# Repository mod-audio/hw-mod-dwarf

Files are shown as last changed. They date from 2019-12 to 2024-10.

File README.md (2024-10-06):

# hw-mod-dwarf

This repository contains the schematics and PCB design files for the MOD Dwarf hardware.

These files were created and can be improved with KiCAD, a free software Electronics CAD which is available at http://www.kicad.org/

This project should work with last revision of KiCad libraries and footprints available at https://github.com/KiCad/

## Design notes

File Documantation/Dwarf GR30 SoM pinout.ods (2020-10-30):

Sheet: GR-30 SoM pinout
Pin | Pin Name | Func1 | Func2 | Func3 | Func4 | Func5 | Drive Strength | Type | Pull
1 | I2C1_SDA | GPIO0_C3 | I2C1_SDA | UART3_RTS_M0 |  |  | 2 | I/O | down
2 | TP_RST | GPIO0_B4 | UART0_CTS |  |  |  | 2 | I/O | up
3 | IR_IN | GPIO0_C1 | UART3_RX_M0 | PWM3 |  |  | 2 | I/O | down
4 | SENSOR_INT | GPIO0_B7 | PWM0 | OTG_DRV |  |  | 2 | I/O | down
5 | PWM1 | GPIO0_C0 | UART3_TX_M0 | PWM1 |  |  | 2 | I/O | down
6 | VCC3V3_LCD
7 | LVDS_TX0N | LVDS_TX0N | MIPI_TX_D0N | LCDC_D11_M1 |  |  |  | A | N/A
8 | LVDS_TX0P | LVDS_TX0P | MIPI_TX_D0P | LCDC_D8_M1 |  |  |  | A | N/A
9 | LVDS_TX1N | LVDS_TX1N | MIPI_TX_D1N | LCDC_D1_M1 |  |  |  | A | N/A
10 | LVDS_TX1P | LVDS_TX1P | MIPI_TX_D1P | LCDC_D10_M1 |  |  |  | A | N/A
11 | LVDS_CLKN | LVDS_CLKN | MIPI_TC_CLKN | LCDC_D4_M1 |  |  |  | A | N/A
12 | LVDS_CLKP | LVDS_CLKP | MIPI_TC_CLKP | LCDC_D3_M1 |  |  |  | A | N/A
13 | LVDS_TX2N | LVDS_TX2N | MIPI_TX_D2N | LCDC_VSYNC_M1 |  |  |  | A | N/A
14 | LVDS_TX2P | LVDS_TX2P | MIPI_TX_D2P | LCDC_D5_M1 |  |  |  | A | N/A
15 | LVDS_TX3N | LVDS_TX3N | MIPI_TX_D3N | LCDC_HSYNC_M1 |  |  |  | A | N/A
16 | LVDS_TX3P | LVDS_TX3P | MIPI_TX_D3P | LCDC_DEN_M1 |  |  |  | A | N/A
17 | LCDC_CLK | GPIO3_A0 | LCDC_CLK |  |  |  | 8 | I/O | down
18 | LCDC_HSYNC | GPIO3_A1 | LCDC_HSYNC | CIF_D0_M1 | I2S2_2CH_MCLK | UART5_RX | 8 | I/O | down
19 | LCDC_VSYNC | GPIO3_A2 | LCDC_VSYNC | CIF_D1_M1 | I2S2_2CH_SCLK | UART5_TX | 8 | I/O | down
20 | LCDC_DEN | GPIO3_A3 | LCDC_DEN_M0 | CIF_D2_M1 | I2S2_2CH_LRCK_TXRX | UART5_CTS | 8 | I/O | down
21 | LCDC_D0 | GPIO3_A4 | LCDC_D0 |  |  |  | 8 | I/O | down
22 | LCDC_D1 | GPIO3_A5 | LCDC_D1_M0 | CIF_D3_M1 | I2S2_2CH_SDI | UART5_RTS | 8 | I/O | down
23 | LCDC_D2 | GPIO3_A6 | LCDC_D2 |  |  |  | 8 | I/O | down
24 | LCDC_D3 | GPIO3_A7 | LCDC_D3_M0 | CIF_D4_M1 | I2S2_2CH_SDO |  | 8 | I/O | down
25 | LCDC_D4 | GPIO3_B0 | LCDC_D4_M0 | CIF_D5_M1 | I2S0_8CH_SDI3 |  | 8 | I/O | down
26 | LCDC_D5 | GPIO3_B1 | LCDC_D5_M0 | CIF_D6_M1 | I2S0_8CH_SDI2 | SPI1_CSN0 | 8 | I/O | down
27 | LCDC_D6 | GPIO3_B2 | LCDC_D6 | SPI1_CSN1 |  |  | 8 | I/O | down
28 | LCDC_D7 | GPIO3_B3 | LCDC_D7 | I2S0_8CH_SDI1 |  |  | 8 | I/O | down
29 | LCDC_D8 | GPIO3_B4 | LCDC_D8_M0 | CIF_D7_M1 | I2S0_8CH_SCLKRX | SPI1_MOSI | 8 | I/O | down
30 | LCDC_D9 | GPIO3_B5 | LCDC_D9_M0 | I2S0_8CH_LRCKRX |  |  | 8 | I/O | down
31 | LCDC_D10 | GPIO3_B6 | LCDC_D10_M0 | CIF_D8_M1 | I2S0_8CH_SDO3 | SPI1_MISO | 8 | I/O | down
32 | LCDC_D11 | GPIO3_B7 | LCDC_D11_M0 | CIF_D9_M1 | I2S0_8CH_SDO2 | SPI1_CLK | 8 | I/O | down
33 | LCDC_D12 | GPIO3_C0 | LCDC_D12 | I2S0_8CH_SDO1 |  |  | 8 | I/O | down
34 | LCDC_D13 | GPIO3_C1 | LCDC_D13 | I2S0_8CH_MCLK |  |  | 8 | I/O | down
35 | LCDC_D14 | GPIO3_C2 | LCDC_D14 | PWM4 | I2S0_8CH_LRCKTX | TDM_FSYNC | 8 | I/O | down
36 | LCDC_D15 | GPIO3_C3 | LCDC_D15 | PWM5 | I2S0_8CH_SCLKTX | TDM_SCLK | 8 | I/O | down
37 | LCDC_D16 | GPIO3_C4 | LCDC_D16 | PWM6 | I2S0_8CH_SDO0 | TDM_SDO | 8 | I/O | down
38 | LCDC_D17 | GPIO3_C5 | LCDC_D17 | PWM7 | I2S0_8CH_SDI0 | TDM_SDI | 8 | I/O | down
39 | LCDC_D18 | GPIO3_C6 | LCDC_D18 | CIF_D10_M1 | PDM_CLK0_M0 |  | 8 | I/O | down
40 | LCDC_D19 | GPIO3_C7 | LCDC_D19 | CIF_D11_M1 | PDM_CLK1 |  | 8 | I/O | down
41 | LCDC_D20 | GPIO3_D0 | LCDC_D20 | CIF_CLKOUT_M1 | PDM_SDI1 |  | 8 | I/O | down
42 | LCDC_D21 | GPIO3_D1 | LCDC_D21 | CIF_VSYNC_M1 | PDM_SDI2 | ISP_PRELIGHT_TRIG | 8 | I/O | down
43 | LCDC_D22 | GPIO3_D2 | LCDC_D22 | CIF_HREF_M1 | PDM_SDI3 | ISP_FLASH_TRIG_OUT | 8 | I/O | down
44 | LCDC_D23 | GPIO3_D3 | LCDC_D23 | CIF_CLKIN_M1 | PDM_SDI0_M0 | ISP_FLASH_TRIG_IN | 8 | I/O | down
45 | GPIO0_B5 | GPIO0_B5 | UART0_RTS | TEST_CLK1 |  |  | 2 | I/O | up
46 | GPIO2_B4 | GPIO2_B4 | CIF_D0_M0 | UART2_TX_M1 |  |  | 2 | I/O | down
47 | GPIO0_A0 | GPIO0_A0 | REF_CLKO |  |  |  | 4 | I/O | down
48 | UART1_CTS | GPIO1_C2 | UART1_CTS |  |  |  | 4 | I/O | up
49 | UART1_RXD | GPIO1_C0 | UART1_RX |  |  |  | 4 | I/O | up
50 | UART1_TXD | GPIO1_C1 | UART1_TX |  |  |  | 4 | I/O | up
51 | UART1_RTS | GPIO1_C3 | UART1_RTS |  |  |  | 4 | I/O | up
52 | CLKOUT_32K | GPIO0_C4 | CLKIO_32K |  |  |  | 2 | I/O | Z
53 | SDIO_D1 | GPIO1_C7 | SDMMC1_D1 |  |  |  | 8 | I/O | up
54 | SDIO_D0 | GPIO1_C6 | SDMMC1_D0 |  |  |  | 8 | I/O | up
55 | SDIO_CLK | GPIO1_C5 | SDMMC1_CLK |  |  |  | 8 | I/O | up
56 | SDIO_CMD | GPIO1_C4 | SDMMC1_CMD |  |  |  | 8 | I/O | up
57 | SDIO_D3 | GPIO1_D1 | SDMMC1_D3 |  |  |  | 8 | I/O | up
58 | SDIO_D2 | GPIO1_D0 | SDMMC1_D2 |  |  |  | 8 | I/O | up
59 | BT_WAKE_HOST | GPIO0_B3 | UART0_RX |  |  |  | 2 | I/O | down
60 | WIFI_WAKE_HOST | GPIO0_B2 | UART0_TX |  |  |  | 2 | I/O | down
61 | HOST_WAKE_BT | GPIO0_A1 |  |  |  |  | 2 | I/O | down
62 | BT_REG_ON | GPIO2_B0 | CIF_VSYNC_M0 |  |  |  | 2 | I/O | down
63 | WIFI_REG_ON | GPIO0_A2 |  |  |  |  | 2 | I/O | down
64 | I2C0_SCL_PMIC | GPIO0_B0 | I2C0_SCL |  |  |  | 2 | I/O | up
65 | I2C0_SDA_PMIC | GPIO0_B1 | I2C0_SDA |  |  |  | 2 | I/O | up
66 | PDM_CLK0 | GPIO3_C6 | LCDC_D18 | CIF_D10_M1 | PDM_CLK0_M0 |  | 8 | I/O | down
67 | I2S1_SDI | GPIO2_C5 | I2S1_2CH_SDI | PDM_SDIO_M1 |  |  | 4 | I/O | down
68 | I2S1_SCLK | GPIO2_C2 | I2S1_2CH__SCLK |  |  |  | 4 | I/O | down
69 | I2S1_MCLK | GPIO2_C3 | I2S1_2CH_MCLK |  |  |  | 4 | I/O | down
70 | I2S1_SDO | GPIO2_C4 | I2S1_2CH_SDO |  |  |  | 4 | I/O | down
71 | I2S1_LRCK | GPIO2_C1 | I2S1_2CH_LRCK_TXRX |  |  |  | 4 | I/O | down
72 | GND
73 | MIC1_IN | audio in 1 |  |  |  |  |  | A | N/A
74 | MIC2_IN | audio in 2 |  |  |  |  |  | A | N/A
75 | SPKRP_OUT | speaker out + |  |  |  |  |  | A | N/A
76 | SPKRN_OUT | speaker out - |  |  |  |  |  | A | N/A
77 | HPL | headphone left |  |  |  |  |  | A | N/A
78 | HP_SNS | headphone GND |  |  |  |  |  | A | N/A
79 | HPR | headphone right |  |  |  |  |  | A | N/A
80 | GND
81 | MIPI_CSI_D3N |  |  |  |  |  | N/A | Camera | N/A
82 | MIPI_CSI_D3P |  |  |  |  |  | N/A | Camera | N/A
83 | MIPI_CSI_D2N |  |  |  |  |  | N/A | Camera | N/A
84 | MIPI_CSI_D2P |  |  |  |  |  | N/A | Camera | N/A
85 | MIPI_CSI_CLKN |  |  |  |  |  | N/A | Camera | N/A
86 | MIPI_CSI_CLKP |  |  |  |  |  | N/A | Camera | N/A
87 | MIPI_CSI_D1P |  |  |  |  |  | N/A | Camera | N/A
88 | MIPI_CSI_D1N |  |  |  |  |  | N/A | Camera | N/A
89 | MIPI_CSI_D0P |  |  |  |  |  | N/A | Camera | N/A
90 | MIPI_CSI_D0N |  |  |  |  |  | N/A | Camera | N/A
91 | CIF_PDN0 | GPIO2_B6 | CIF_D1_M0 | UART2_RX_M1 |  |  | 2 | I/O | up
92 | I2C2_SDA | GPIO2_C0 | CIF_D11_M0 | I2C2_SDA |  |  | 2 | I/O | up
93 | I2C2_SCL | GPIO2_B7 | CIF_D10_M0 | I2C2_SCL |  |  | 2 | I/O | up
94 | MIPI_CLKO | GPIO2_B3 | CIF_CLKO_M0 | CLK_OUT_ETHERNET |  |  | 2 | I/O | down
95 | VCC2V8_DVP
96 | VCC1V8_DVP
97 | MAC_MDC | GPIO2_B1 | CIF_HREF_M0 | RMII_MDC |  |  | 4 | I/O | down
98 | RMII_RST | GPIO2_B5 | PWM2 |  |  |  | 4 | I/O | down
99 | RMII_CLK | GPIO2_B2 | CIF_CLKI_M0 | RMII_CLK |  |  | 4 | I/O | down
100 | RMII_MDIO | GPIO2_A7 | CIF_D9_M0 | RMII_MDIO |  |  | 4 | I/O | down
101 | RMII_RXDV | GPIO2_A6 | CIF_D8_M0 | RMII_RXDV |  |  | 4 | I/O | down
102 | RMII_RXER | GPIO2_A5 | CIF_D7_M0 | RMII_RXER |  |  | 4 | I/O | down
103 | RMII_RXD1 | GPIO2_A4 | CIF_D6_M0 | RMII_RXD1 |  |  | 4 | I/O | down
104 | RMII_TXD1 | GPIO2_A1 | CIF_D3_M0 | RMII_TXD1 |  |  | 4 | I/O | down
105 | RMII_RXD0 | GPIO2_A3 | CIF_D5_M0 | RMII_RXD0 |  |  | 4 | I/O | down
106 | RMII_TXD0 | GPIO2_A2 | CIF_D4_M0 | RMII_TXD0 |  |  | 4 | I/O | down
107 | RMII_TXEN | GPIO2_A0 | CIF_D2_M0 | RMII_TXEN |  |  | 8 | I/O | down
108 | GND
109 | GND
110 | GND
111 | VCC5V0_SYS
112 | VCC5V0_SYS
113 | EXT_EN
114 | VCC5V0_HOST
115 | VCC_RTC
116 | VCC3V3_SYS
117 | VCC3V30_PMU
118 | VCC1V8
119 | OTG_DP
120 | OTG_DM
121 | USB_ID
122 | USB_DET
123 | USB_HOST_DM
124 | USB_HOST_DP
125 | SDMMC0_D2 | GPIO1_D4 | SDMMC0_D2 | UART4_RX | JTAG_TCK |  | 8 | I/O | up
126 | SDMMC0_D3 | GPIO1_D5 | SDMMC0_D3 | UART4_TX | JTAG_TMS |  | 8 | I/O | up
127 | VCC_SD
128 | SDMMC0_CMD | GPIO1_D7 | SDMMC0_CMD | UART4_RTS |  |  | 8 | I/O | up
129 | SDMMC0_CLK | GPIO1_D6 | SDMMC0_CLKO | UART4_CTS | TEST_CLKO |  | 8 | I/O | up
130 | SDMMC0_D0 | GPIO1_D2 | SDMMC0_D0 | UART2_TX_M0 |  |  | 8 | I/O | up
131 | SDMMC0_D1 | GPIO1_D3 | SDMMC0_D1 | UART2_RX_M0 |  |  | 8 | I/O | up
132 | SDMMC0_DET | GPIO0_A3 | SDMMC0_DETN |  |  |  | 8 | I/O | up
133 | FLASH_CS0 | GPIO1_B0 | FLASH_CS0 |  |  |  | 8 | I/O | down
134 | FLASH_CLE | GPIO1_B4 | FLASH_CLE | UART3_CTS_M1 | SPI0_MOSI | I2C3_SDA | 8 | I/O | down
135 | FLASH_WRN | GPIO1_B5 | FLASH_WRN | UART3_RTS_M1 | SPI0_MISO | I2C3_SCL | 8 | I/O | up
136 | FLASH_CS1 | GPIO1_B6 | FLASH_CS1 | UART3_TX_M1 | SPI0_CSN |  | 8 | I/O | up
137 | FLASH_RDN | GPIO1_B7 | FLASH_RDN | UART3_RX_M1 | SPI0_CLK |  | 8 | I/O | up
138 | RESET_KEY
139 | POWER_KEY
140 | ADC2
141 | ADC1
142 | ADC0
143 | TP_INT | GPIO0_A5 |  |  |  |  | 2 | I/O | up
144 | I2C1_SCL | GPIO0_C2 | I2C1_SCL | UART3_CTS_M0 |  |  | 2 | I/O | down
 | Ground
 | Power output
 | Power input

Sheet: Dwarf connections
Pin | Type | Function
PM_LEDS_SDA | I2C | I2C data line, used for UID chip and LED peakmeter IC
PM_LEDS_SCL | I2C | I2C clock line, used for UID chip and LED peakmeter IC
PM_LEDS_OE | GPIO | Ouptut Enable for the peakmeter LED IC
CLI_UART_RX | UART | Command Line interface, Linux debug serial RX
CLI_UART_TX | UART | Command Line interface, Linux debug serial TX
HMI_ISP_ENABLE | GPIO | In System Programmer enable, a GPIO to out the HMI in flashing mode
HMI_ISP_RESET | GPIO | HMI reset pin
HMI_ISP_UART_TX | UART | HMI data serial TX
HMI_ISP_UART_RX | UART | HMI data serial RX
MIDI_UART_TX | UART | MIDI serial TX
MIDI_UART_RX | UART | MIDI serial RX
UBOOT_BUTTON | GPIO | a button that is detected during uboot to boot an alternate mode
POWER_BUTTON | GPIO | an exposed SoM button to trigger the SoM to boot
RESET_BUTTON | GPIO | an exposed SoM button to trigger the SoM to reset
USB_DEV_DET | GPIO | USB device detect, detects if a USB is present
USB_DEV_DN | USB | USB device data negative
USB_DEV_DP | USB | USB device data positive
OUT1_DETECT | GPIO | audio out 1 detect, a pulldown whenever a jack is inserted
OUT2_DETECT | GPIO | audio out 2 detect, a pulldown whenever a jack is inserted
IN1_DETECT | GPIO | audio in 1 detect, a pulldown whenever a jack is inserted
IN2_DETECT | GPIO | audio in 2 detect, a pulldown whenever a jack is inserted
USB_HOST_DRV | GPIO | USB host drive, enables the 5V power line of the USB host
USB_HOST_DN | USB | USB host data negative
USB_HOST_DP | USB | USB host data positive
CHAIN_UART_RE | GPIO | Control chain read enable, enables the CC transmision IC read
CHAIN_UART_RX | UART | Control Chain serial RX
CHAIN_UART_DE | GPIO | Control chain drive enable, enables the CC transmision IC write
CHAIN_UART_TX | UART | Control chain serial TX
CODEC_RESET | GPIO | Resets the audio codec
CODEC_I2C_SCL | I2C | I2C data line, used for codec settings
CODEC_I2C_SDA | I2C | I2C clock line, used for codec settings
CODEC_I2S_MCLK | I2S | I2S master clock line
CODEC_I2S_LRCK | I2S | I2S frame clock
CODEC_I2S_BCLK | I2S | I2S bit clock
CODEC_I2S_SDOUT | I2S | I2S data output
CODEC_I2S_SDIN | I2S | I2S data input
IN1_GC2 | GPIO | GPIO that sets extra gain on input 1
IN1_GC1 | GPIO | GPIO that sets extra gain on input 1
IN2_GC1 | GPIO | GPIO that sets extra gain on input 2
IN2_GC2 | GPIO | GPIO that sets extra gain on input 2
HP_CLOCK | GPIO | headphone driver IC clock for setting the volume
HP_UP/DN | GPIO | headphone driver IC data for setting the volume
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

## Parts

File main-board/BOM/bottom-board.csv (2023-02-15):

Source: | /home/jan/MOD/hw-mod-dwarf/main-board/PCB Source/bottom-board/bottom-board.kicad_sch
Date: | Wed 15 Feb 2023 05:39:18 PM CET
Tool: | Eeschema 6.0.10-86aedd382b~118~ubuntu22.04.1
Generator: | /usr/share/kicad/plugins/bom_csv_grouped_by_value.py
Component Count: | 318
Individual Components:
Item | Qty | Reference(s) | Value | LibPart | Footprint | Datasheet | Field4 | Field5 | Field6 | Field7 | Field8 | MPN | MPN2
 |  | C1 | 100uF | bottom-board-rescue:CP_Small | Capacitor_SMD:CP_Elec_6.3x7.7 |  |  |  |  |  |  | 107SML016M
 |  | C2 | 10uF | bottom-board-rescue:CP_Small | Capacitor_SMD:CP_Elec_4x5.7 |  |  |  |  |  |  | EEE-HB1C100R
 |  | C3 | 1000uF | bottom-board-rescue:CP_Small | Capacitor_SMD:CP_Elec_10x10.5 |  |  |  |  |  |  | UCM1C102MNL1GS
 |  | C4 | 1nF | bottom-board-rescue:C_Small | Capacitor_SMD:C_0603_1608Metric |  |  |  |  |  |  | C0603X7R500-102KNP
 |  | C5 | 100nF | bottom-board-rescue:C_Small | Capacitor_SMD:C_0603_1608Metric |  |  |  |  |  |  | GCM188R71C104KA37D
 |  | C6 | 100nF | bottom-board-rescue:C_Small | Capacitor_SMD:C_0603_1608Metric |  |  |  |  |  |  | GCM188R71C104KA37D
 |  | C7 | 100nF | bottom-board-rescue:C_Small | Capacitor_SMD:C_0603_1608Metric |  |  |  |  |  |  | GCM188R71C104KA37D
 |  | C8 | 10uF | bottom-board-rescue:C_Small-Device | Capacitor_SMD:C_0805_2012Metric |  |  |  |  |  |  | GRM219R61E106KA12D
 |  | C9 | 100nF | bottom-board-rescue:C_Small | Capacitor_SMD:C_0603_1608Metric |  |  |  |  |  |  | GCM188R71C104KA37D
 |  | C10 | 100nF | bottom-board-rescue:C_Small | Capacitor_SMD:C_0603_1608Metric |  |  |  |  |  |  | GCM188R71C104KA37D
 |  | C11 | 100nF | bottom-board-rescue:C_Small | Capacitor_SMD:C_0603_1608Metric |  |  |  |  |  |  | GCM188R71C104KA37D
 |  | C12 | 100nF | bottom-board-rescue:C_Small | Capacitor_SMD:C_0603_1608Metric |  |  |  |  |  |  | GCM188R71C104KA37D
 |  | C13 | 100nF | bottom-board-rescue:C_Small | Capacitor_SMD:C_0603_1608Metric |  |  |  |  |  |  | GCM188R71C104KA37D
 |  | C14 | 100nF | bottom-board-rescue:C_Small | Capacitor_SMD:C_0603_1608Metric |  |  |  |  |  |  | GCM188R71C104KA37D
 |  | C15 | 2.2nF | bottom-board-rescue:C_Small | Capacitor_SMD:C_0603_1608Metric |  |  |  |  |  |  | GRM1885C1H222JA01D
 |  | C16 | 2.2nF | bottom-board-rescue:C_Small | Capacitor_SMD:C_0603_1608Metric |  |  |  |  |  |  | GRM1885C1H222JA01D
 |  | C17 | 100nF | bottom-board-rescue:C_Small | Capacitor_SMD:C_0603_1608Metric |  |  |  |  |  |  | GCM188R71C104KA37D
 |  | C18 | 47uF | bottom-board-rescue:CP_Small | Capacitor_SMD:CP_Elec_5x5.4 |  |  |  |  |  |  | EDK476M016A9DAA
 |  | C19 | 100nF | bottom-board-rescue:C_Small | Capacitor_SMD:C_0603_1608Metric |  |  |  |  |  |  | GCM188R71C104KA37D
 |  | C20 | 10uF | bottom-board-rescue:C_Small | Capacitor_SMD:C_0805_2012Metric |  |  |  |  |  |  | GRM219R61E106KA12D
 |  | C21 | 100pF | bottom-board-rescue:C_Small | Capacitor_SMD:C_0603_1608Metric |  |  |  |  |  |  | C0603C101J3GACTU
 |  | C22 | 100nF | bottom-board-rescue:C_Small | Capacitor_SMD:C_0603_1608Metric |  |  |  |  |  |  | GCM188R71C104KA37D
 |  | C23 | 100pF | bottom-board-rescue:C_Small | Capacitor_SMD:C_0603_1608Metric |  |  |  |  |  |  | C0603C101J3GACTU
 |  | C24 | 1uF | bottom-board-rescue:C_Small | Capacitor_SMD:C_0603_1608Metric |  |  |  |  |  |  | TMK107B7105KA-T
 |  | C25 | 10uF | bottom-board-rescue:C_Small | Capacitor_SMD:C_0805_2012Metric |  |  |  |  |  |  | GRM219R61E106KA12D
 |  | C26 | 1uF | bottom-board-rescue:C_Small | Capacitor_SMD:C_0603_1608Metric |  |  |  |  |  |  | TMK107B7105KA-T
 |  | C27 | 1uF | bottom-board-rescue:C_Small | Capacitor_SMD:C_0603_1608Metric |  |  |  |  |  |  | TMK107B7105KA-T
 |  | C28 | 100pF | bottom-board-rescue:C_Small | Capacitor_SMD:C_0603_1608Metric |  |  |  |  |  |  | C0603C101J3GACTU
 |  | C29 | 100pF | bottom-board-rescue:C_Small | Capacitor_SMD:C_0603_1608Metric |  |  |  |  |  |  | C0603C101J3GACTU
 |  | C30 | 22uF | bottom-board-rescue:C_Small | Capacitor_SMD:C_0805_2012Metric |  |  |  |  |  |  | CL21A226MPQNNNE
 |  | C31 | 100nF | bottom-board-rescue:C_Small | Capacitor_SMD:C_0603_1608Metric |  |  |  |  |  |  | GCM188R71C104KA37D
 |  | C32 | 470uF | bottom-board-rescue:CP_Small | Capacitor_SMD:CP_Elec_8x10.5 |  |  |  |  |  |  | UCW1C471MNL1GS
 |  | C33 | 10uF | bottom-board-rescue:CP_Small | Capacitor_SMD:CP_Elec_4x5.7 |  |  |  |  |  |  | EEE-HB1C100R
 |  | C34 | 10uF | bottom-board-rescue:CP_Small | Capacitor_SMD:CP_Elec_4x5.7 |  |  |  |  |  |  | EEE-HB1C100R
 |  | C35 | 100nF | bottom-board-rescue:C_Small | Capacitor_SMD:C_0603_1608Metric |  |  |  |  |  |  | GCM188R71C104KA37D
 |  | C36 | 100nF | bottom-board-rescue:C_Small | Capacitor_SMD:C_0603_1608Metric |  |  |  |  |  |  | GCM188R71C104KA37D
 |  | C37 | 10uF | bottom-board-rescue:C_Small | Capacitor_SMD:C_0805_2012Metric |  |  |  |  |  |  | GRM219R61E106KA12D
 |  | C38 | 100nF | bottom-board-rescue:C_Small | Capacitor_SMD:C_0603_1608Metric |  |  |  |  |  |  | GCM188R71C104KA37D
 |  | C39 | 100nF | bottom-board-rescue:C_Small | Capacitor_SMD:C_0603_1608Metric |  |  |  |  |  |  | GCM188R71C104KA37D
 |  | C40 | 100pF | bottom-board-rescue:C_Small | Capacitor_SMD:C_0603_1608Metric |  |  |  |  |  |  | C0603C101J3GACTU
 |  | C41 | 10uF | bottom-board-rescue:C_Small | Capacitor_SMD:C_0805_2012Metric |  |  |  |  |  |  | GRM219R61E106KA12D
 |  | C42 | 47uF | bottom-board-rescue:CP_Small | Capacitor_SMD:CP_Elec_5x5.4 |  |  |  |  |  |  | EDK476M016A9DAA
 |  | C43 | 100nF | bottom-board-rescue:C_Small | Capacitor_SMD:C_0603_1608Metric |  |  |  |  |  |  | GCM188R71C104KA37D
 |  | C44 | 100pF | bottom-board-rescue:C_Small | Capacitor_SMD:C_0603_1608Metric |  |  |  |  |  |  | C0603C101J3GACTU
 |  | C45 | 10uF | bottom-board-rescue:C_Small | Capacitor_SMD:C_0805_2012Metric |  |  |  |  |  |  | GRM219R61E106KA12D
 |  | C46 | 100pF | bottom-board-rescue:C_Small | Capacitor_SMD:C_0603_1608Metric |  |  |  |  |  |  | C0603C101J3GACTU
 |  | C47 | 100pF | bottom-board-rescue:C_Small | Capacitor_SMD:C_0603_1608Metric |  |  |  |  |  |  | C0603C101J3GACTU
 |  | C48 | 100nF | bottom-board-rescue:C_Small | Capacitor_SMD:C_0603_1608Metric |  |  |  |  |  |  | GCM188R71C104KA37D
 |  | C49 | 10uF | bottom-board-rescue:C_Small | Capacitor_SMD:C_0805_2012Metric |  |  |  |  |  |  | GRM219R61E106KA12D
 |  | C50 | 100nF | bottom-board-rescue:C_Small | Capacitor_SMD:C_0603_1608Metric |  |  |  |  |  |  | GCM188R71C104KA37D
 |  | C51 | 100nF | bottom-board-rescue:C_Small | Capacitor_SMD:C_0603_1608Metric |  |  |  |  |  |  | GCM188R71C104KA37D
 |  | C52 | 100nF | bottom-board-rescue:C_Small | Capacitor_SMD:C_0603_1608Metric |  |  |  |  |  |  | GCM188R71C104KA37D
 |  | C53 | 100nF | bottom-board-rescue:C_Small | Capacitor_SMD:C_0603_1608Metric |  |  |  |  |  |  | GCM188R71C104KA37D
 |  | C54 | 100nF | bottom-board-rescue:C_Small | Capacitor_SMD:C_0603_1608Metric |  |  |  |  |  |  | GCM188R71C104KA37D
 |  | C55 | 100pF | bottom-board-rescue:C_Small | Capacitor_SMD:C_0603_1608Metric |  |  |  |  |  |  | C0603C101J3GACTU
 |  | C56 | 100pF | bottom-board-rescue:C_Small | Capacitor_SMD:C_0603_1608Metric |  |  |  |  |  |  | C0603C101J3GACTU
 |  | C57 | 47uF | bottom-board-rescue:CP_Small | Capacitor_SMD:CP_Elec_5x5.4 |  |  |  |  |  |  | EDK476M016A9DAA
 |  | C58 | 22uF | bottom-board-rescue:C_Small | Capacitor_SMD:C_0805_2012Metric |  |  |  |  |  |  | CL21A226MPQNNNE
 |  | C59 | 100nF | bottom-board-rescue:C_Small | Capacitor_SMD:C_0603_1608Metric |  |  |  |  |  |  | GCM188R71C104KA37D
 |  | C60 | 100nF | bottom-board-rescue:C_Small | Capacitor_SMD:C_0603_1608Metric |  |  |  |  |  |  | GCM188R71C104KA37D
 |  | C61 | 10uF | bottom-board-rescue:CP_Small | Capacitor_SMD:CP_Elec_4x5.7 |  |  |  |  |  |  | EEE-HB1C100R
 |  | C62 | 100nF | bottom-board-rescue:C_Small | Capacitor_SMD:C_0603_1608Metric |  |  |  |  |  |  | GCM188R71C104KA37D
 |  | C63 | 10uF | bottom-board-rescue:CP_Small | Capacitor_SMD:CP_Elec_4x5.7 |  |  |  |  |  |  | EEE-HB1C100R
 |  | C64 | 10uF | bottom-board-rescue:CP_Small | Capacitor_SMD:CP_Elec_4x5.7 |  |  |  |  |  |  | EEE-HB1C100R
 |  | C65 | 10uF | bottom-board-rescue:CP_Small | Capacitor_SMD:CP_Elec_4x5.7 |  |  |  |  |  |  | EEE-HB1C100R
 |  | C66 | 10uF | bottom-board-rescue:CP_Small | Capacitor_SMD:CP_Elec_4x5.7 |  |  |  |  |  |  | EEE-HB1C100R
 |  | C67 | 10uF | bottom-board-rescue:C_Small | Capacitor_SMD:C_0805_2012Metric |  |  |  |  |  |  | GRM219R61E106KA12D
 |  | C68 | 100nF | bottom-board-rescue:C_Small | Capacitor_SMD:C_0603_1608Metric |  |  |  |  |  |  | GCM188R71C104KA37D
 |  | C69 | 10uF | bottom-board-rescue:C_Small | Capacitor_SMD:C_0805_2012Metric |  |  |  |  |  |  | GRM219R61E106KA12D
 |  | C70 | 100uF | bottom-board-rescue:CP_Small | Capacitor_SMD:CP_Elec_6.3x7.7 |  |  |  |  |  |  | 107SML016M
 |  | C71 | 100uF | bottom-board-rescue:CP_Small | Capacitor_SMD:CP_Elec_6.3x7.7 |  |  |  |  |  |  | 107SML016M
 |  | C72 | 47uF | bottom-board-rescue:CP_Small | Capacitor_SMD:CP_Elec_5x5.4 |  |  |  |  |  |  | EDK476M016A9DAA
 |  | C73 | 100nF | bottom-board-rescue:C_Small | Capacitor_SMD:C_0603_1608Metric |  |  |  |  |  |  | GCM188R71C104KA37D
 |  | C74 | 47uF | bottom-board-rescue:CP_Small | Capacitor_SMD:CP_Elec_5x5.4 |  |  |  |  |  |  | EDK476M016A9DAA
 |  | C75 | 100nF | bottom-board-rescue:C_Small | Capacitor_SMD:C_0603_1608Metric |  |  |  |  |  |  | GCM188R71C104KA37D
 |  | C76 | 10uF | bottom-board-rescue:C_Small | Capacitor_SMD:C_0805_2012Metric |  |  |  |  |  |  | GRM219R61E106KA12D
 |  | C77 | 100nF | bottom-board-rescue:C_Small | Capacitor_SMD:C_0603_1608Metric |  |  |  |  |  |  | GCM188R71C104KA37D
 |  | C78 | 10uF | bottom-board-rescue:C_Small | Capacitor_SMD:C_0805_2012Metric |  |  |  |  |  |  | GRM219R61E106KA12D
 |  | C79 | 100nF | bottom-board-rescue:C_Small | Capacitor_SMD:C_0603_1608Metric |  |  |  |  |  |  | GCM188R71C104KA37D
 |  | C80 | 10uF | bottom-board-rescue:C_Small | Capacitor_SMD:C_0805_2012Metric |  |  |  |  |  |  | GRM219R61E106KA12D
 |  | C81 | 100nF | bottom-board-rescue:C_Small | Capacitor_SMD:C_0603_1608Metric |  |  |  |  |  |  | GCM188R71C104KA37D
 |  | C82 | 100nF | bottom-board-rescue:C_Small | Capacitor_SMD:C_0603_1608Metric |  |  |  |  |  |  | GCM188R71C104KA37D
 |  | C83 | 47uF | bottom-board-rescue:CP_Small | Capacitor_SMD:CP_Elec_5x5.4 |  |  |  |  |  |  | EDK476M016A9DAA
 |  | C84 | 47uF | bottom-board-rescue:CP_Small | Capacitor_SMD:CP_Elec_5x5.4 |  |  |  |  |  |  | EDK476M016A9DAA
 |  | C85 | 100nF | bottom-board-rescue:C_Small | Capacitor_SMD:C_0603_1608Metric |  |  |  |  |  |  | GCM188R71C104KA37D
 |  | C86 | 100nF | bottom-board-rescue:C_Small | Capacitor_SMD:C_0603_1608Metric |  |  |  |  |  |  | GCM188R71C104KA37D
 |  | C87 | 100nF | bottom-board-rescue:C_Small | Capacitor_SMD:C_0603_1608Metric |  |  |  |  |  |  | GCM188R71C104KA37D
 |  | C88 | 10uF | bottom-board-rescue:CP_Small | Capacitor_SMD:CP_Elec_4x5.7 |  |  |  |  |  |  | EEE-HB1C100R
 |  | C89 | 10uF | bottom-board-rescue:CP_Small | Capacitor_SMD:CP_Elec_4x5.7 |  |  |  |  |  |  | EEE-HB1C100R
 |  | C90 | 100pF | bottom-board-rescue:C_Small | Capacitor_SMD:C_0603_1608Metric |  |  |  |  |  |  | C0603C101J3GACTU
 |  | C91 | 100pF | bottom-board-rescue:C_Small | Capacitor_SMD:C_0603_1608Metric |  |  |  |  |  |  | C0603C101J3GACTU
 |  | C92 | 1nF | bottom-board-rescue:C_Small | Capacitor_SMD:C_0603_1608Metric |  |  |  |  |  |  | C0603X7R500-102KNP
 |  | C93 | 1nF | bottom-board-rescue:C_Small | Capacitor_SMD:C_0603_1608Metric |  |  |  |  |  |  | C0603X7R500-102KNP
 |  | C94 | 100nF | bottom-board-rescue:C_Small | Capacitor_SMD:C_0603_1608Metric |  |  |  |  |  |  | DO NOT PLACE
 |  | C95 | 100nF | bottom-board-rescue:C_Small | Capacitor_SMD:C_0603_1608Metric |  |  |  |  |  |  | GCM188R71C104KA37D
 |  | C96 | 10uF | bottom-board-rescue:C_Small | Capacitor_SMD:C_0805_2012Metric |  |  |  |  |  |  | GRM219R61E106KA12D
 |  | C97 | 1uF | bottom-board-rescue:C_Small | Capacitor_SMD:C_0603_1608Metric |  |  |  |  |  |  | TMK107B7105KA-T
 |  | C98 | 100nF | bottom-board-rescue:C_Small | Capacitor_SMD:C_0603_1608Metric |  |  |  |  |  |  | GCM188R71C104KA37D
 |  | C99 | 22uF | bottom-board-rescue:C_Small | Capacitor_SMD:C_0805_2012Metric |  |  |  |  |  |  | CL21A226MPQNNNE
 |  | C100 | 100nF | bottom-board-rescue:C_Small | Capacitor_SMD:C_0603_1608Metric |  |  |  |  |  |  | GCM188R71C104KA37D
 |  | C101 | 22uF | bottom-board-rescue:C_Small | Capacitor_SMD:C_0805_2012Metric |  |  |  |  |  |  | CL21A226MPQNNNE
 |  | C102 | 100nF | bottom-board-rescue:C_Small | Capacitor_SMD:C_0603_1608Metric |  |  |  |  |  |  | GCM188R71C104KA37D
 |  | C103 | 1uF | bottom-board-rescue:C_Small | Capacitor_SMD:C_0603_1608Metric |  |  |  |  |  |  | TMK107B7105KA-T
 |  | C104 | 100nF | bottom-board-rescue:C_Small | Capacitor_SMD:C_0603_1608Metric |  |  |  |  |  |  | GCM188R71C104KA37D
 |  | C105 | 1uF | bottom-board-rescue:C_Small | Capacitor_SMD:C_0603_1608Metric |  |  |  |  |  |  | TMK107B7105KA-T
 |  | C106 | 100nF | bottom-board-rescue:C_Small | Capacitor_SMD:C_0603_1608Metric |  |  |  |  |  |  | GCM188R71C104KA37D
 |  | C107 | 1000uF | bottom-board-rescue:CP_Small | Capacitor_SMD:CP_Elec_10x10.5 |  |  |  |  |  |  | UCM1C102MNL1GS
 |  | C108 | 1nF | bottom-board-rescue:C_Small | Capacitor_SMD:C_0603_1608Metric |  |  |  |  |  |  | C0603X7R500-102KNP
 |  | C109 | 100nF | bottom-board-rescue:C_Small-Device | Capacitor_SMD:C_0603_1608Metric |  |  |  |  |  |  | GCM188R71C104KA37D
 |  | C110 | 10uF | bottom-board-rescue:C_Small-Device | Capacitor_SMD:C_0805_2012Metric |  |  |  |  |  |  | GRM219R61E106KA12D
 |  | C111 | 1uF | bottom-board-rescue:C_Small | Capacitor_SMD:C_1210_3225Metric |  |  |  |  |  |  | FCA1210C105M-G2
 |  | C112 | 1uF | bottom-board-rescue:C_Small | Capacitor_SMD:C_1210_3225Metric |  |  |  |  |  |  | FCA1210C105M-G2
 |  | D1 | RSX205LAM30TR | bottom-board-rescue:D_Schottky-Device | Diode_SMD:D_SOD-128 |  |  |  |  |  |  | RSX205LAM30TR
 |  | D2 | RSX205LAM30TR | bottom-board-rescue:D_Schottky-Device | Diode_SMD:D_SOD-128 |  |  |  |  |  |  | RSX205LAM30TR
 |  | D3 | BAT54S | bottom-board-rescue:BAT54S-Diode | Package_TO_SOT_SMD:SOT-23 | https://www.diodes.com/assets/Datasheets/ds11005.pdf |  |  |  |  |  | BAT54SFILM
 |  | D4 | BAT54S | bottom-board-rescue:BAT54S-Diode | Package_TO_SOT_SMD:SOT-23 | https://www.diodes.com/assets/Datasheets/ds11005.pdf |  |  |  |  |  | BAT54SFILM
 |  | D5 | 1N4148 | bottom-board-rescue:1N4148-Diode | Diode_SMD:D_SOD-323_HandSoldering | https://assets.nexperia.com/documents/data-sheet/1N4148_1N4448.pdf |  |  |  |  |  | 1N4148WS
 |  | D6 | 1N4148 | bottom-board-rescue:1N4148-Diode | Diode_SMD:D_SOD-323_HandSoldering | https://assets.nexperia.com/documents/data-sheet/1N4148_1N4448.pdf |  |  |  |  |  | 1N4148WS
 |  | D7 | TSSA3U45 R3G | bottom-board-rescue:D_Shockley-Device | Diode_SMD:D_MELF |  |  |  |  |  |  | TSSA3U45 R3G
 |  | D8 | 1N4148 | bottom-board-rescue:1N4148-Diode | Diode_SMD:D_SOD-323_HandSoldering | https://assets.nexperia.com/documents/data-sheet/1N4148_1N4448.pdf |  |  |  |  |  | 1N4148WS
 |  | D9 | 1N4148 | bottom-board-rescue:1N4148-Diode | Diode_SMD:D_SOD-323_HandSoldering | https://assets.nexperia.com/documents/data-sheet/1N4148_1N4448.pdf |  |  |  |  |  | 1N4148WS
 |  | D10 | BAT54S | bottom-board-rescue:BAT54S-Diode | Package_TO_SOT_SMD:SOT-23 | https://www.diodes.com/assets/Datasheets/ds11005.pdf |  |  |  |  |  | BAT54SFILM
 |  | D11 | BAT54S | bottom-board-rescue:BAT54S-Diode | Package_TO_SOT_SMD:SOT-23 | https://www.diodes.com/assets/Datasheets/ds11005.pdf |  |  |  |  |  | BAT54SFILM
 |  | D12 | BAT54S | bottom-board-rescue:BAT54S-Diode | Package_TO_SOT_SMD:SOT-23 | https://www.diodes.com/assets/Datasheets/ds11005.pdf |  |  |  |  |  | BAT54SFILM
 |  | D13 | PRTR5V0U2X | bottom-board-rescue:PRTR5V0U2X | Package_TO_SOT_SMD:SOT-143 |  |  |  |  |  |  | PRTR5V0U2X,215
 |  | D14 | PRTR5V0U2X | bottom-board-rescue:PRTR5V0U2X | Package_TO_SOT_SMD:SOT-143 |  |  |  |  |  |  | PRTR5V0U2X,215
 |  | D15 | 1N4148 | bottom-board-rescue:1N4148-Diode | Diode_SMD:D_SOD-323_HandSoldering | https://assets.nexperia.com/documents/data-sheet/1N4148_1N4448.pdf |  |  |  |  |  | 1N4148WS
 |  | D16 | 1N4148 | bottom-board-rescue:1N4148-Diode | Diode_SMD:D_SOD-323_HandSoldering | https://assets.nexperia.com/documents/data-sheet/1N4148_1N4448.pdf |  |  |  |  |  | 1N4148WS
 |  | D17 | BAT54S | bottom-board-rescue:BAT54S-Diode | Package_TO_SOT_SMD:SOT-23 | https://www.diodes.com/assets/Datasheets/ds11005.pdf |  |  |  |  |  | BAT54SFILM
 |  | D18 | BAT54S | bottom-board-rescue:BAT54S-Diode | Package_TO_SOT_SMD:SOT-23 | https://www.diodes.com/assets/Datasheets/ds11005.pdf |  |  |  |  |  | BAT54SFILM
 |  | D19 | BAT54S | bottom-board-rescue:BAT54S-Diode | Package_TO_SOT_SMD:SOT-23 | https://www.diodes.com/assets/Datasheets/ds11005.pdf |  |  |  |  |  | BAT54SFILM
 |  | D20 | BAT54S | bottom-board-rescue:BAT54S-Diode | Package_TO_SOT_SMD:SOT-23 | https://www.diodes.com/assets/Datasheets/ds11005.pdf |  |  |  |  |  | BAT54SFILM
 |  | D21 | BAT54S | bottom-board-rescue:BAT54S-Diode | Package_TO_SOT_SMD:SOT-23 | https://www.diodes.com/assets/Datasheets/ds11005.pdf |  |  |  |  |  | BAT54SFILM
 |  | D22 | BAT54S | bottom-board-rescue:BAT54S-Diode | Package_TO_SOT_SMD:SOT-23 | https://www.diodes.com/assets/Datasheets/ds11005.pdf |  |  |  |  |  | BAT54SFILM
 |  | F1 | FUSE | bottom-board-rescue:FUSE | Fuse:Fuse_2920_7451Metric |  |  |  |  |  |  | 0ZCF0200FF2C
 |  | FB1 | Ferrite_Bead | bottom-board-rescue:Ferrite_Bead-Device | Resistor_SMD:R_0603_1608Metric |  |  |  |  |  |  | BLM18HD102SH1D
 |  | FB2 | Ferrite_Bead | Device:Ferrite_Bead | Resistor_SMD:R_0603_1608Metric |  |  |  |  |  |  | BLM18HD102SH1D
 |  | FB3 | Ferrite_Bead | Device:Ferrite_Bead | Resistor_SMD:R_0603_1608Metric |  |  |  |  |  |  | BLM18HD102SH1D
 |  | FB12 | Ferrite_Bead | bottom-board-rescue:Ferrite_Bead-Device | Resistor_SMD:R_0603_1608Metric |  |  |  |  |  |  | BLM18HD102SH1D
 |  | FB13 | Ferrite_Bead | bottom-board-rescue:Ferrite_Bead-Device | Resistor_SMD:R_0603_1608Metric |  |  |  |  |  |  | BLM18HD102SH1D
 |  | FB14 | Ferrite_Bead | bottom-board-rescue:Ferrite_Bead-Device | Resistor_SMD:R_0603_1608Metric |  |  |  |  |  |  | BLM18HD102SH1D
 |  | FB15 | Ferrite_Bead | bottom-board-rescue:Ferrite_Bead-Device | Resistor_SMD:R_0603_1608Metric |  |  |  |  |  |  | BLM18HD102SH1D
 |  | FID1 | FIDUCIAL | bottom-board-rescue:FIDUCIAL-local-components | Uno:fiducial_in-circuit
 |  | FID2 | FIDUCIAL | bottom-board-rescue:FIDUCIAL-local-components | Uno:fiducial_in-circuit
 |  | FID3 | FIDUCIAL | bottom-board-rescue:FIDUCIAL-local-components | Uno:fiducial_in-circuit
 |  | H1 | HOLE | bottom-board-rescue:HOLE-local-components | Uno:Hole_3.5mm
 |  | H2 | HOLE | bottom-board-rescue:HOLE-local-components | Uno:Hole_3.5mm
 |  | H3 | HOLE | bottom-board-rescue:HOLE-local-components | Uno:Hole_3.5mm
 |  | H4 | HOLE | bottom-board-rescue:HOLE-local-components | Uno:Hole_3.5mm
 |  | H5 | MountingHole_Pad | bottom-board-rescue:MountingHole_Pad-Mechanical | MountingHole:MountingHole_3.2mm_M3_DIN965_Pad
 |  | H6 | MountingHole_Pad | bottom-board-rescue:MountingHole_Pad-Mechanical | MountingHole:MountingHole_3.2mm_M3_DIN965_Pad |  |  |  |  |  |  | 9774030243R
 |  | H7 | MountingHole_Pad | bottom-board-rescue:MountingHole_Pad-Mechanical | MountingHole:MountingHole_3.2mm_M3_DIN965_Pad |  |  |  |  |  |  | 9774030243R
 |  | J1 | AS0A823-H4SB-7H | bottom-board-rescue:AS0A823-H4SB-7H | Uno:TE_2309409-1 | None | AS0A823-H4SB-7H | AS Series 260 Pin Single Row DDR4 SODIMM Connector | Foxconn | Unavailable | None | TE_2309409-1
 |  | J2 | Conn_01x25 | Connector_Generic:Conn_01x25 | F51L-1A7H1-11024:F51L-1A7H1-11024 | ~ |  |  |  |  |  | F51L-1A7H1-11024
 |  | JP1 | Jumper | bottom-board-rescue:Jumper-Device | Jumper:SolderJumper-2_P1.3mm_Bridged2Bar_RoundedPad1.0x1.5mm
 |  | L1 | 1mH | bottom-board-rescue:INDUCTOR-pspice | Inductor_SMD:L_Bourns_SRR1260 |  |  |  |  |  |  | SRR1260-102K
 |  | L2 | 47UH 2A 135 MOHM | bottom-board-rescue:INDUCTOR-pspice | Uno:SRN8040TA | https://www.digikey.com/product-detail/en/bourns-inc/SRN8040TA-470M/SRN8040TA-470MTR-ND/6155133 |  |  |  |  |  | SRN8040TA-470M
 |  | P1 | USB_B | bottom-board-rescue:USB_B-RESCUE-bottom-board | Connector_USB:USB_B_OST_USB-B1HSxx_Horizontal |  |  |  |  |  |  | 61729-1011BLF
 |  | P2 | USB_A | bottom-board-rescue:USB_A-RESCUE-bottom-board | Uno:USB_A_Vertical |  |  |  |  |  |  | KUSBX-SLAS1N-B
 |  | P3 | BARREL_JACK | bottom-board-rescue:BARREL_JACK | Connector_BarrelJack:BarrelJack_Horizontal |  |  |  |  |  |  | PJ-002AH
 |  | P6 | AudioJack3 | bottom-board-rescue:AudioJack3-Connector | Connector_Audio:Jack_3.5mm_CUI_SJ-3523-SMT_Horizontal |  |  |  |  |  |  | SJ-3523-SMT-TR
 |  | P7 | AudioJack3 | bottom-board-rescue:AudioJack3-Connector | Connector_Audio:Jack_3.5mm_CUI_SJ-3523-SMT_Horizontal |  |  |  |  |  |  | SJ-3523-SMT-TR
 |  | P8 | SERIAL_DEBUG | bottom-board-rescue:CONN_01X03 | Connector_PinHeader_2.54mm:PinHeader_1x03_P2.54mm_Vertical |  |  |  |  |  |  | DO NOT PLACE
 |  | P9 | JACK_TRS_6PINS | bottom-board-rescue:AudioJack3_Switch-Connector | Connector_Audio:Jack_3.5mm_Neutrik_NMJ6HCD2_Horizontal |  |  |  |  |  |  | NYS215
 |  | P10 | JACK_TRS_6PINS | bottom-board-rescue:AudioJack3_Switch-Connector | Connector_Audio:Jack_3.5mm_Neutrik_NMJ6HCD2_Horizontal |  |  |  |  |  |  | NYS215
 |  | P11 | JACK_TRS_6PINS | bottom-board-rescue:AudioJack3_Switch-Connector | Connector_Audio:Jack_3.5mm_Neutrik_NMJ6HCD2_Horizontal |  |  |  |  |  |  | NYS215
 |  | P12 | JACK_TRS_6PINS | bottom-board-rescue:AudioJack3_Switch-Connector | Connector_Audio:Jack_3.5mm_Neutrik_NMJ6HCD2_Horizontal |  |  |  |  |  |  | NYS215
 |  | P13 | RJ45 | bottom-board-rescue:RJ45-Connector | digikey-footprints:Ethernet_Jack_54602-908LF |  |  |  |  |  |  | 54602-908LF
 |  | P14 | AudioJack3 | bottom-board-rescue:AudioJack3-Connector | Connector_Audio:Jack_3.5mm_CUI_SJ-3523-SMT_Horizontal |  |  |  |  |  |  | SJ-3523-SMT-TR
 |  | Power1 | TestPoint | bottom-board-rescue:TestPoint-Connector | TestPoint:TestPoint_Pad_D1.5mm
 |  | Q1 | 2N7002 | bottom-board-rescue:Q_NMOS_GSD | Package_TO_SOT_SMD:SOT-23 |  |  |  |  |  |  | 2N7002P,215
 |  | Q2 | 2N7002 | bottom-board-rescue:Q_NMOS_GSD | Package_TO_SOT_SMD:SOT-23 |  |  |  |  |  |  | 2N7002P,215
 |  | Q3 | MMBFJ211 | bottom-board-rescue:Q_NJFET_DSG | Package_TO_SOT_SMD:SOT-23 |  |  |  |  |  |  | MMBFJ211CT-ND
 |  | Q4 | MMBFJ211 | bottom-board-rescue:Q_NJFET_DSG | Package_TO_SOT_SMD:SOT-23 |  |  |  |  |  |  | MMBFJ211CT-ND
 |  | Q5 | MMBFJ211 | bottom-board-rescue:Q_NJFET_DSG | Package_TO_SOT_SMD:SOT-23 |  |  |  |  |  |  | MMBFJ211CT-ND
 |  | Q6 | MMBFJ211 | bottom-board-rescue:Q_NJFET_DSG | Package_TO_SOT_SMD:SOT-23 |  |  |  |  |  |  | MMBFJ211CT-ND
 |  | Q7 | 2N7002 | bottom-board-rescue:Q_NMOS_GSD | Package_TO_SOT_SMD:SOT-23 |  |  |  |  |  |  | 2N7002P,215
 |  | Q8 | 2N7002 | bottom-board-rescue:Q_NMOS_GSD | Package_TO_SOT_SMD:SOT-23 |  |  |  |  |  |  | 2N7002P,215
 |  | Q9 | MMBFJ211 | bottom-board-rescue:Q_NJFET_DSG | Package_TO_SOT_SMD:SOT-23 |  |  |  |  |  |  | MMBFJ211CT-ND
 |  | Q10 | MMBFJ211 | bottom-board-rescue:Q_NJFET_DSG | Package_TO_SOT_SMD:SOT-23 |  |  |  |  |  |  | MMBFJ211CT-ND
 |  | Q12 | 2N7002 | bottom-board-rescue:Q_NMOS_GSD | Package_TO_SOT_SMD:SOT-23 |  |  |  |  |  |  | 2N7002P,215
 |  | Q13 | 2N7002 | bottom-board-rescue:Q_NMOS_GSD | Package_TO_SOT_SMD:SOT-23 |  |  |  |  |  |  | 2N7002P,215
 |  | R1 | 2K7 | bottom-board-rescue:R_Small | Resistor_SMD:R_0603_1608Metric |  |  |  |  |  |  | CRGCQ0603F2K7
 |  | R2 | 2K7 | bottom-board-rescue:R_Small | Resistor_SMD:R_0603_1608Metric |  |  |  |  |  |  | CRGCQ0603F2K7
 |  | R3 | 22R | bottom-board-rescue:R_Small | Resistor_SMD:R_0603_1608Metric |  |  |  |  |  |  | RMCF0603JT22R0
 |  | R4 | 22R | bottom-board-rescue:R_Small | Resistor_SMD:R_0603_1608Metric |  |  |  |  |  |  | RMCF0603JT22R0
 |  | R5 | 22R | bottom-board-rescue:R_Small | Resistor_SMD:R_0603_1608Metric |  |  |  |  |  |  | RMCF0603JT22R0
 |  | R6 | 22R | bottom-board-rescue:R_Small | Resistor_SMD:R_0603_1608Metric |  |  |  |  |  |  | RMCF0603JT22R0
 |  | R7 | 22R | bottom-board-rescue:R_Small | Resistor_SMD:R_0603_1608Metric |  |  |  |  |  |  | RMCF0603JT22R0
 |  | R8 | 100R | bottom-board-rescue:R_Small-Device | Resistor_SMD:R_0603_1608Metric |  |  |  |  |  |  | RT0603DRD07100RL
 |  | R9 | 22R | bottom-board-rescue:R_Small | Resistor_SMD:R_0603_1608Metric |  |  |  |  |  |  | RMCF0603JT22R0
 |  | R10 | 22R | bottom-board-rescue:R_Small | Resistor_SMD:R_0603_1608Metric |  |  |  |  |  |  | RMCF0603JT22R0
 |  | R11 | 2K7 | bottom-board-rescue:R_Small | Resistor_SMD:R_0603_1608Metric |  |  |  |  |  |  | CRGCQ0603F2K7
 |  | R12 | 100R | bottom-board-rescue:R_Small | Resistor_SMD:R_0603_1608Metric |  |  |  |  |  |  | RT0603DRD07100RL
 |  | R13 | 100R | bottom-board-rescue:R_Small | Resistor_SMD:R_0603_1608Metric |  |  |  |  |  |  | RT0603DRD07100RL
 |  | R14 | 100K | bottom-board-rescue:R_Small | Resistor_SMD:R_0603_1608Metric |  |  |  |  |  |  | RMCF0603JT100K
 |  | R15 | 100K | bottom-board-rescue:R_Small | Resistor_SMD:R_0603_1608Metric |  |  |  |  |  |  | RMCF0603JT100K
 |  | R16 | 1M | bottom-board-rescue:R_Small-Device | Resistor_SMD:R_0603_1608Metric |  |  |  |  |  |  | RT0603BRD071ML
 |  | R17 | 47R | bottom-board-rescue:R_Small-Device | Resistor_SMD:R_0603_1608Metric |  |  |  |  |  |  | RT0603DRE0747RL
 |  | R18 | 47R | bottom-board-rescue:R_Small-Device | Resistor_SMD:R_0603_1608Metric |  |  |  |  |  |  | RT0603DRE0747RL
 |  | R19 | 10K | bottom-board-rescue:R_Small-Device | Resistor_SMD:R_0603_1608Metric |  |  |  |  |  |  | RR0816P-103-D
 |  | R20 | 2K7 | bottom-board-rescue:R_Small-Device | Resistor_SMD:R_0603_1608Metric |  |  |  |  |  |  | CRGCQ0603F2K7
 |  | R21 | 10K | bottom-board-rescue:R_Small-Device | Resistor_SMD:R_0603_1608Metric |  |  |  |  |  |  | RR0816P-103-D
 |  | R22 | 2K7 | bottom-board-rescue:R_Small-Device | Resistor_SMD:R_0603_1608Metric |  |  |  |  |  |  | CRGCQ0603F2K7
 |  | R23 | 1M | bottom-board-rescue:R_Small-Device | Resistor_SMD:R_0603_1608Metric |  |  |  |  |  |  | RT0603BRD071ML
 |  | R24 | 1M | bottom-board-rescue:R_Small-Device | Resistor_SMD:R_0603_1608Metric |  |  |  |  |  |  | RT0603BRD071ML
 |  | R25 | 100K | bottom-board-rescue:R_Small-Device | Resistor_SMD:R_0603_1608Metric |  |  |  |  |  |  | RMCF0603JT100K
 |  | R26 | 100K | bottom-board-rescue:R_Small-Device | Resistor_SMD:R_0603_1608Metric |  |  |  |  |  |  | RMCF0603JT100K
 |  | R27 | 1M | bottom-board-rescue:R_Small-Device | Resistor_SMD:R_0603_1608Metric |  |  |  |  |  |  | RT0603BRD071ML
 |  | R28 | 1M | bottom-board-rescue:R_Small-Device | Resistor_SMD:R_0603_1608Metric |  |  |  |  |  |  | RT0603BRD071ML
 |  | R29 | 1M | bottom-board-rescue:R_Small-Device | Resistor_SMD:R_0603_1608Metric |  |  |  |  |  |  | RT0603BRD071ML
 |  | R30 | 10R | bottom-board-rescue:R_Small | Resistor_SMD:R_0603_1608Metric |  |  |  |  |  |  | CRGCQ0603J10R
 |  | R31 | 1M | bottom-board-rescue:R_Small-Device | Resistor_SMD:R_0603_1608Metric |  |  |  |  |  |  | RT0603BRD071ML
 |  | R32 | 5K6 | bottom-board-rescue:R_Small-Device | Resistor_SMD:R_0603_1608Metric |  |  |  |  |  |  | ERA-3AED562V
 |  | R33 | 5K6 | bottom-board-rescue:R_Small-Device | Resistor_SMD:R_0603_1608Metric |  |  |  |  |  |  | ERA-3AED562V
 |  | R34 | 22K | bottom-board-rescue:R_Small-Device | Resistor_SMD:R_0603_1608Metric |  |  |  |  |  |  | RT0603DRD0722KL
 |  | R35 | 22K | bottom-board-rescue:R_Small-Device | Resistor_SMD:R_0603_1608Metric |  |  |  |  |  |  | RT0603DRD0722KL
 |  | R36 | 4K7 | bottom-board-rescue:R_Small-Device | Resistor_SMD:R_0603_1608Metric |  |  |  |  |  |  | RT0603DRE074K7L
 |  | R37 | 4K7 | bottom-board-rescue:R_Small-Device | Resistor_SMD:R_0603_1608Metric |  |  |  |  |  |  | RT0603DRE074K7L
 |  | R38 | 4K7 | bottom-board-rescue:R_Small-Device | Resistor_SMD:R_0603_1608Metric |  |  |  |  |  |  | RT0603DRE074K7L
 |  | R39 | 4K7 | bottom-board-rescue:R_Small-Device | Resistor_SMD:R_0603_1608Metric |  |  |  |  |  |  | RT0603DRE074K7L
 |  | R40 | 1M | bottom-board-rescue:R_Small-Device | Resistor_SMD:R_0603_1608Metric |  |  |  |  |  |  | RT0603BRD071ML
 |  | R41 | 100R | bottom-board-rescue:R_Small-Device | Resistor_SMD:R_0603_1608Metric |  |  |  |  |  |  | RT0603DRD07100RL
 |  | R42 | 10K | bottom-board-rescue:R_Small | Resistor_SMD:R_0603_1608Metric |  |  |  |  |  |  | RR0816P-103-D
 |  | R43 | 15K | bottom-board-rescue:R_Small | Resistor_SMD:R_0603_1608Metric |  |  |  |  |  |  | RMCF0603JT15K0
 |  | R44 | 1M | bottom-board-rescue:R_Small-Device | Resistor_SMD:R_0603_1608Metric |  |  |  |  |  |  | RT0603BRD071ML
 |  | R45 | 100R | bottom-board-rescue:R_Small-Device | Resistor_SMD:R_0603_1608Metric |  |  |  |  |  |  | RT0603DRD07100RL
 |  | R46 | 10K | bottom-board-rescue:R_Small | Resistor_SMD:R_0603_1608Metric |  |  |  |  |  |  | RR0816P-103-D
 |  | R47 | 220R | bottom-board-rescue:R_Small | Resistor_SMD:R_0603_1608Metric |  |  |  |  |  |  | RC0603FR-07220RL
 |  | R48 | 1M | bottom-board-rescue:R_Small-Device | Resistor_SMD:R_0603_1608Metric |  |  |  |  |  |  | RT0603BRD071ML
 |  | R49 | 220R | bottom-board-rescue:R_Small | Resistor_SMD:R_0603_1608Metric |  |  |  |  |  |  | RC0603FR-07220RL
 |  | R50 | 220R | bottom-board-rescue:R_Small | Resistor_SMD:R_0603_1608Metric |  |  |  |  |  |  | RC0603FR-07220RL
 |  | R51 | 10K | bottom-board-rescue:R_Small | Resistor_SMD:R_0603_1608Metric |  |  |  |  |  |  | RR0816P-103-D
 |  | R52 | 10K | bottom-board-rescue:R_Small | Resistor_SMD:R_0603_1608Metric |  |  |  |  |  |  | RR0816P-103-D
 |  | R53 | 100K | bottom-board-rescue:R_Small-Device | Resistor_SMD:R_0603_1608Metric |  |  |  |  |  |  | RMCF0603JT100K
 |  | R54 | 100K | bottom-board-rescue:R_Small-Device | Resistor_SMD:R_0603_1608Metric |  |  |  |  |  |  | RMCF0603JT100K
 |  | R55 | 100R | bottom-board-rescue:R_Small | Resistor_SMD:R_0603_1608Metric |  |  |  |  |  |  | RT0603DRD07100RL
 |  | R56 | 100R | bottom-board-rescue:R_Small | Resistor_SMD:R_0603_1608Metric |  |  |  |  |  |  | RT0603DRD07100RL
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

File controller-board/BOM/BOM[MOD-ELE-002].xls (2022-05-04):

Comment | Description | Designator | Footprint | Quantity | Manufacturer 1 | Supplier 1 | Supplier Part Number 1
10uF | CAP ALUM 10UF 20% 25V SMD | C1 | CAP_EEE_C-L | 1 | Panasonic | Digi-Key | PCE3894CT-ND
100uF | CAP ALUM 100UF 20% 10V SMD | C2 | CAPAE6553X55M | 1 | Panasonic ECG | Digi-Key | PCE3867CT-ND
0.1uF | CAP CER 0.1UF 25V X7R 0603 | C3, C4, C5, C6, C7, C8, C9, C10, C11, C12, C14, C16, C18, C20, C30, C38, C39 | CAPC1608N | 17 | Yageo | Digi-Key | 311-1341-1-ND
10uF | CAP CER 10UF 10V X5R 0603 | C13, C19 | CAPC1608N | 2 | Murata | Digi-Key | 490-10474-1-ND
39pF | CAP CER 39PF 50V NP0 0603 | C15, C17 | CAPC1608N | 2 | TDK | Digi-Key | 445-14077-1-ND
1uF | CAP CER 1UF 35V X5R 0603 | C22, C23, C31, C32, C33, C34, C35, C36, C37 | CAPC1608N | 9 | Samsung | Digi-Key | 1276-1861-1-ND
0.01uF | CAP CER 10000PF 50V X7R 0603 | C24, C25, C26, C27, C28, C29 | CAPC1608N | 6 | Kyocera AVX | Digi-Key | 478-1227-1-ND
2.2uF | CAP CER 2.2UF 10V X5R 0603 | C40, C41 | CAPC1608N | 2 | Samsung | Digi-Key | 1276-1085-1-ND
1N4148 | DIODE SWITCHING 75V 0.15A SOD323 | D1, D2 | SOD-323 | 2 | Diodes | Digi-Key | 1N4148WS-FDICT-ND
PEC11R | ENCODER ROTARY 15MM SHAFT | E1, E2, E3 | PEC11R | 3 | Bourns | Digi-Key | PEC11R-4215F-S0024-ND
BL-HJXGXBX32N | LED RGB 6PLCC SMD | LED1, LED2, LED3, LED4, LED5, LED6, LED7, LED8, LED9, LED10, LED11 | BL-HJXGXBX32N | 11 | American Bright | Digi-Key | BL-HJXGXBX32NCT-ND
F51L-1A7H1-11024 | FLEX CONNECTOR, 1.00MM PITCH, HE | P1 | F51L-1A7H1-11024 | 1 | Amphenol ICC / FCI | Digi-Key | 609-F51L-1A7H1-11024CT-ND
ER-CON2.0-2P-SMD | CONN 2 POS SMD 2MM PITCH | P2, P3, P4, P6 | ER-CON2.0-2P-SMD | 4
ER-CON26HT-1 | CONN ZIF 26 TOP PIN SMT | P5 | ER-CON26HT-1 | 1
2N7002 | MOSFET N-CH 60V 115MA SOT-23 | Q1, Q2, Q3, Q4, Q5, Q6, Q7, Q8, Q9, Q10, Q11, Q12, Q13, Q14, Q15, Q16, Q17, Q18, Q19, Q20, Q21, Q22, Q23 | SOT23-3N | 23 | ON Semiconductor / Fairchild | Digi-Key | 2N7002NCT-ND
160K | RES SMD 160K OHM 5% 1/10W 0603 | R1 | RESC1608N | 1 | Stackpole Electronics | Digi-Key | RMCF0603JT160KCT-ND
10K | RES SMD 10K OHM 5% 1/10W 0603 | R2, R3, R4, R5, R11, R12, R13, R14, R15, R16, R17, R18, R19, R20, R21, R22, R23, R24, R25, R26, R27, R28, R29, R30, R31, R32 | RESC1608N | 26 | Yageo | Digi-Key | 311-10KLECT-ND
100K | RES SMD 100K OHM 5% 1/4W 0603 | R6, R7, R8, R33, R37, R41, R42, R43, R44, R45, R49, R53, R54, R55, R56, R57, R61, R65, R66, R67, R68, R69, R73, R74 | RESC1608N | 24 | Rohm | Digi-Key | RHM100KDCT-ND
560R | RES SMD 560 OHM 5% 1/10W 0603 | R34, R38, R46, R50, R58, R62, R70 | RESC1608N | 7 | Yageo | Digi-Key | YAG3681CT-ND
470R | RES SMD 470 OHM 5% 1/10W 0603 | R35, R36, R39, R40, R47, R48, R51, R52, R59, R60, R63, R64, R71, R72 | RESC1608N | 14 | Stackpole Electronics | Digi-Key | RMCF0603JT470RCT-ND
220R | RES SMD 220 OHM 5% 1/10W 0603 | R75, R76, R77, R78, R79, R80, R81, R82, R83, R84, R85, R86 | RESC1608N | 12 | Vishay | Digi-Key | 541-220GCT-ND
TL3305 | SWITCH TACTILE SPST-NO 50MA 12V | SW1, SW2, SW3, SW4 | TL3305 | 4 | E-Switch | Digi-Key | EG5350CT-ND
NCP1117DT33G | IC REG LDO 3.3V 1A DPAK | U1 | DPAK-L | 1 | ON Semiconductor | Digi-Key | NCP1117DT33GOS-ND
LPC1778FBD144 | IC MCU 32BIT 512KB FLASH 144LQFP | U2 | LQFP144-SOT486-1 | 1 | NXP Semiconductors | Digi-Key | 568-7571-ND
MCP6001 | IC OPAMP GP 1MHZ RRO SOT23-5 | U3 | SOT23-5N | 1 | Microchip | Digi-Key | MCP6001T-I/OTCT-ND
PCA9685 | IC LED DRVR LIN DIM 25MA 28HVQFN | U4 | SOT788-1 | 1 | NXP Semiconductors | Digi-Key | 568-5305-1-ND
12Mhz | CRYSTAL 12MHZ 20PF SMD | Y1 | ECS-120-20-30B-AGL-TR | 1 | ECS International | Digi-Key | XC2731CT-ND

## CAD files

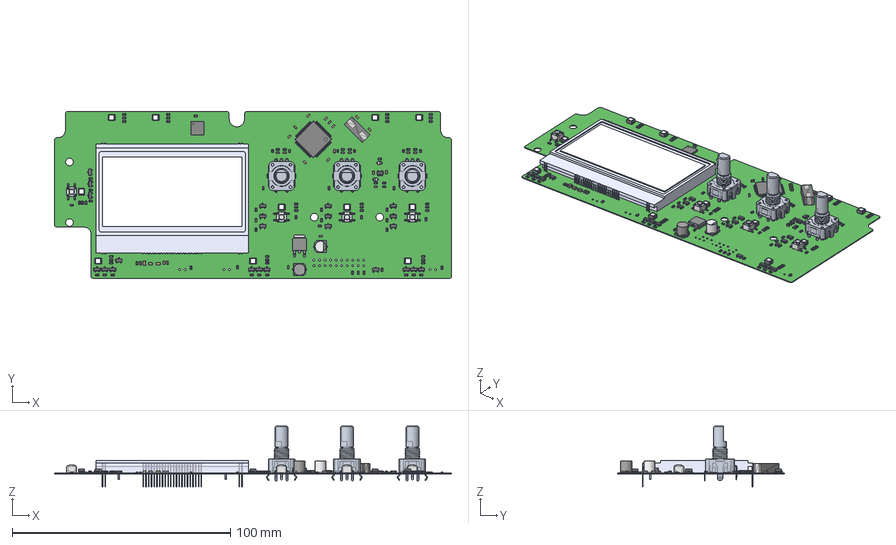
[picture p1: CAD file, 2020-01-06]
controller-board/3D/mod_duo_dwarf.step
182.0 x 76.5 x 27.9 mm
ERC12864-655
CRYSTAL_HC49SDLF
Extruded x 2
Open_CASCADE_STEP_translator_6.8_23.1
Open_CASCADE_STEP_translator_6.8_23.2.1
Thermal_Shape
Open_CASCADE_STEP_translator_6.8_23.4.1 x 28
SOT-23-5
Open_CASCADE_STEP_translator_6.8_11.1
Open_CASCADE_STEP_translator_6.8_11.2.1
Leader x 80
DPAK-1
TL3305AFxxxxG x 4
RES_1608_0603 x 86
User_Library-SOT-23-3_body_1 x 23
User_Library-SOT-23-3_pin_SOT_SOT-23_1 x 69
User_Library-RGB_LED_Zwart_ASMT-YTC2-0AA02_Pootje_RGB_LED x 66
User_Library-RGB_LED_Zwart_ASMT-YTC2-0AA02_ASMT-YTC2-0AA02 x 11
pec11r-4x15f-sxxxx x 3
SOD323-1 x 2
CAPC1608X09 x 25
CAPC2013X10 x 3
Open_CASCADE_STEP_translator_6.8_2.1.1
Open_CASCADE_STEP_translator_6.8_2.2.1
Open_CASCADE_STEP_translator_6.8_2.3.1
lead x 2
CAP_EEE_C-L

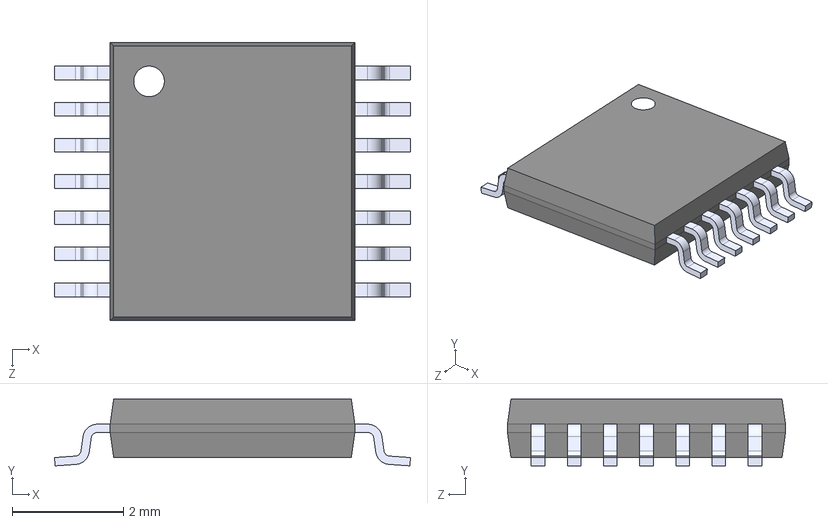
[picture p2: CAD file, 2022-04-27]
Documantation/Component libs/LSF0204DPWR/LSF0204DPWR.step
6.40 x 1.20 x 5.00 mm

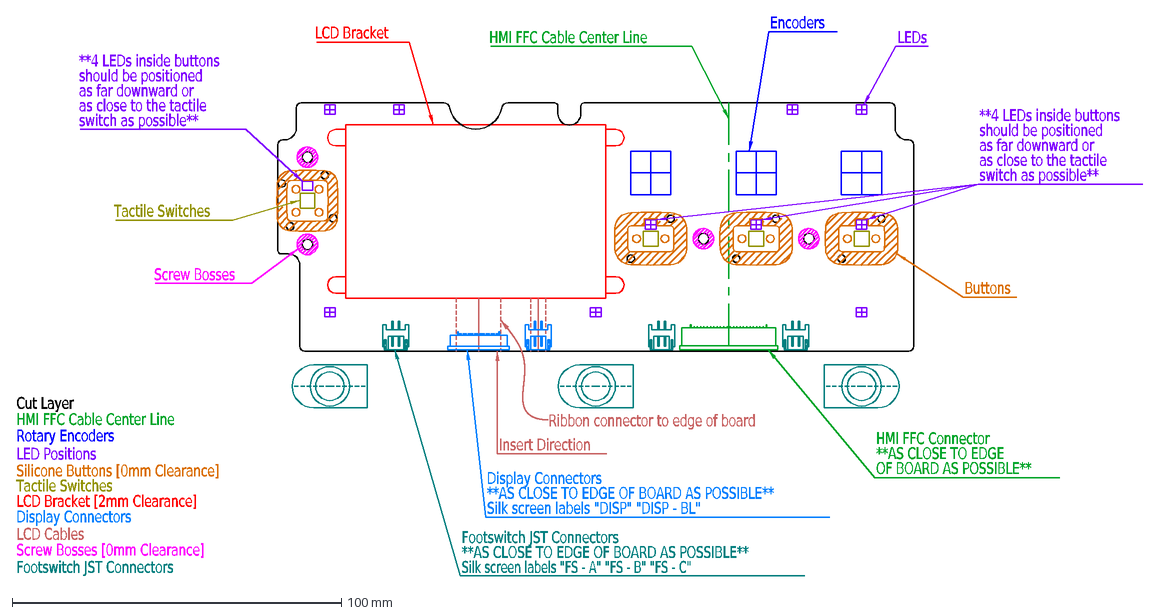
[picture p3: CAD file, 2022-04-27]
Documantation/Connector change files james 08-04-22/MDW-PCB_002_V2.0_REV-B-220406.DXF
Cut Layer
HMI FFC Cable Center Line
Rotary Encoders
LED Positions
Silicone Buttons [0mm Clearance]
Tactile Switches
LCD Bracket [2mm Clearance]
Screw Bosses [0mm Clearance]
LCD Cables
Ribbon connector to edge of board
LEDs
Encoders
Buttons
Screw Bosses
LCD Bracket
HMI FFC Connector
**AS CLOSE TO EDGE
OF BOARD AS POSSIBLE**
**4 LEDs inside buttons
should be positioned
as far downward or
as close to the tactile
switch as possible**
Insert Direction
Footswitch JST Connectors
Display Connectors
**AS CLOSE TO EDGE OF BOARD AS POSSIBLE**
Silk screen labels "DISP" "DISP - BL"
Silk screen labels "FS - A" "FS - B" "FS - C"

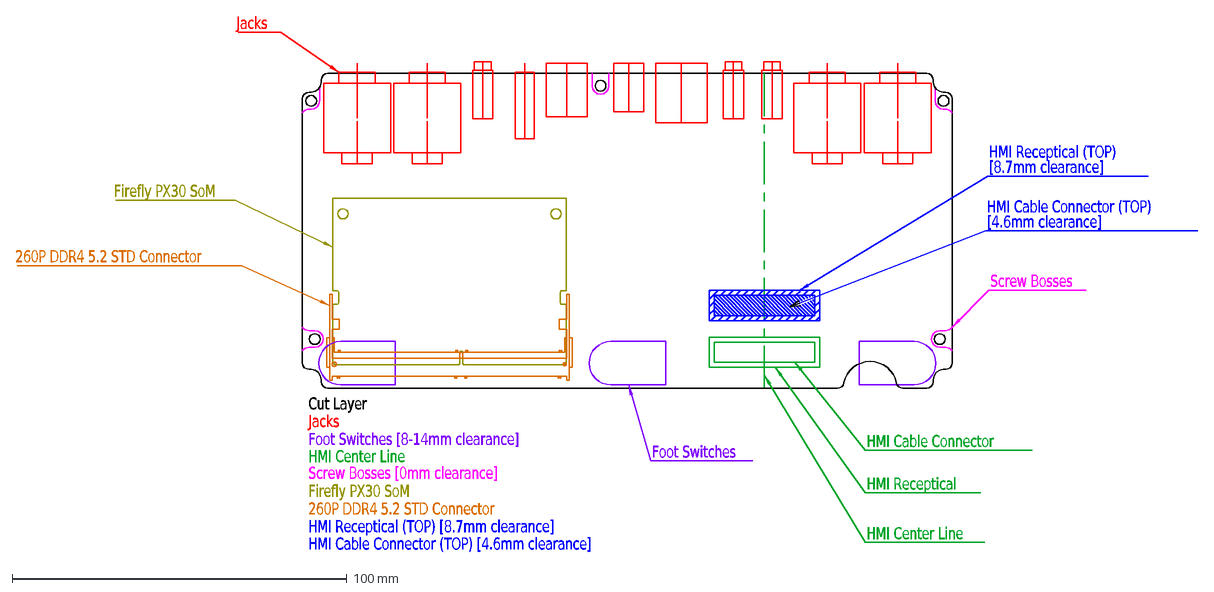
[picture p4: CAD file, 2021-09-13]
Documantation/size increase 13-11-21 mechanical files james/2021.09.09_[v1.0]MDW-PCB_001.DXF
Cut Layer
Jacks
Foot Switches [8-14mm clearance]
HMI Center Line
Screw Bosses [0mm clearance]
Foot Switches
Screw Bosses
HMI Receptical
HMI Cable Connector
HMI Cable Connector (TOP)
[4.6mm clearance]
HMI Receptical (TOP)
[8.7mm clearance]
Firefly PX30 SoM
260P DDR4 5.2 STD Connector
HMI Receptical (TOP) [8.7mm clearance]
HMI Cable Connector (TOP) [4.6mm clearance]

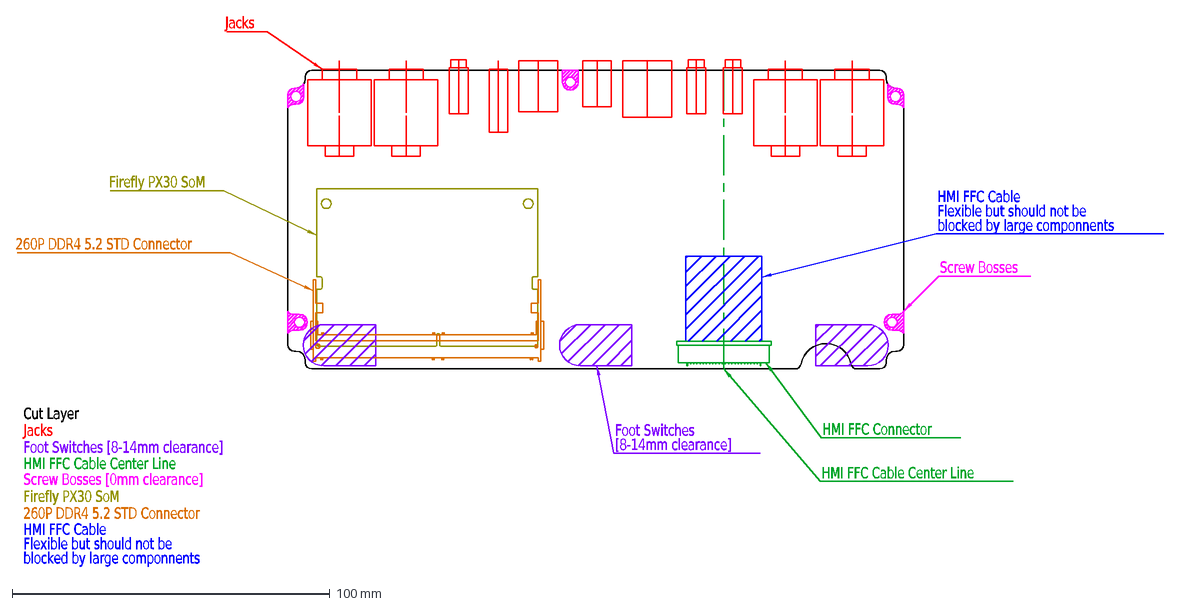
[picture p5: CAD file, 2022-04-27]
Documantation/Connector change files james 08-04-22/MDW-PCB_001_V2.0_REV-B-220406.DXF
Cut Layer
Jacks
Foot Switches [8-14mm clearance]
HMI FFC Cable Center Line
Screw Bosses [0mm clearance]
Foot Switches
[8-14mm clearance]
Screw Bosses
HMI FFC Connector
HMI FFC Cable
Flexible but should not be
blocked by large componnents
Firefly PX30 SoM
260P DDR4 5.2 STD Connector

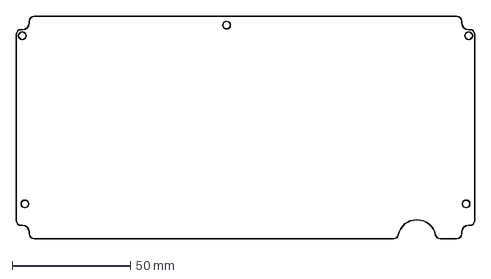
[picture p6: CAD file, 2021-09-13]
Documantation/size increase 13-11-21 mechanical files james/2021.09.09_[v1.0]MDW-PCB_001-Cut Only.DXF
194.0 x 94.0 mm

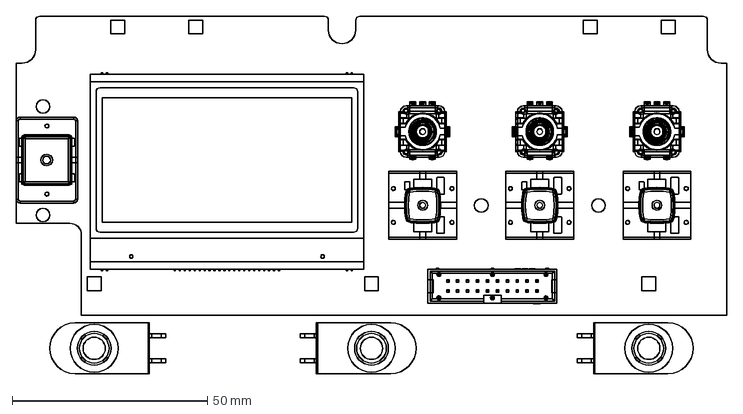
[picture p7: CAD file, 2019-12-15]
Documantation/original size files james/TopBoard with components 12.12.2019.DXF
182.0 x 91.5 mm

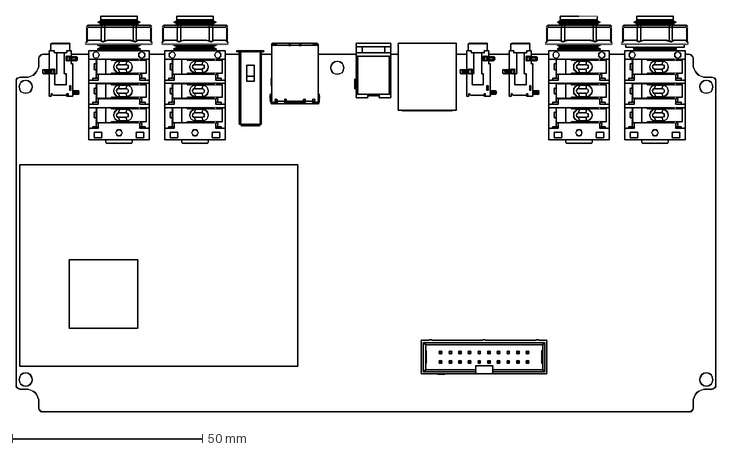
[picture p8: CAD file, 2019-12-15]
Documantation/original size files james/BottomBoard with components.DXF
184.0 x 104.1 mm

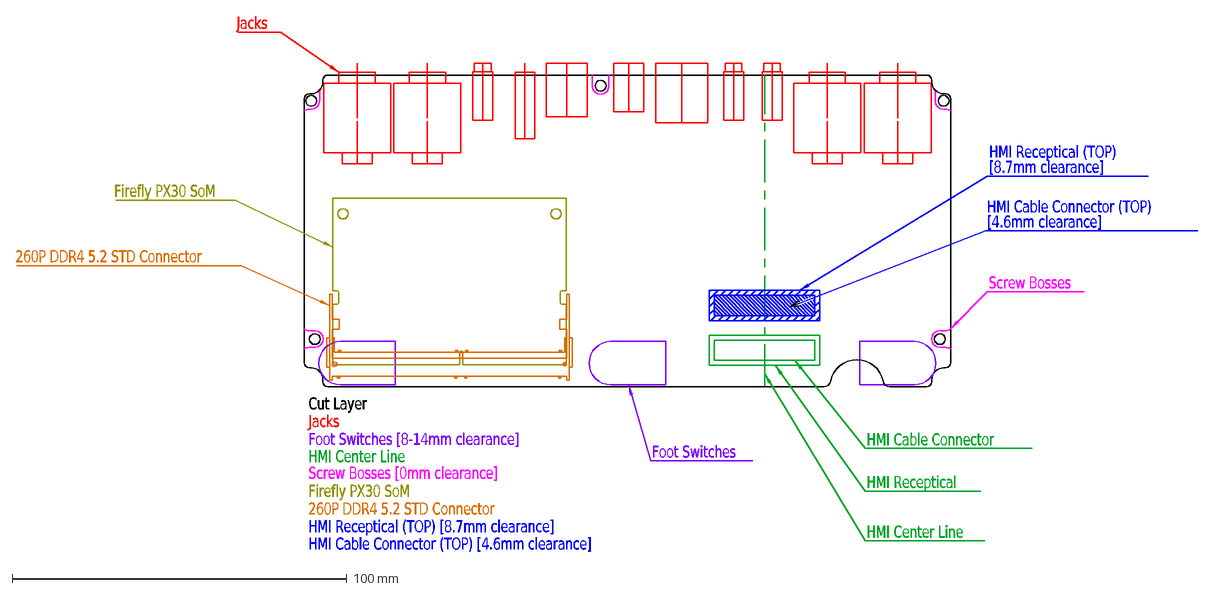
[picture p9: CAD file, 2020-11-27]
Documantation/original size files james/201126_Bottom Board_[v0.14].DXF
Cut Layer
Jacks
Foot Switches [8-14mm clearance]
HMI Center Line
Screw Bosses [0mm clearance]
Foot Switches
Screw Bosses
HMI Receptical
HMI Cable Connector
HMI Cable Connector (TOP)
[4.6mm clearance]
HMI Receptical (TOP)
[8.7mm clearance]
Firefly PX30 SoM
260P DDR4 5.2 STD Connector
HMI Receptical (TOP) [8.7mm clearance]
HMI Cable Connector (TOP) [4.6mm clearance]

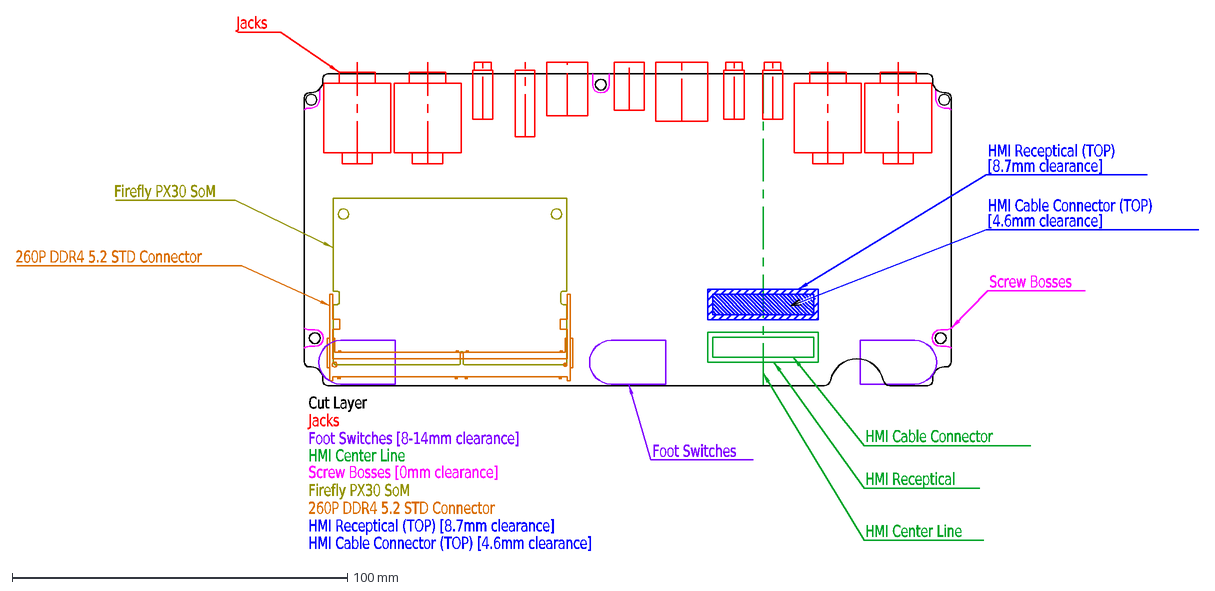
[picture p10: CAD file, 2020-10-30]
Documantation/original size files james/200923_Bottom Board_[v0.14].DXF
Cut Layer
Jacks
Foot Switches [8-14mm clearance]
HMI Center Line
Screw Bosses [0mm clearance]
Foot Switches
Screw Bosses
HMI Receptical
HMI Cable Connector
HMI Cable Connector (TOP)
[4.6mm clearance]
HMI Receptical (TOP)
[8.7mm clearance]
Firefly PX30 SoM
260P DDR4 5.2 STD Connector
HMI Receptical (TOP) [8.7mm clearance]
HMI Cable Connector (TOP) [4.6mm clearance]

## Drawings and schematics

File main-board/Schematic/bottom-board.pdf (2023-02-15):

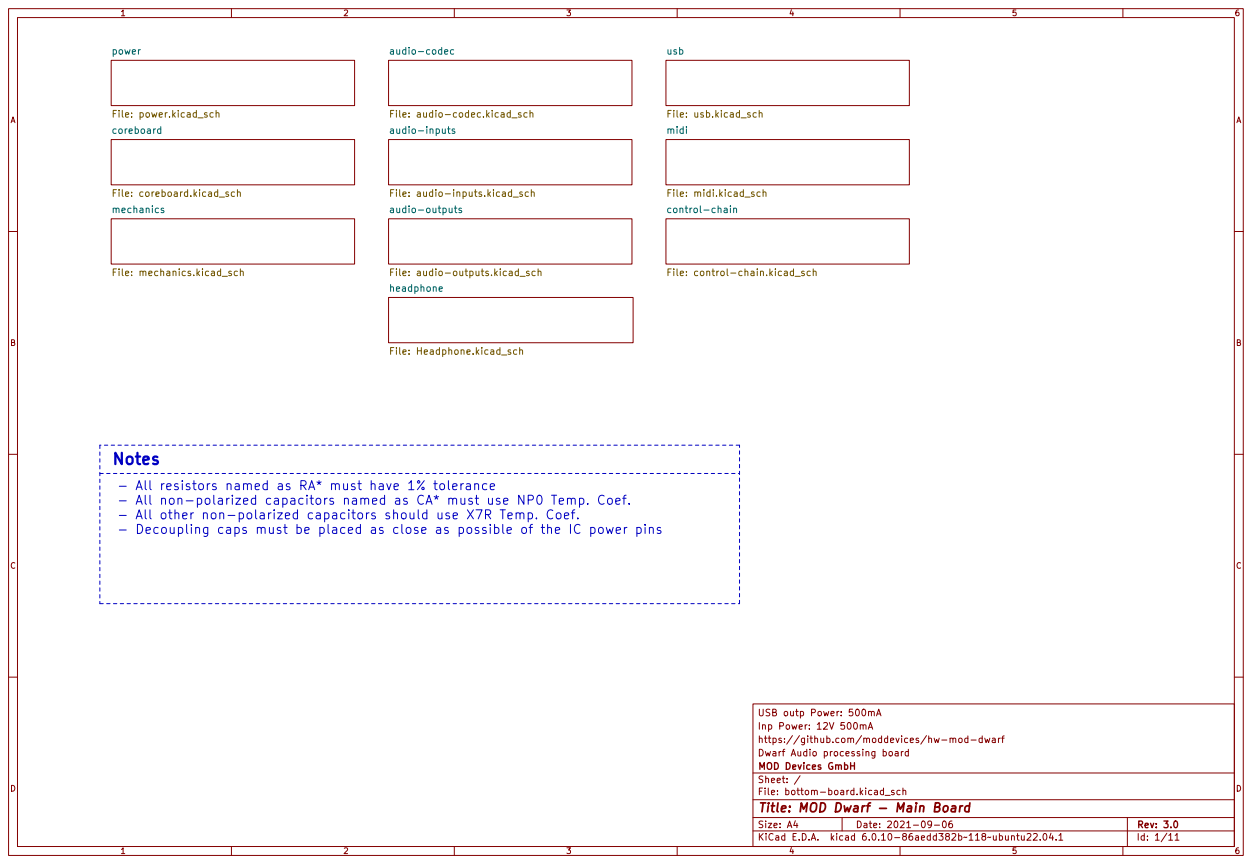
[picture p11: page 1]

audio-codec File: audio-codec.kicad_sch mechanics File: mechanics.kicad_sch

control-chain File: control-chain.kicad_sch midi File: midi.kicad_sch

- All resistors named as RA* must have 1% tolerance
- All non-polarized capacitors named as CA* must use NP0 Temp. Coef.
- All other non-polarized capacitors should use X7R Temp. Coef.
- Decoupling caps must be placed as close as possible of the IC power pins

USB outp Power: 500mA
Inp Power: 12V 500mA
https://github.com/moddevices/hw-mod-dwarf
Dwarf Audio processing board
File: bottom-board.kicad_sch Sheet: / MOD Devices GmbH

Id: 1/11 Title: MOD Dwarf - Main Board

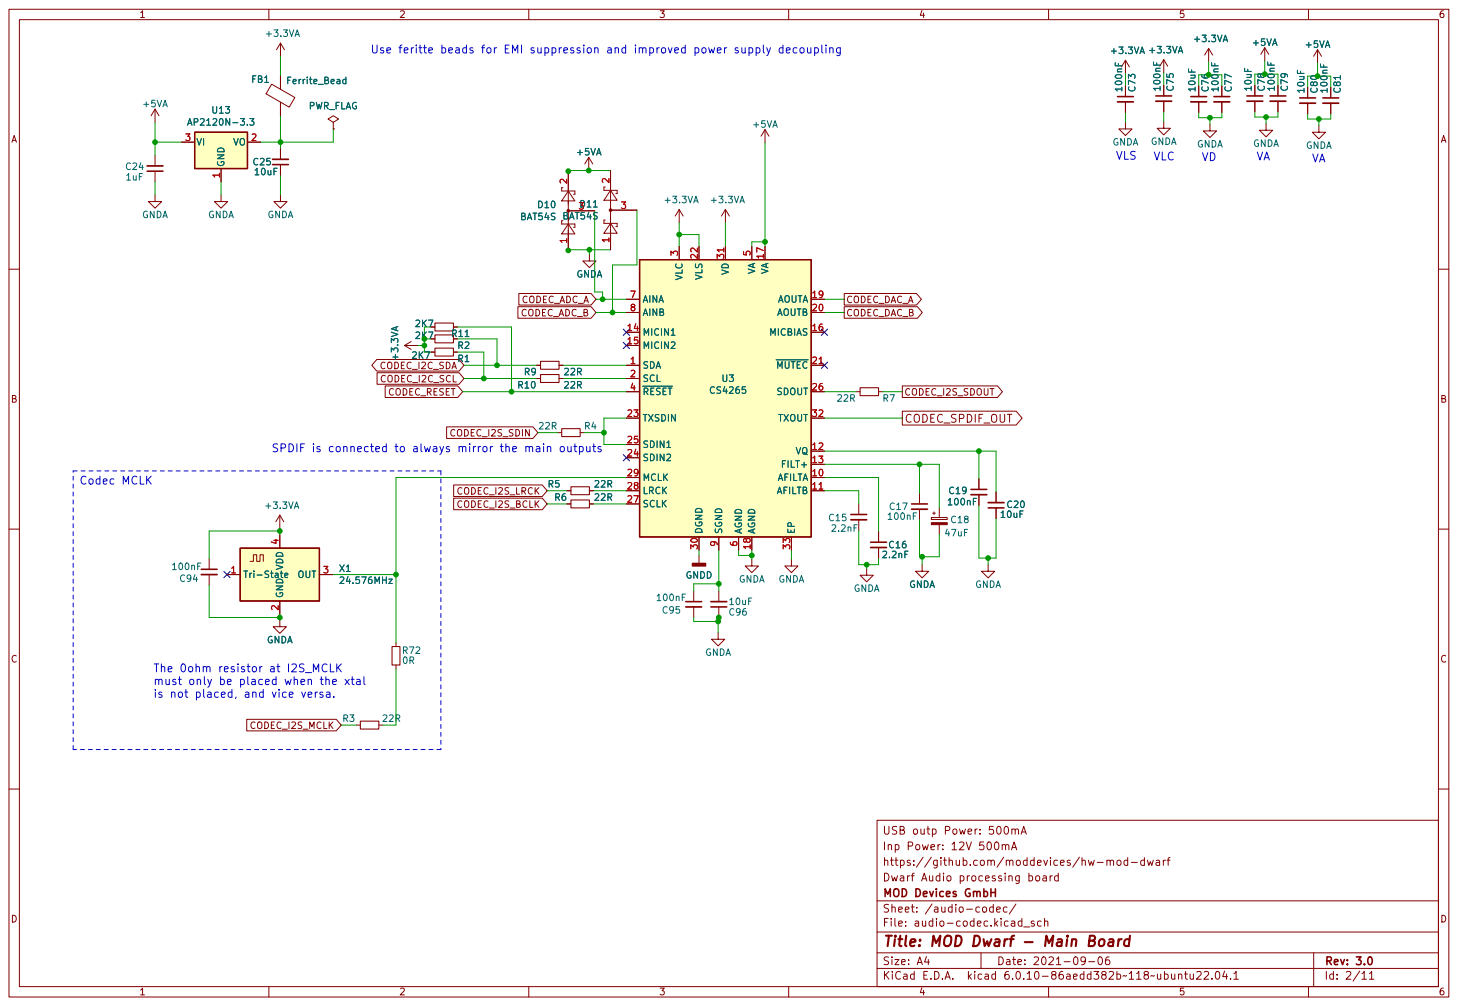
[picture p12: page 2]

4 GNDA U3 CS4265 SDA 1 AFILTA 10 AFILTB 11 VQ 12 FILT+ 13 MICIN1 14 MICIN2 15 MICBIAS 16 VA 17 AGND 18 AOUTA 19 SCL 2 AOUTB 20 ~{MUTEC}21 VLS 22 TXSDIN 23 SDIN2 24 SDIN1 25 SDOUT 26 SCLK 27

3 DGND 30 VD 31 TXOUT 32 EP 33

SPDIF is connected to always mirror the main outputs

The 0ohm resistor at I2S_MCLK
must only be placed when the xtal
is not placed, and vice versa.

USB outp Power: 500mA
Inp Power: 12V 500mA
https://github.com/moddevices/hw-mod-dwarf
Dwarf Audio processing board
File: audio-codec.kicad_sch Sheet: /audio-codec/ MOD Devices GmbH

Id: 2/11 Title: MOD Dwarf - Main Board

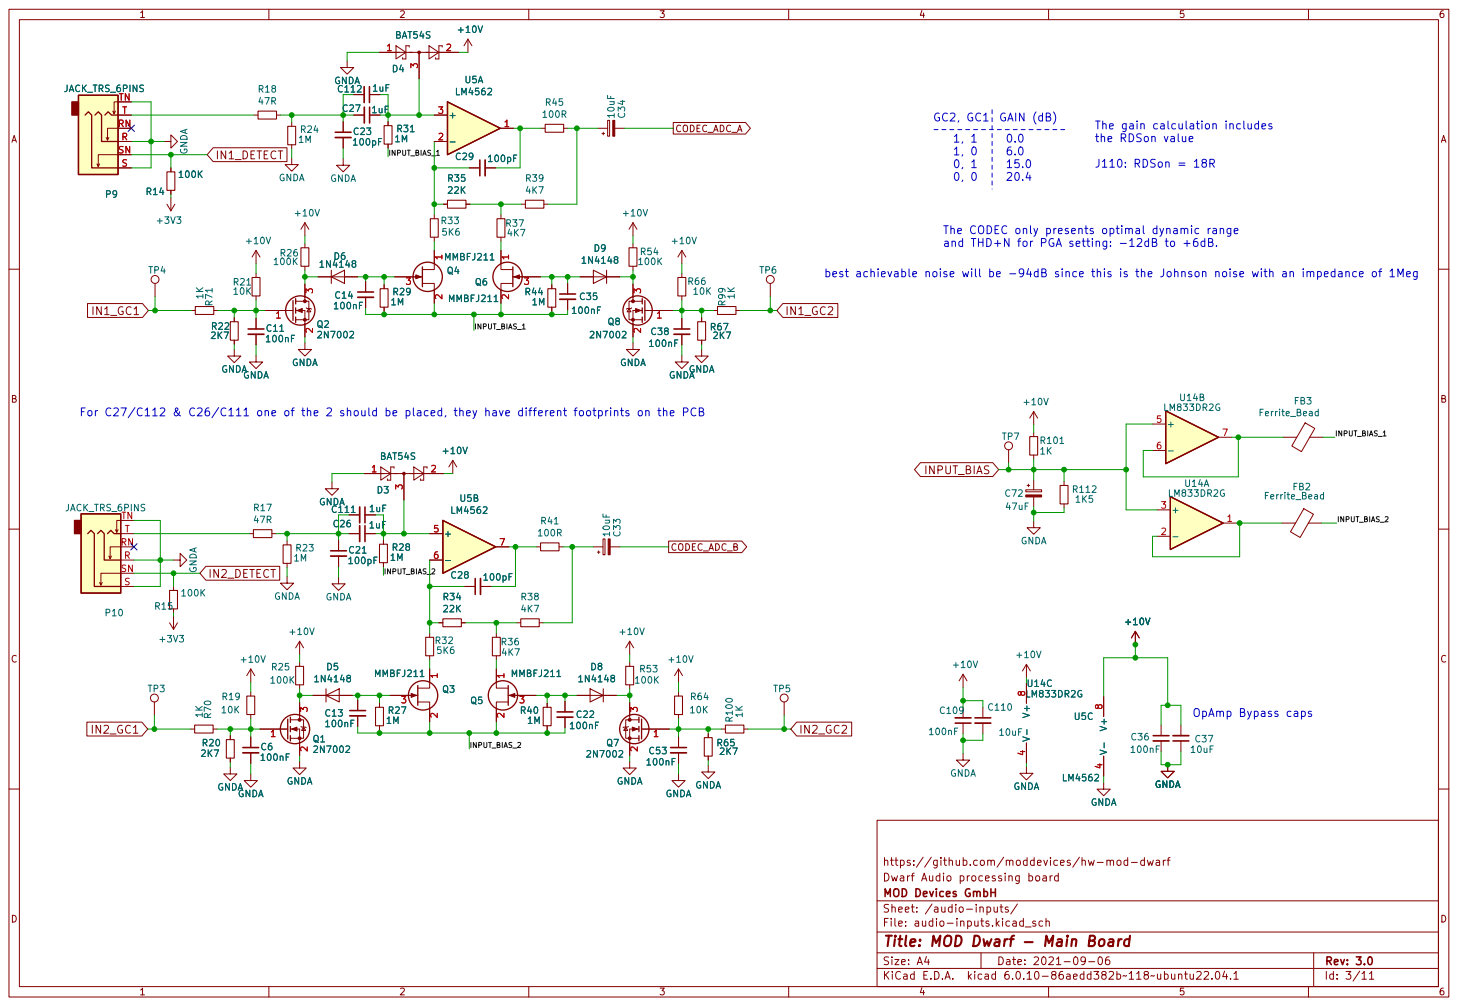
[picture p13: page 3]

The gain calculation includes
the RDSon value

The CODEC only presents optimal dynamic range
and THD+N for PGA setting: -12dB to +6dB.

INPUT_BIAS_1 best achievable noise will be -94dB since this is the Johnson noise with an impedance of 1Meg

For C27/C112 & C26/C111 one of the 2 should be placed, they have different footprints on the PCB

Dwarf Audio processing board
Sheet: /audio-inputs/ MOD Devices GmbH

File: audio-inputs.kicad_sch
Id: 3/11 Title: MOD Dwarf - Main Board

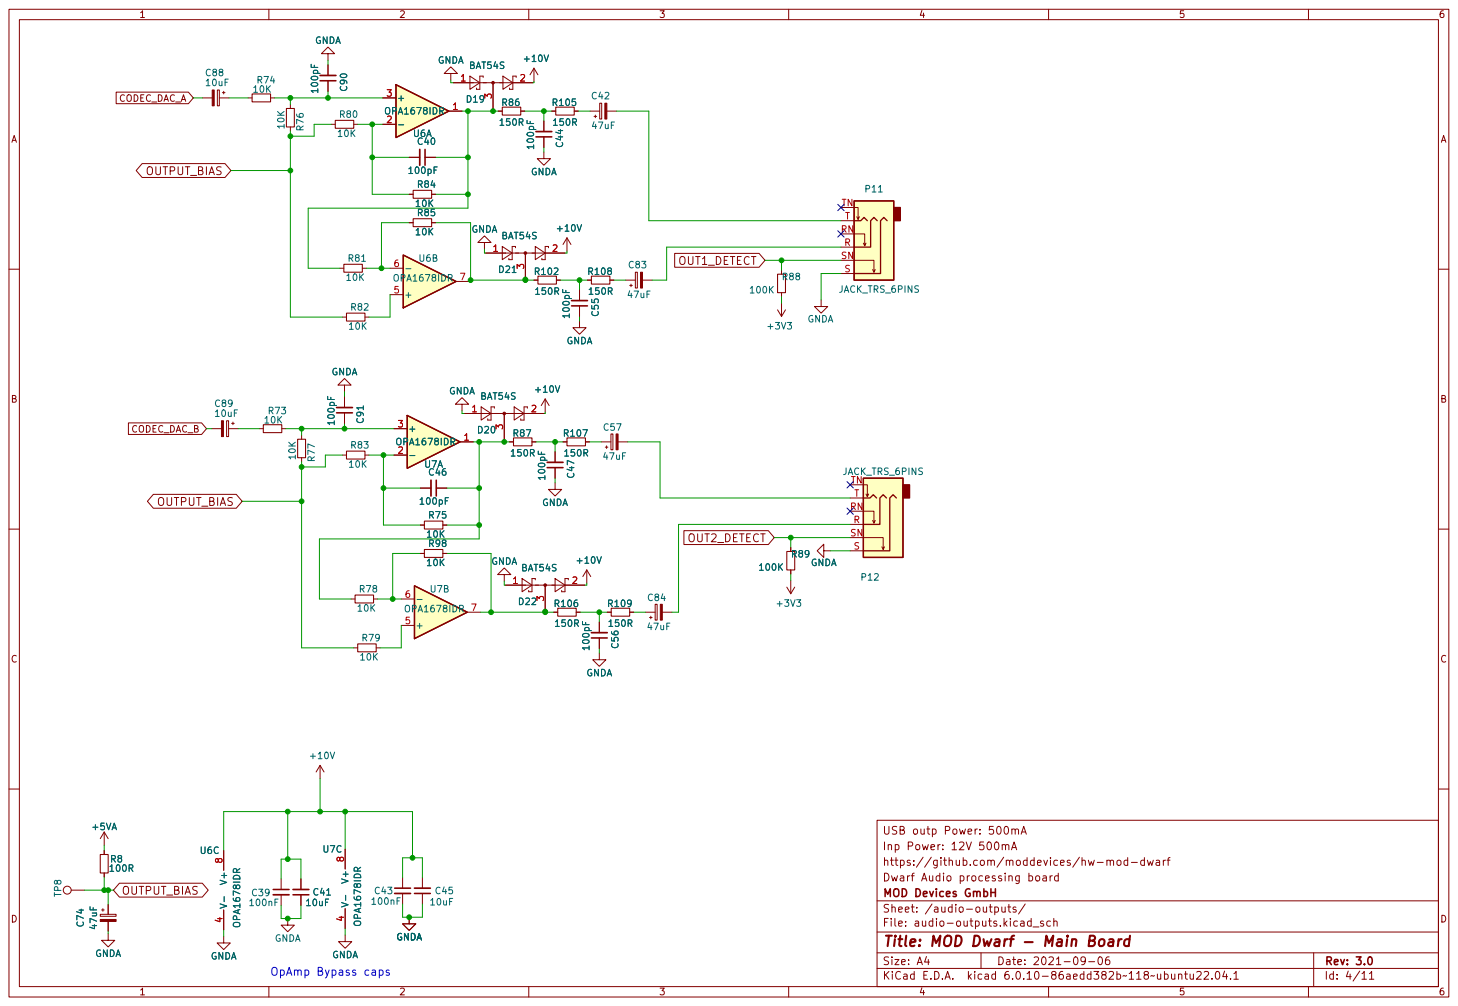
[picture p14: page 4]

USB outp Power: 500mA
Inp Power: 12V 500mA
https://github.com/moddevices/hw-mod-dwarf
Dwarf Audio processing board
Sheet: /audio-outputs/ MOD Devices GmbH

File: audio-outputs.kicad_sch
Id: 4/11 Title: MOD Dwarf - Main Board

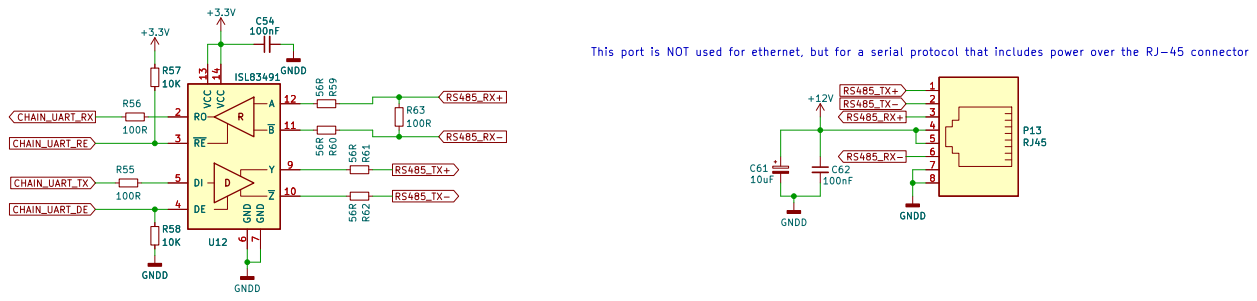
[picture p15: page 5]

USB outp Power: 500mA
Inp Power: 12V 500mA
https://github.com/moddevices/hw-mod-dwarf
Dwarf Audio processing board
File: control-chain.kicad_sch Sheet: /control-chain/ MOD Devices GmbH

Id: 5/11 Title: MOD Dwarf - Main Board

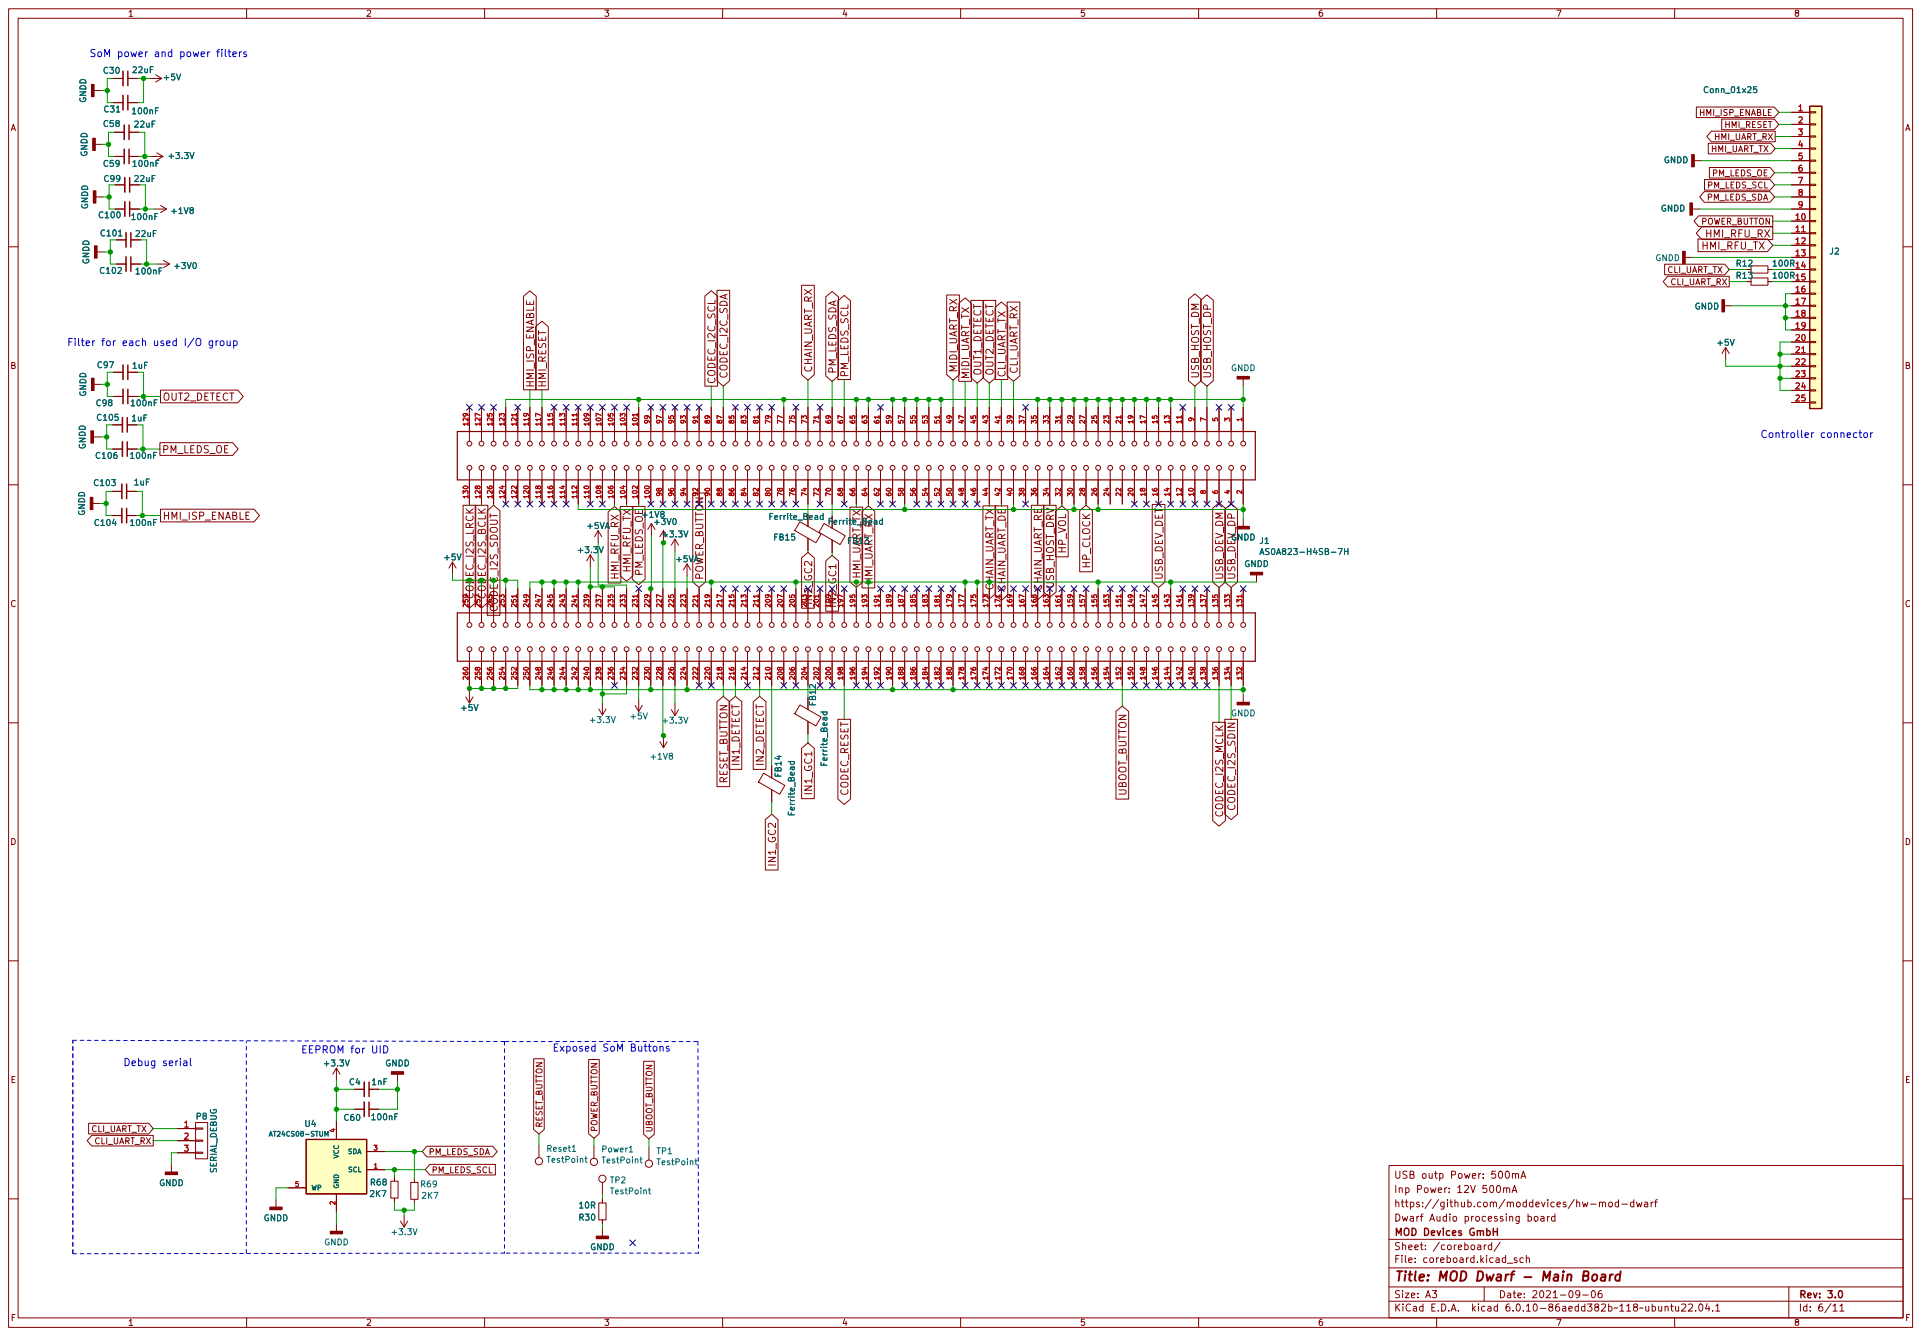
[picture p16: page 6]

SoM power and power filters

USB outp Power: 500mA
Inp Power: 12V 500mA
https://github.com/moddevices/hw-mod-dwarf
Dwarf Audio processing board
File: coreboard.kicad_sch Sheet: /coreboard/ MOD Devices GmbH

Id: 6/11 Title: MOD Dwarf - Main Board

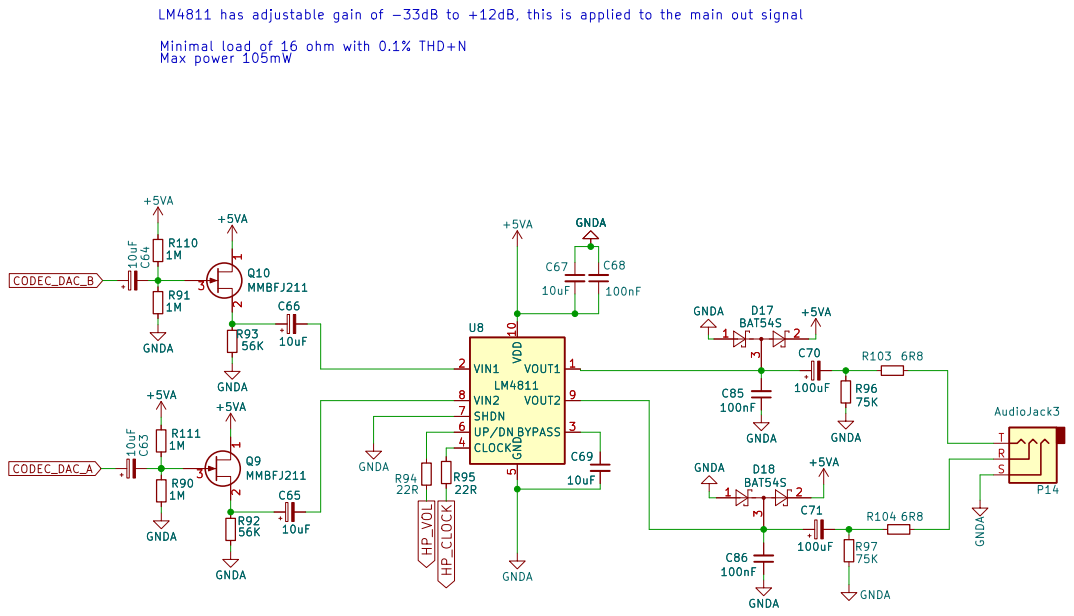
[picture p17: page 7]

Minimal load of 16 ohm with 0.1% THD+N

USB outp Power: 500mA
Inp Power: 12V 500mA
https://github.com/moddevices/hw-mod-dwarf
Dwarf Audio processing board
Sheet: /headphone/ MOD Devices GmbH

File: Headphone.kicad_sch
Id: 7/11 Title: MOD Dwarf - Main Board

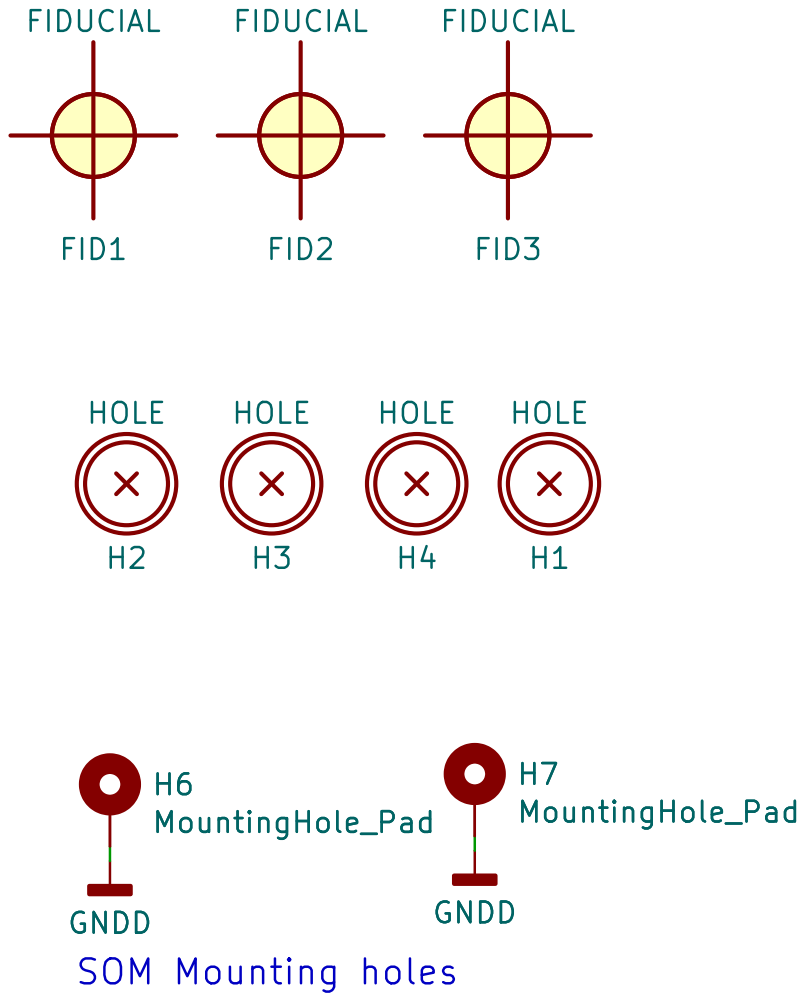
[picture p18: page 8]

USB outp Power: 500mA
Inp Power: 12V 500mA
https://github.com/moddevices/hw-mod-dwarf
Dwarf Audio processing board
File: mechanics.kicad_sch Sheet: /mechanics/ MOD Devices GmbH

Id: 8/11 Title: MOD Dwarf - Main Board

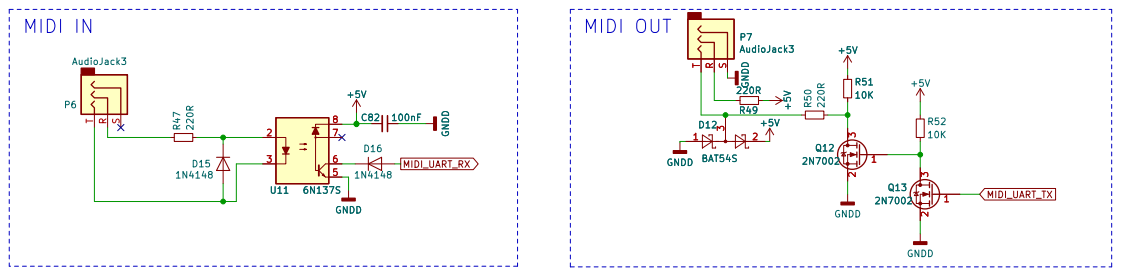
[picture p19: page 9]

USB outp Power: 500mA
Inp Power: 12V 500mA
https://github.com/moddevices/hw-mod-dwarf
Dwarf Audio processing board
File: midi.kicad_sch Sheet: /midi/ MOD Devices GmbH

Id: 9/11 Title: MOD Dwarf - Main Board

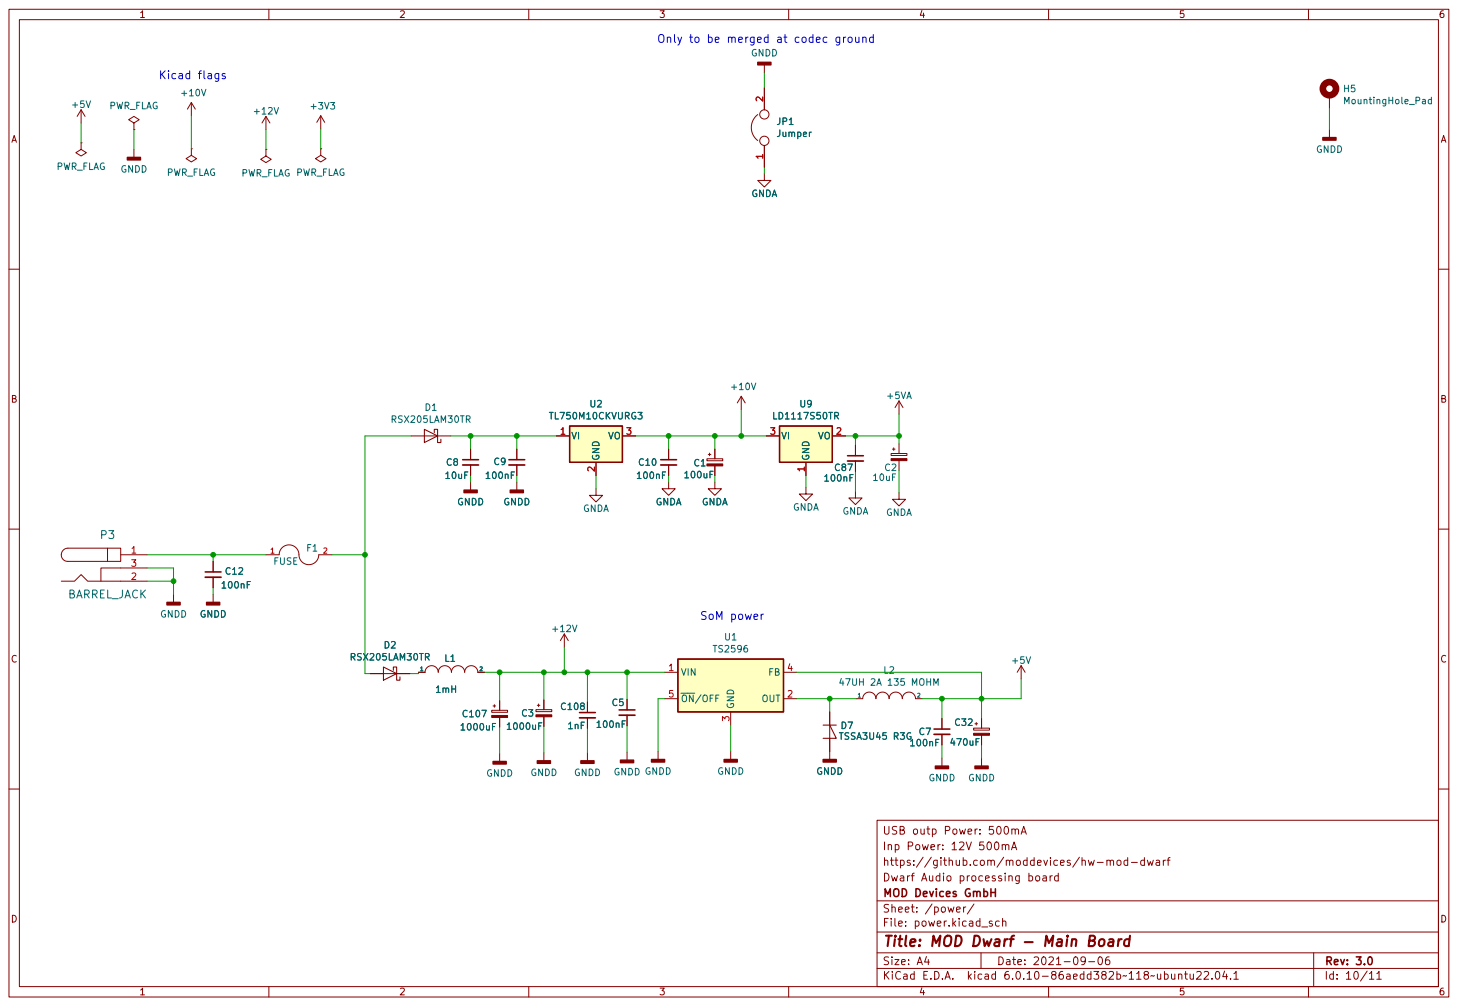
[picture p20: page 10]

Only to be merged at codec ground
Jumper GNDA GNDD

USB outp Power: 500mA
Inp Power: 12V 500mA
https://github.com/moddevices/hw-mod-dwarf
Dwarf Audio processing board
Sheet: /power/ MOD Devices GmbH

File: power.kicad_sch
Id: 10/11 Title: MOD Dwarf - Main Board

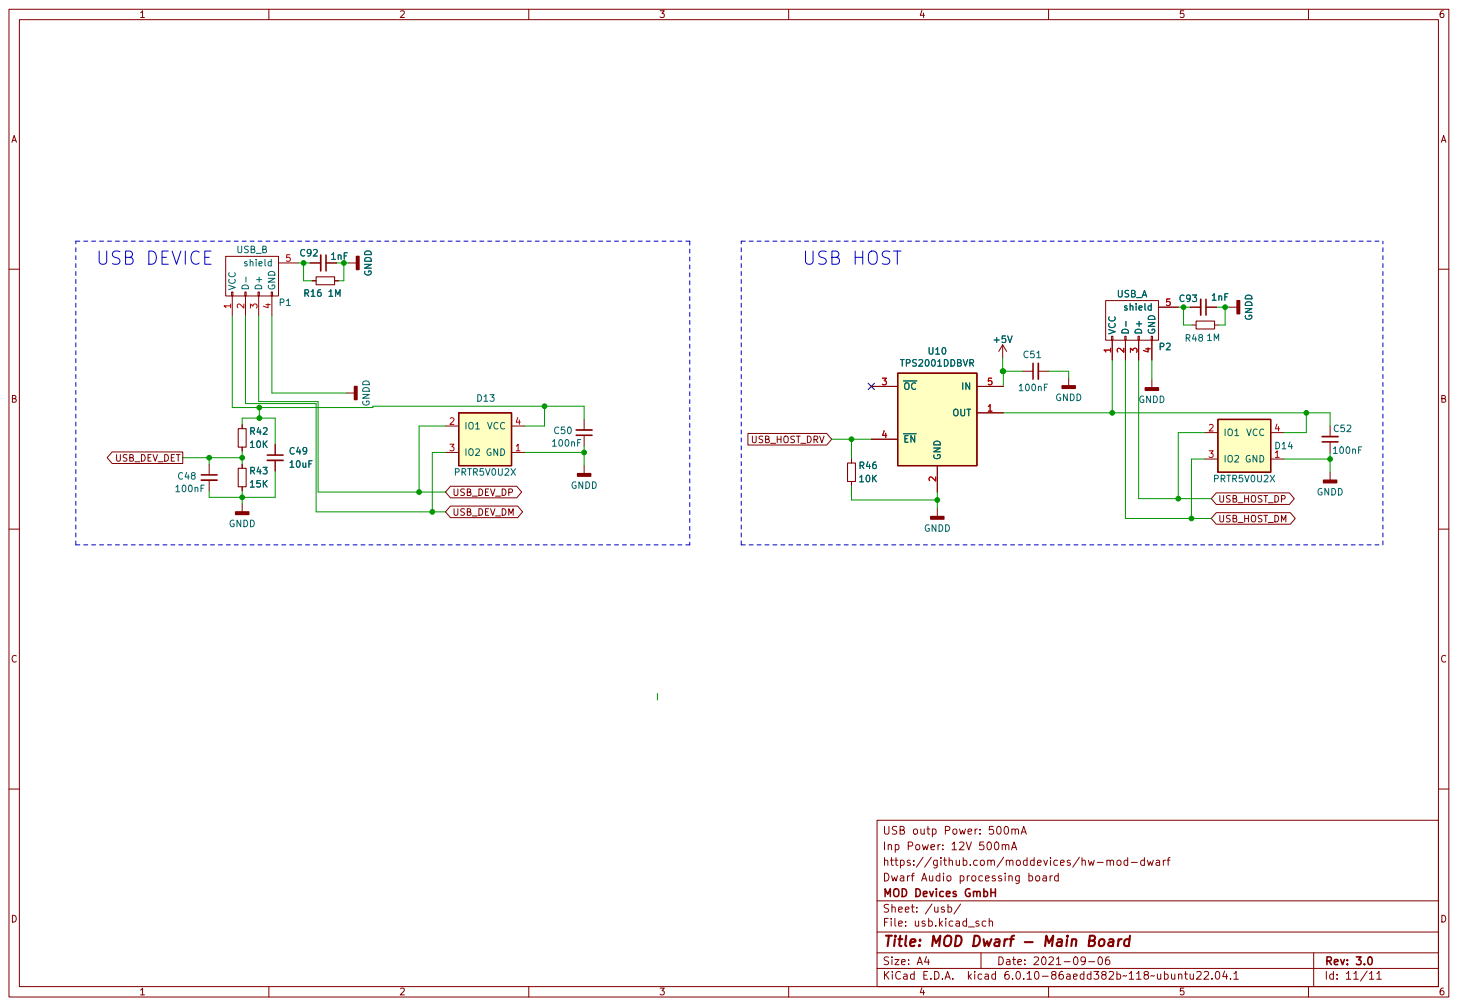
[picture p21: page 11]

Inp Power: 12V 500mA
https://github.com/moddevices/hw-mod-dwarf
Dwarf Audio processing board
File: usb.kicad_sch Sheet: /usb/ MOD Devices GmbH

Id: 11/11 Title: MOD Dwarf - Main Board

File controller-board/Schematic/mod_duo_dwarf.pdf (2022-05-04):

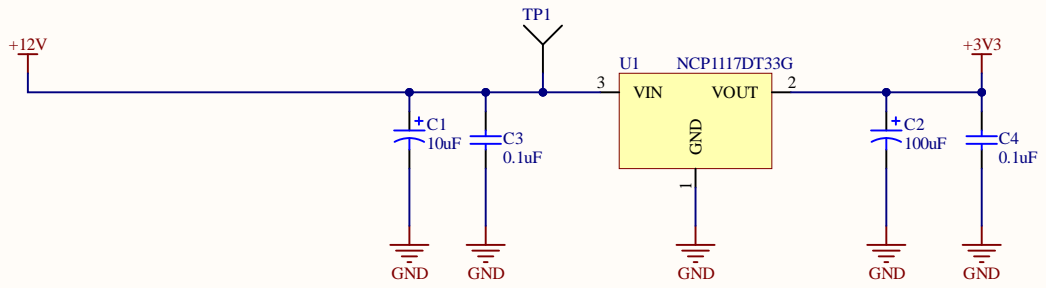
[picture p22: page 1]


P M _ LED S _ S CL 7
P M _ LED S _ S D A 8





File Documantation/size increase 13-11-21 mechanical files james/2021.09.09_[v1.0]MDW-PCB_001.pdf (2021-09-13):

Foot Switches; Screw Bosses; HMI Receptical; Firefly PX30 SoM; 260P DDR4 5.2 STD Connector

HMI Receptical (TOP)
[8.7mm clearance]
HMI Cable Connector (TOP)
[4.6mm clearance]

Cut Layer
Jacks
Foot Switches [8-14mm clearance]
HMI Center Line
Screw Bosses [0mm clearance]
Firefly PX30 SoM
260P DDR4 5.2 STD Connector
HMI Receptical (TOP) [8.7mm clearance]
HMI Cable Connector (TOP) [4.6mm clearance]

HMI Cable Connector


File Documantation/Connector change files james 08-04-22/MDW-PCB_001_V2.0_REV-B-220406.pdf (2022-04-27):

Foot Switches [8-14mm clearance]; Screw Bosses; Firefly PX30 SoM; 260P DDR4 5.2 STD Connector; THIS DRAWING AND ASSOCIATED COMPUTER DATA ARE AND WILL REMAIN THE EXCLUSIVE PROPERTY OF MOD DEVICES GMBH

PCB MATERIAL | FR-4
PCB THICKNESS | 1.6 mm
COPPER THICKNESS | 1 oz
SOLDERMASK COLOUR | BLACK
SILKSCREEN COLOUR | WHITE
MATERIAL FINISH | ENIG
IMPEDANCE CONTROL | NONE

HMI FFC Cable
Flexible but should not be
blocked by large componnents

Cut Layer
Jacks
Foot Switches [8-14mm clearance]
HMI FFC Cable Center Line
Screw Bosses [0mm clearance]
Firefly PX30 SoM
260P DDR4 5.2 STD Connector

HMI FFC Connector

THIRD ANGLE PROJECTION
DIMENSION IN MILLIMETERS
DIMENSIONS WITHOUT TOLERANCES

Part Number MDW-PCB_001 | Part Description Main Board

PER ISO 2768-m K
DO NOT SCALE

MOD DEVICES GMBH | Part Version V2.0 | Design JD | Date 6/04/2022 | Comment Change to FFC ribbon connector

Material Description FR-4 | Manufacturing Method PCB | Finish ENIG

Product Dwarf | Volume 28.7cm3 | Drawn JD | Date 26/05/2020 | Title Component Layout Drawing | Scale 1:1 | B Rev.

B | NEW VERSION, NEW NAMING AND DRAWING TEMPLATE | 6/04/2022 | JD | Category Printed Circuit Board | Weight 70.1g | Approved | Date | Sheet Name Layout | Sheet | A3 Size
A | ISSUED FOR PCBA DESIGN | 26/05/2020 | JD
REV | DESCRIPTION | DATE | NAME

THEY MUST NOT BE REPRODUCED, COPIED, DISTRIBUTED OR BROUGHT TO THE KNOWLEDGE OF ANY THIRD PARTY WITHOUT WRITTEN PERMISSION FROM MOD DEVICES GMBH.

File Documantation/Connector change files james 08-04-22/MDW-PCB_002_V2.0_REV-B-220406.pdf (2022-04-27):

HMI FFC Cable Center Line; LEDs; Screw Bosses; Tactile Switches; THIS DRAWING AND ASSOCIATED COMPUTER DATA ARE AND WILL REMAIN THE EXCLUSIVE PROPERTY OF MOD DEVICES GMBH

PCB MATERIAL | FR-4 | LCD Bracket
PCB THICKNESS | 1.6 mm
COPPER THICKNESS | 1 oz
SOLDERMASK COLOUR | BLACK
SILKSCREEN COLOUR | WHITE
MATERIAL FINISH | LF-HASL RoHS
IMPEDANCE CONTROL | NONE

**4 LEDs inside buttons
should be positioned
as far downward or
as close to the tactile
switch as possible**

Cut Layer
HMI FFC Cable Center Line
Rotary Encoders
LED Positions
Silicone Buttons [0mm Clearance]
Tactile Switches
LCD Bracket [2mm Clearance]
Silk screen labels "DISP" "DISP - BL" Display Connectors
LCD Cables
Screw Bosses [0mm Clearance]
Footswitch JST Connectors

Ribbon connector to edge of board
Insert Direction
Display Connectors
**AS CLOSE TO EDGE OF BOARD AS POSSIBLE**

HMI FFC Connector
**AS CLOSE TO EDGE
OF BOARD AS POSSIBLE**

Silk screen labels "FS - A" "FS - B" "FS - C"

THIRD ANGLE PROJECTION
DIMENSION IN MILLIMETERS
DIMENSIONS WITHOUT TOLERANCES

Part Number MDW-PCB_002 | Part Description Controller Board

PER ISO 2768-m K
DO NOT SCALE

MOD DEVICES GMBH | Part Version V2.0 | Design JD | Date 6/04/2022 | Comment Change to FFC ribbon connector, JST connectors for footswitches

Material Description FR-4 | Manufacturing Method PCB | Finish LF-HASL RoHS

Product Dwarf | Volume 0.0cm3 | Drawn JD | Date 26/05/2020 | Title Component Layout Drawing | Scale 1:1 | B Rev.
Category Printed Circuit Board | Weight 0.1g | Approved | Date | Sheet Name Layout | Sheet | A3 Size

B | NEW VERSION, NEW NAMING AND DRAWING TEMPLATE | 6/04/2022 | JD
A | ISSUED FOR PCBA DESIGN | 26/05/2020 | JD
REV | DESCRIPTION | DATE | NAME

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



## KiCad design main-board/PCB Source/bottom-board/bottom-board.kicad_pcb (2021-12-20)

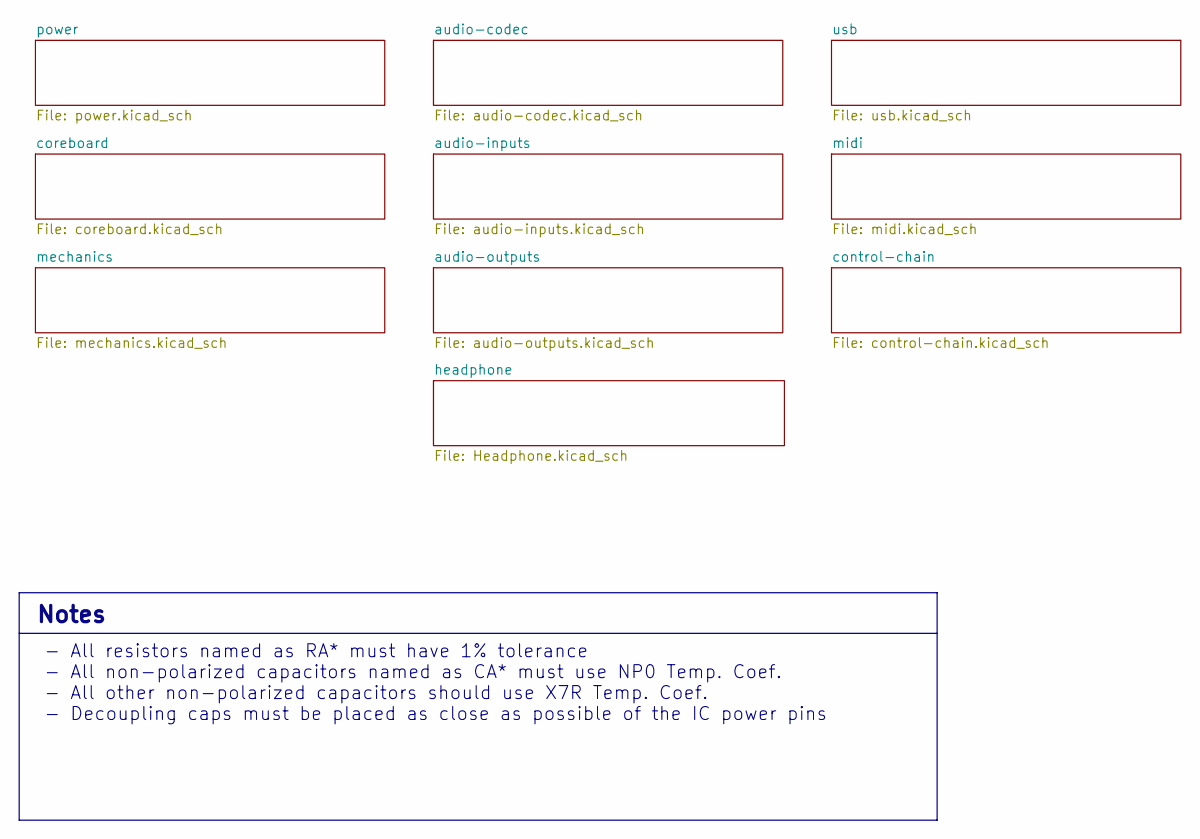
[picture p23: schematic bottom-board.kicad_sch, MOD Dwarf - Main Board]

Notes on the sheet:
- All resistors named as RA* must have 1% tolerance - All non-polarized capacitors named as CA* must use NP0 Temp. Coef. - All other non-polarized capacitors should use X7R Temp. Coef. - Decoupling caps must be placed as close as possible of the IC power pins
Notes

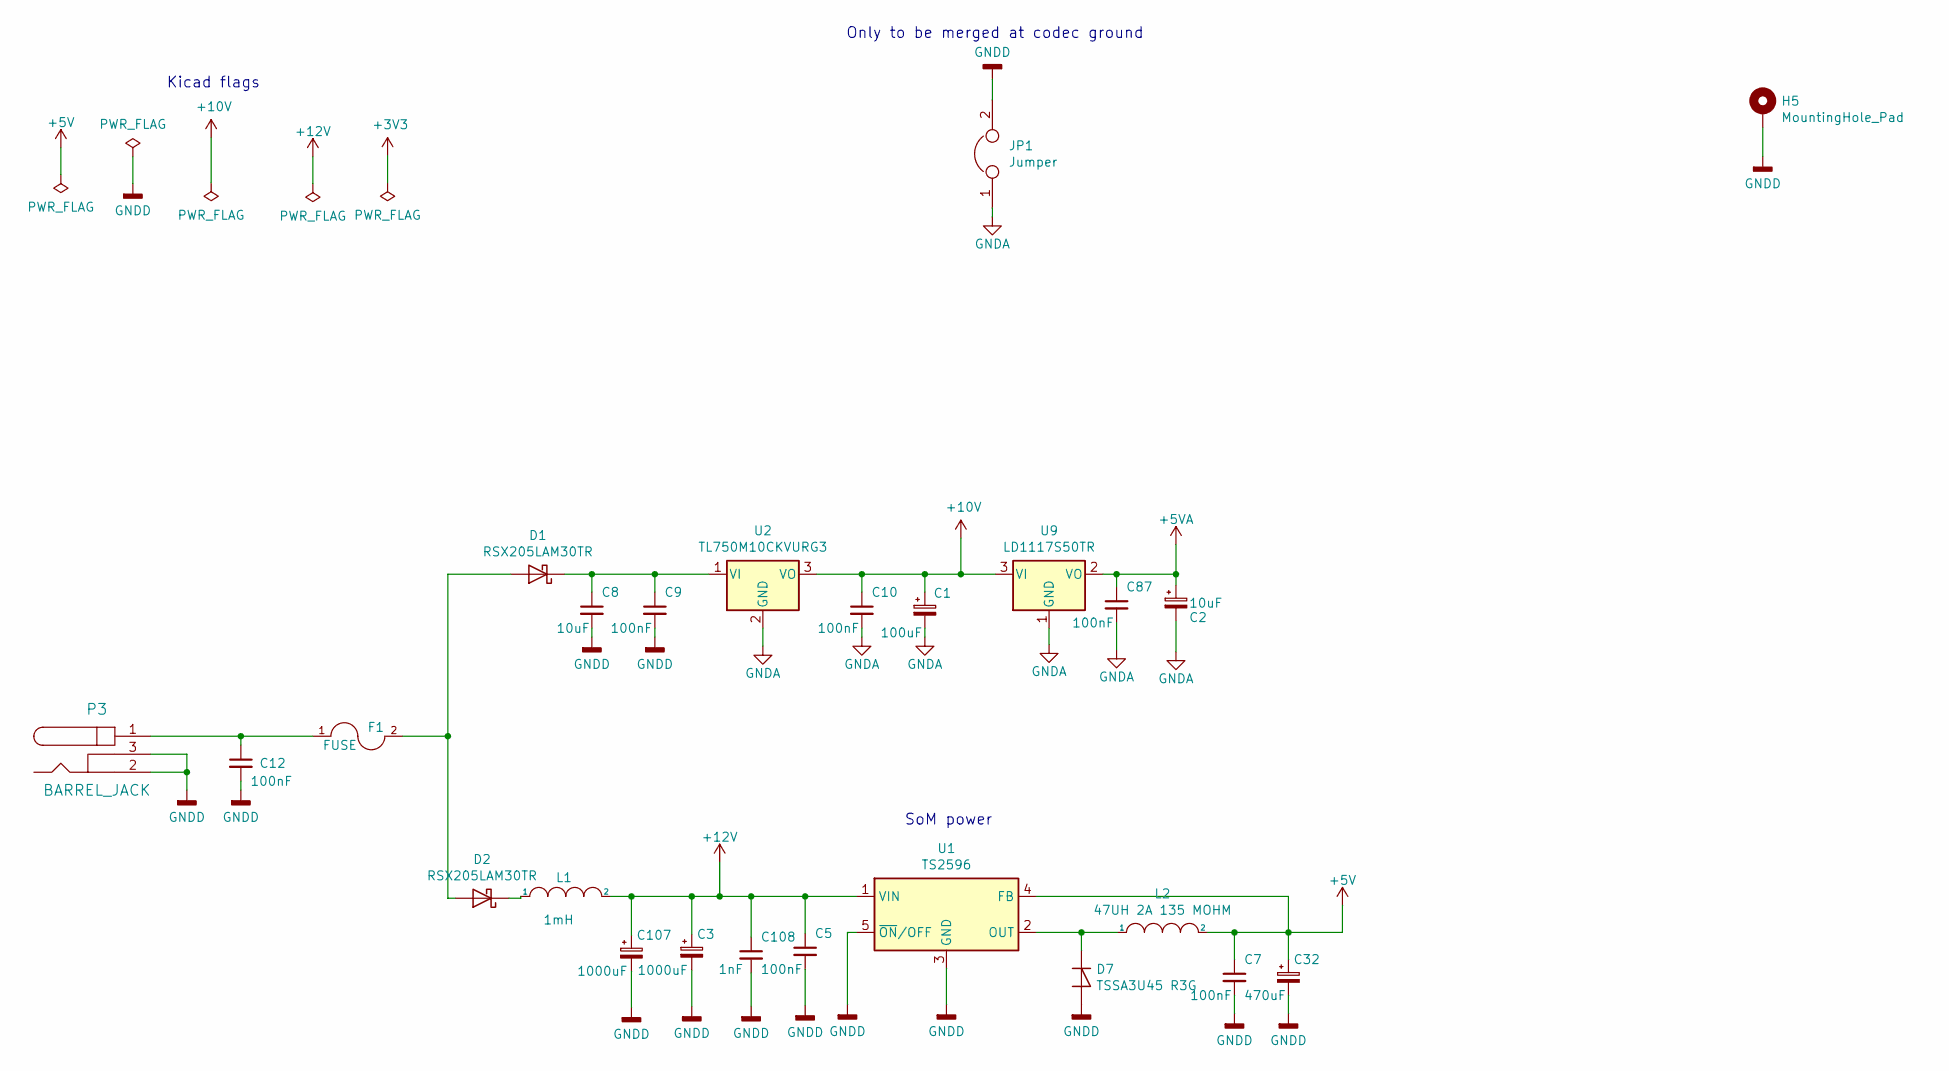
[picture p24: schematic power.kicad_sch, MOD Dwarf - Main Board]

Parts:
C1: 100uF; CP_Elec_6.3x7.7; MPN 107SML016M
C2: 10uF; CP_Elec_4x5.7; MPN EEE-HB1C100R
C3, C107: 1000uF; CP_Elec_10x10.5; MPN UCM1C102MNL1GS
C5, C7, C9, C10, C12, C87: 100nF; C_0603_1608Metric; MPN GCM188R71C104KA37D
C8: 10uF; C_0805_2012Metric; MPN GRM219R61E106KA12D
C32: 470uF; CP_Elec_8x10.5; MPN UCW1C471MNL1GS
C108: 1nF; C_0603_1608Metric; MPN C0603X7R500-103KNP
D1, D2: RSX205LAM30TR; D_SOD-128; MPN RSX205LAM30TR
D7: TSSA3U45 R3G; D_MELF; MPN TSSA3U45 R3G
F1: FUSE; Fuse_2920_7451Metric; MPN 0ZCF0200FF2C
H5: MountingHole_Pad; MountingHole_3.2mm_M3_DIN965_Pad
JP1: Jumper; SolderJumper-2_P1.3mm_Bridged2Bar_RoundedPad1.0x1.5mm
L1: 1mH; L_Bourns_SRR1260; MPN SRR1260-102K
L2: 47UH 2A 135 MOHM; SRN8040TA; MPN SRN8040TA-470M
P3: BARREL_JACK; BarrelJack_Horizontal; MPN PJ-002AH
U1: TS2596; TO-263-5_TabPin3; MPN TS2596CM550 RNG
U2: TL750M10CKVURG3; TO-252-3_TabPin2; MPN TL750M10CKVURG3
U9: LD1117S50TR; SOT-223-3_TabPin2; MPN LD1117S50TR

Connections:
+5V: C7.1, C32.1, L2.2, U1.4 (FB); also elsewhere on the board
+5VA: C2.1, C87.1, U9.2 (VO); also elsewhere on the board
+10V: C1.1, C10.1, U2.3 (VO), U9.3 (VI); also elsewhere on the board
+12V: C3.1, C5.1, C107.1, C108.1, L1.2, U1.1 (VIN); also elsewhere on the board
GNDA: C1.2, C2.2, C10.2, C87.2, JP1.1, U2.2 (GND), U9.1 (GND); also elsewhere on the board
GNDD: C3.2, C5.2, C7.2, C8.2, C9.2, C12.2, C32.2, C107.2, C108.2, D7.2 (A), H5.1, JP1.2, P3.2, P3.3, U1.3 (GND), U1.5 (~ON/OFF); also elsewhere on the board
unnamed: C8.1, C9.1, D1.1 (K), U2.1 (VI)
unnamed: C12.1, F1.1, P3.1
unnamed: D1.2 (A), D2.2 (A), F1.2
unnamed: D2.1 (K), L1.1
unnamed: D7.1 (K), L2.1, U1.2 (OUT)

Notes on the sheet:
SoM power
Only to be merged at codec ground
Kicad flags

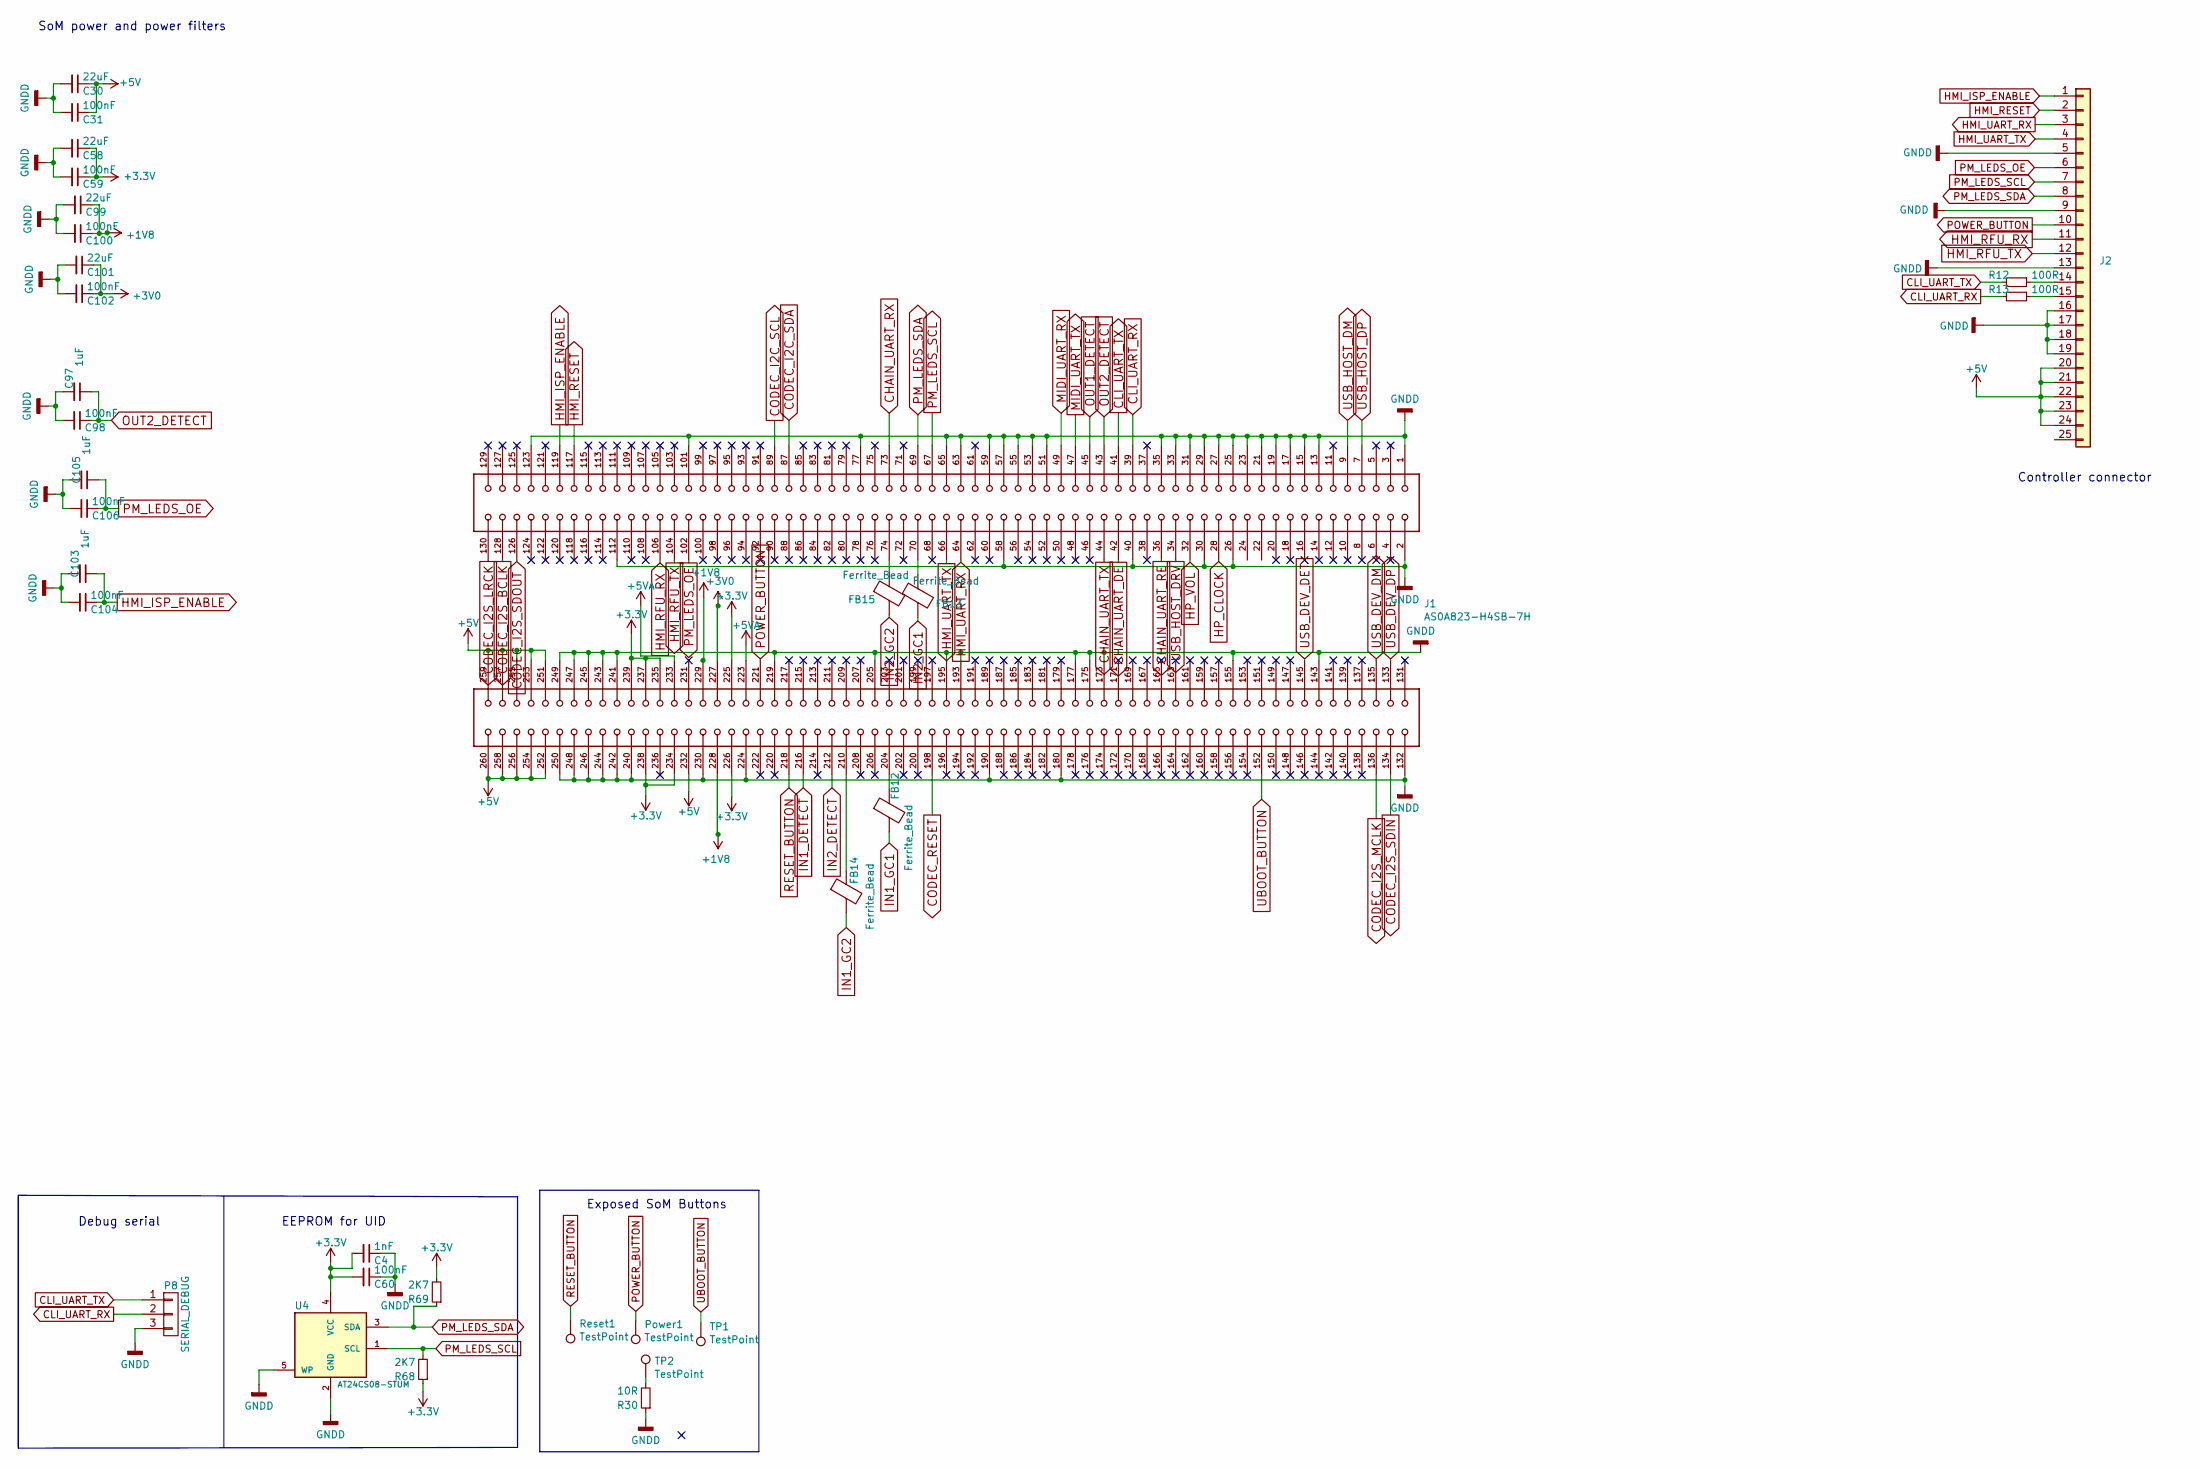
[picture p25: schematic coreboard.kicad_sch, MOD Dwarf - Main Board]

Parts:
C4: 1nF; C_0603_1608Metric; MPN C0603X7R500-103KNP
C30, C58, C99, C101: 22uF; C_0805_2012Metric; MPN CL21A226MPQNNNE
C31, C59, C60, C98, C100, C102, C104, C106: 100nF; C_0603_1608Metric; MPN GCM188R71C104KA37D
C97, C103, C105: 1uF; C_0603_1608Metric; MPN TMK107B7105KA-T
FB12, FB13, FB14, FB15: Ferrite_Bead; R_0603_1608Metric; MPN BLM18HD102SH1D
J1: AS0A823-H4SB-7H; TE_2309409-1; MPN TE_2309409-1
J2: MPN F51L-1A7H1-11024
P8: SERIAL_DEBUG; PinHeader_1x03_P2.54mm_Vertical; MPN DO NOT PLACE
Power1: TestPoint; TestPoint_Pad_D1.5mm
R12, R13: 100R; R_0603_1608Metric; MPN RT0603DRD07100RL
R30: 10R; R_0603_1608Metric; MPN CRGCQ0603J10R
R68, R69: 2K7; R_0603_1608Metric; MPN CRGCQ0603F2K7
Reset1: TestPoint; TestPoint_Pad_D1.5mm
TP1, TP2: TestPoint; TestPoint_Loop_D1.80mm_Drill1.0mm_Beaded
U4: AT24CS08-STUM; SOT-23-5; MPN AT24CS08-STUM

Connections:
+1V8: C99.1, C100.1, J1.228, J1.229
+3V0: C101.1, C102.1, J1.227
+5V: C30.1, C31.1, J1.232, J1.251, J1.252, J1.253, J1.254, J1.255, J1.256, J1.257, J1.258, J1.259, J1.260, J2.20, J2.21, J2.22, J2.23, J2.24; also elsewhere on the board
+5VA: J1.223, J1.233; also elsewhere on the board
CHAIN_UART_DE: J1.42; also elsewhere on the board
CHAIN_UART_RE: J1.36; also elsewhere on the board
CHAIN_UART_RX: J1.73; also elsewhere on the board
CHAIN_UART_TX: J1.44; also elsewhere on the board
CLI_UART_RX: J1.39, P8.2, R13.2
CLI_UART_TX: J1.41, P8.1, R12.2
CODEC_I2C_SCL: J1.89; also elsewhere on the board
CODEC_I2C_SDA: J1.87; also elsewhere on the board
CODEC_I2S_BCLK: J1.128; also elsewhere on the board
CODEC_I2S_LRCK: J1.130; also elsewhere on the board
CODEC_I2S_MCLK: J1.136; also elsewhere on the board
CODEC_I2S_SDIN: J1.134; also elsewhere on the board
CODEC_I2S_SDOUT: J1.126; also elsewhere on the board
CODEC_RESET: J1.198; also elsewhere on the board
GNDD: C4.1, C30.2, C31.2, C58.2, C59.2, C60.1, C97.2, C98.2, C99.2, C100.2, C101.2, C102.2, C103.2, C104.2, C105.2, C106.2, J1.1, J1.2, J1.13, J1.15, J1.17, J1.19, J1.21, J1.23, J1.25, J1.26, J1.27, J1.29, J1.30, J1.31, J1.33, J1.35, J1.40, J1.51, J1.53, J1.55, J1.57, J1.58, J1.59, J1.63, J1.65, J1.77, J1.101, J1.112, J1.123, J1.132, J1.143, J1.155, J1.173, J1.175, J1.177, J1.180, J1.190, J1.193, J1.195, J1.205, J1.219, J1.224, J1.230, J1.240, J1.241, J1.242, J1.243, J1.244, J1.245, J1.246, J1.247, J1.248, J1.249, J1.250, J2.5, J2.9, J2.13, J2.16, J2.17, J2.18, J2.19, P8.3, R30.1, U4.2 (GND), U4.5 (WP); also elsewhere on the board
HMI_ISP_ENABLE: C103.1, C104.1, J1.119, J2.1; also elsewhere on the board
HMI_RESET: J1.117, J2.2; also elsewhere on the board
HMI_RFU_RX: J1.106, J2.11; also elsewhere on the board
HMI_RFU_TX: J1.104, J2.12; also elsewhere on the board
HMI_UART_RX: J1.64, J2.3; also elsewhere on the board
HMI_UART_TX: J1.66, J2.4; also elsewhere on the board
HP_CLOCK: J1.28; also elsewhere on the board
HP_VOL: J1.32; also elsewhere on the board
IN1_DETECT: J1.216; also elsewhere on the board
IN1_GC1: FB12.2; also elsewhere on the board
IN1_GC2: FB14.2; also elsewhere on the board
IN2_DETECT: J1.212; also elsewhere on the board
IN2_GC1: FB13.2; also elsewhere on the board
IN2_GC2: FB15.2; also elsewhere on the board
MIDI_UART_RX: J1.49; also elsewhere on the board
MIDI_UART_TX: J1.47; also elsewhere on the board
unnamed: FB12.1, J1.204
unnamed: FB13.1, J1.70
unnamed: FB14.1, J1.210
unnamed: FB15.1, J1.74
unnamed 122: J2.14, R12.1; also elsewhere on the board
unnamed 123: J2.15, R13.1; also elsewhere on the board
unnamed: R30.2, TP2.1
OUT1_DETECT: J1.45; also elsewhere on the board
OUT2_DETECT: C97.1, C98.1, J1.43; also elsewhere on the board
PM_LEDS_OE: C105.1, C106.1, J1.102, J2.6; also elsewhere on the board
PM_LEDS_SCL: J1.67, J2.7, R68.2, U4.1 (SCL); also elsewhere on the board
PM_LEDS_SDA: J1.69, J2.8, R69.1, U4.3 (SDA); also elsewhere on the board
POWER_BUTTON: J1.221, J2.10, Power1.1; also elsewhere on the board
RESET_BUTTON: J1.218, Reset1.1; also elsewhere on the board
UBOOT_BUTTON: J1.152, TP1.1
USB_DEV_DET: J1.145; also elsewhere on the board
USB_DEV_DM: J1.135; also elsewhere on the board
USB_DEV_DP: J1.133; also elsewhere on the board
USB_HOST_DM: J1.9; also elsewhere on the board
USB_HOST_DP: J1.7; also elsewhere on the board
USB_HOST_DRV: J1.34; also elsewhere on the board

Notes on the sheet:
SoM power and power filters
Debug serial
Exposed SoM Buttons
EEPROM for UID
Controller connector

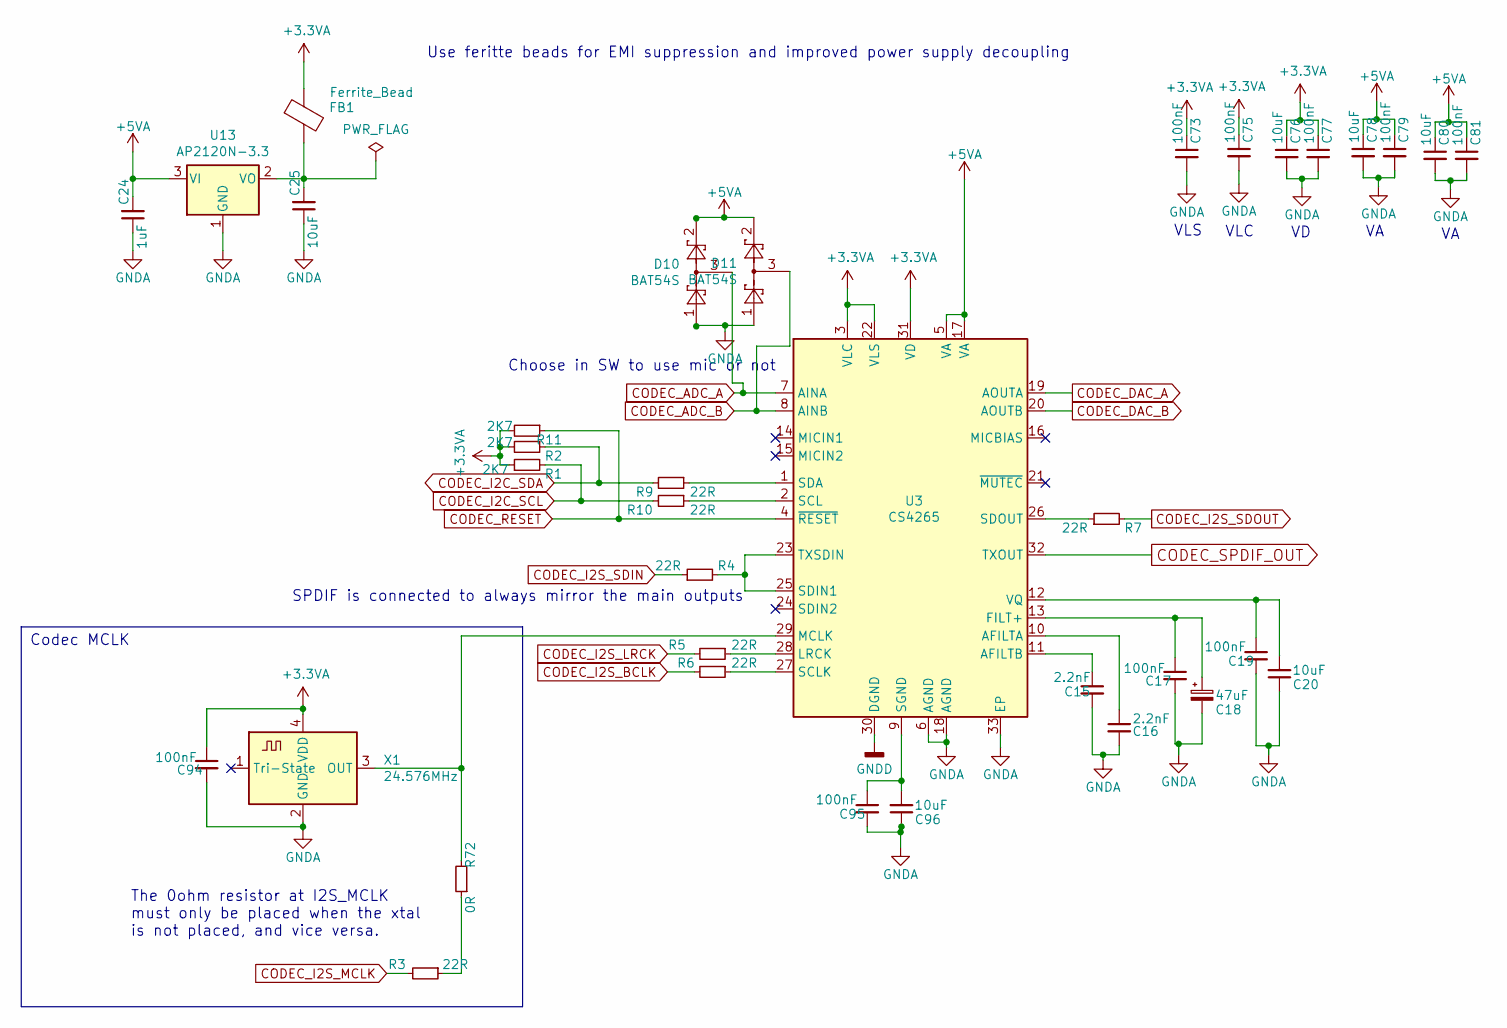
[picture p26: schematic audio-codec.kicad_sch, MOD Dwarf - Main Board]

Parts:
C15, C16: 2.2nF; C_0603_1608Metric; MPN GRM1885C1H222JA01D
C17, C19, C73, C75, C77, C79, C81, C94, C95: 100nF; C_0603_1608Metric; MPN GCM188R71C104KA37D
C18: 47uF; CP_Elec_5x5.4; MPN EDK476M016A9DAA
C20, C25, C76, C78, C80, C96: 10uF; C_0805_2012Metric; MPN GRM219R61E106KA12D
C24: 1uF; C_0603_1608Metric; MPN TMK107B7105KA-T
D10, D11: BAT54S; SOT-23; MPN BAT54SFILM
FB1: Ferrite_Bead; R_0603_1608Metric; MPN BLM18HD102SH1D
R1, R2, R11: 2K7; R_0603_1608Metric; MPN CRGCQ0603F2K7
R3, R4, R5, R6, R7, R9, R10: 22R; R_0603_1608Metric; MPN RMCF0603JT22R0
R72: 0R; R_0603_1608Metric; MPN RMCF0603ZT0R00
U3: CS4265; QFN-32-1EP_5x5mm_P0.5mm_EP3.1x3.1mm; MPN CS4265-CNZ
U13: AP2120N-3.3; SOT-23; MPN AP2120N-3.3TRG1
X1: 24.576MHz; Oscillator_SMD_Abracon_ASV-4Pin_7.0x5.1mm; MPN DO NOT PLACE

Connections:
+3.3VA: C73.1, C75.1, C76.1, C77.1, C94.1, FB1.1, R1.1, R2.2, R11.2, U3.3 (VLC), U3.22 (VLS), U3.31 (VD), X1.4 (VDD)
+5VA: C24.2, C78.1, C79.1, C80.1, C81.1, D10.2, D11.2, U3.5 (VA), U3.17 (VA), U13.3 (VI); also elsewhere on the board
CODEC_ADC_A: D10.3, U3.7 (AINA); also elsewhere on the board
CODEC_ADC_B: D11.3, U3.8 (AINB); also elsewhere on the board
CODEC_DAC_A: U3.19 (AOUTA); also elsewhere on the board
CODEC_DAC_B: U3.20 (AOUTB); also elsewhere on the board
CODEC_I2C_SCL: R1.2, R10.2; also elsewhere on the board
CODEC_I2C_SDA: R2.1, R9.2; also elsewhere on the board
CODEC_I2S_BCLK: R6.2; also elsewhere on the board
CODEC_I2S_LRCK: R5.2; also elsewhere on the board
CODEC_I2S_MCLK: R3.2; also elsewhere on the board
CODEC_I2S_SDIN: R4.1; also elsewhere on the board
CODEC_I2S_SDOUT: R7.2; also elsewhere on the board
CODEC_RESET: R11.1, U3.4 (~RESET); also elsewhere on the board
GNDA: C15.2, C16.2, C17.2, C18.2, C19.2, C20.1, C24.1, C25.1, C73.2, C75.2, C76.2, C77.2, C78.2, C79.2, C80.2, C81.2, C94.2, C95.2, C96.1, D10.1, D11.1, U3.6 (AGND), U3.18 (AGND), U3.33 (EP), U13.1 (GND), X1.2 (GND); also elsewhere on the board
GNDD: U3.30 (DGND); also elsewhere on the board
unnamed: C15.1, U3.11 (AFILTB)
unnamed: C16.1, U3.10 (AFILTA)
unnamed: C17.1, C18.1, U3.13 (FILT+)
unnamed: C19.1, C20.2, U3.12 (VQ)
unnamed: C25.2, FB1.2, U13.2 (VO)
unnamed: C95.1, C96.2, U3.9 (SGND)
unnamed: R3.1, R72.1
unnamed: R4.2, U3.23 (TXSDIN), U3.25 (SDIN1)
unnamed: R5.1, U3.28 (LRCK)
unnamed: R6.1, U3.27 (SCLK)
unnamed: R7.1, U3.26 (SDOUT)
unnamed: R9.1, U3.1 (SDA)
unnamed: R10.1, U3.2 (SCL)
unnamed: R72.2, U3.29 (MCLK), X1.3 (OUT)

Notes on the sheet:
Use feritte beads for EMI suppression and improved power supply decoupling
VLS
Choose in SW to use mic or not
Codec MCLK
VLC
SPDIF is connected to always mirror the main outputs
The 0ohm resistor at I2S_MCLK must only be placed when the xtal is not placed, and vice versa.

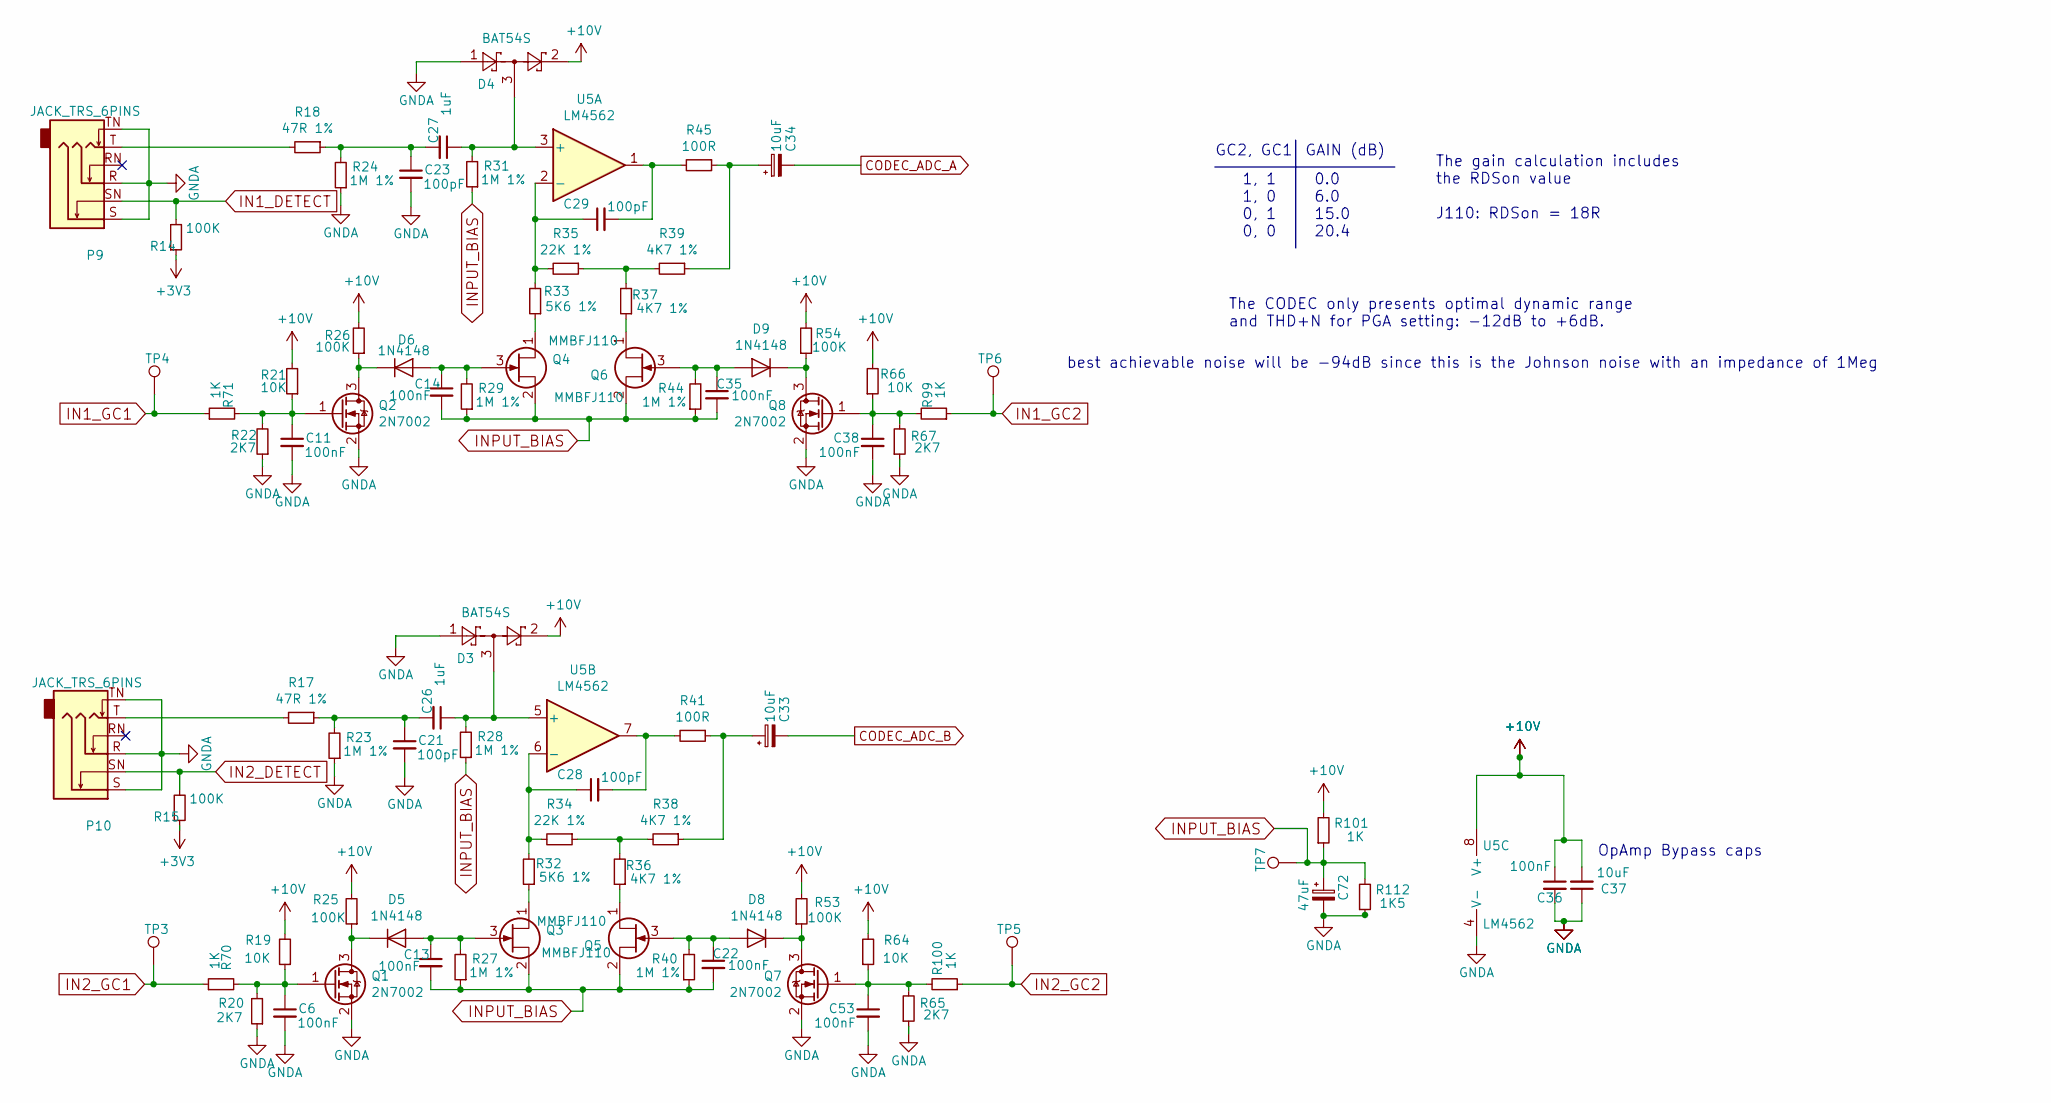
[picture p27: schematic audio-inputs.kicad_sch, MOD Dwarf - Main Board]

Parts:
C6, C11, C13, C14, C22, C35, C36, C38, C53: 100nF; C_0603_1608Metric; MPN GCM188R71C104KA37D
C21, C23, C28, C29: 100pF; C_0603_1608Metric; MPN C0603C101J3GACTU
C26, C27: 1uF; C_0603_1608Metric; MPN TMK107B7105KA-T
C33, C34: 10uF; CP_Elec_4x5.7; MPN EEE-HB1C100R
C37: 10uF; C_0805_2012Metric; MPN GRM219R61E106KA12D
C72: 47uF; CP_Elec_5x5.4; MPN EDK476M016A9DAA
D3, D4: BAT54S; SOT-23; MPN BAT54SFILM
D5, D6, D8, D9: 1N4148; D_SOD-323; MPN 1N4148WS
P9, P10: JACK_TRS_6PINS; Jack_3.5mm_Neutrik_NMJ6HCD2_Horizontal; MPN NYS215
Q1, Q2, Q7, Q8: 2N7002; SOT-23; MPN 2N7002P,215
Q3, Q4, Q5, Q6: MMBFJ110; SOT-23; MPN MMBFJ110
R14, R15, R25, R26, R53, R54: 100K; R_0603_1608Metric; MPN RMCF0603JT100K
R17, R18: 47R 1%; R_0603_1608Metric; MPN RT0603DRE0747RL
R19, R21, R64, R66: 10K; R_0603_1608Metric; MPN RR0816P-103-D
R20, R22, R65, R67: 2K7; R_0603_1608Metric; MPN CRGCQ0603F2K7
R23, R24, R27, R28, R29, R31, R40, R44: 1M 1%; R_0603_1608Metric; MPN RT0603BRD071ML
R32, R33: 5K6 1%; R_0603_1608Metric; MPN ERA-3AED562V
R34, R35: 22K 1%; R_0603_1608Metric; MPN RT0603DRD0722KL
R36, R37, R38, R39: 4K7 1%; R_0603_1608Metric; MPN RT0603DRE074K7L
R41, R45: 100R; R_0603_1608Metric; MPN RT0603DRD07100RL
R70, R71, R99, R100, R101: 1K; R_0603_1608Metric; MPN ERJ-PB3D1001V
R112: 1K5; R_0603_1608Metric
TP3, TP4, TP5, TP6: TestPoint; TestPoint_Pad_D1.0mm
TP7: TestPoint; TestPoint_Pad_D2.0mm
U5: LM4562; SOIC-8_3.9x4.9mm_P1.27mm; MPN LM4562MAX/NOPB

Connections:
+10V: C36.1, C37.2, D3.2, D4.2, R19.2, R21.2, R25.2, R26.2, R53.2, R54.2, R64.2, R66.2, R101.2, U5.8 (V+); also elsewhere on the board
CODEC_ADC_A: C34.2; also elsewhere on the board
CODEC_ADC_B: C33.2; also elsewhere on the board
GNDA: C6.2, C11.2, C21.2, C23.2, C36.2, C37.1, C38.2, C53.2, C72.2, D3.1, D4.1, P9.R, P9.S, P9.TN, P10.R, P10.S, P10.TN, Q1.2 (S), Q2.2 (S), Q7.2 (S), Q8.2 (S), R20.1, R22.1, R23.1, R24.1, R65.1, R67.1, R112.1, U5.4 (V-); also elsewhere on the board
IN1_DETECT: P9.SN, R14.2; also elsewhere on the board
IN1_GC1: R71.1, TP4.1; also elsewhere on the board
IN1_GC2: R99.1, TP6.1; also elsewhere on the board
IN2_DETECT: P10.SN, R15.2; also elsewhere on the board
IN2_GC1: R70.1, TP3.1; also elsewhere on the board
IN2_GC2: R100.1, TP5.1; also elsewhere on the board
INPUT_BIAS: C13.2, C14.2, C22.2, C35.2, C72.1, Q3.2 (S), Q4.2 (S), Q5.2 (S), Q6.2 (S), R27.1, R28.1, R29.1, R31.1, R40.1, R44.1, R101.1, R112.2, TP7.1
unnamed: C6.1, Q1.1 (G), R19.1, R20.2, R70.2
unnamed: C11.1, Q2.1 (G), R21.1, R22.2, R71.2
unnamed: C13.1, D5.2 (A), Q3.3 (G), R27.2
unnamed: C14.1, D6.2 (A), Q4.3 (G), R29.2
unnamed: C21.1, C26.2, R17.1, R23.2
unnamed: C22.1, D8.2 (A), Q5.3 (G), R40.2
unnamed: C23.1, C27.2, R18.1, R24.2
unnamed: C26.1, D3.3, R28.2, U5.5 (+)
unnamed: C27.1, D4.3, R31.2, U5.3 (+)
unnamed: C28.1, R32.2, R34.2, U5.6 (-)
unnamed: C28.2, R41.2, U5.7
unnamed: C29.1, R33.2, R35.2, U5.2 (-)
unnamed: C29.2, R45.2, U5.1
unnamed: C33.1, R38.1, R41.1
unnamed: C34.1, R39.1, R45.1
unnamed: C35.1, D9.2 (A), Q6.3 (G), R44.2
unnamed: C38.1, Q8.1 (G), R66.1, R67.2, R99.2
unnamed: C53.1, Q7.1 (G), R64.1, R65.2, R100.2
unnamed: D5.1 (K), Q1.3 (D), R25.1
unnamed: D6.1 (K), Q2.3 (D), R26.1
unnamed: D8.1 (K), Q7.3 (D), R53.1
unnamed: D9.1 (K), Q8.3 (D), R54.1
unnamed: P9.T, R18.2
unnamed: P10.T, R17.2
unnamed: Q3.1 (D), R32.1
unnamed: Q4.1 (D), R33.1
unnamed: Q5.1 (D), R36.1
unnamed: Q6.1 (D), R37.1
unnamed: R34.1, R36.2, R38.2
unnamed: R35.1, R37.2, R39.2

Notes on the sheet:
best achievable noise will be -94dB since this is the Johnson noise with an impedance of 1Meg
The CODEC only presents optimal dynamic range and THD+N for PGA setting: -12dB to +6dB.
OpAmp Bypass caps
The gain calculation includes the RDSon value J110: RDSon = 18R
1, 1 1, 0 0, 1 0, 0
GAIN (dB)
0.0 6.0 15.0 20.4
GC2, GC1

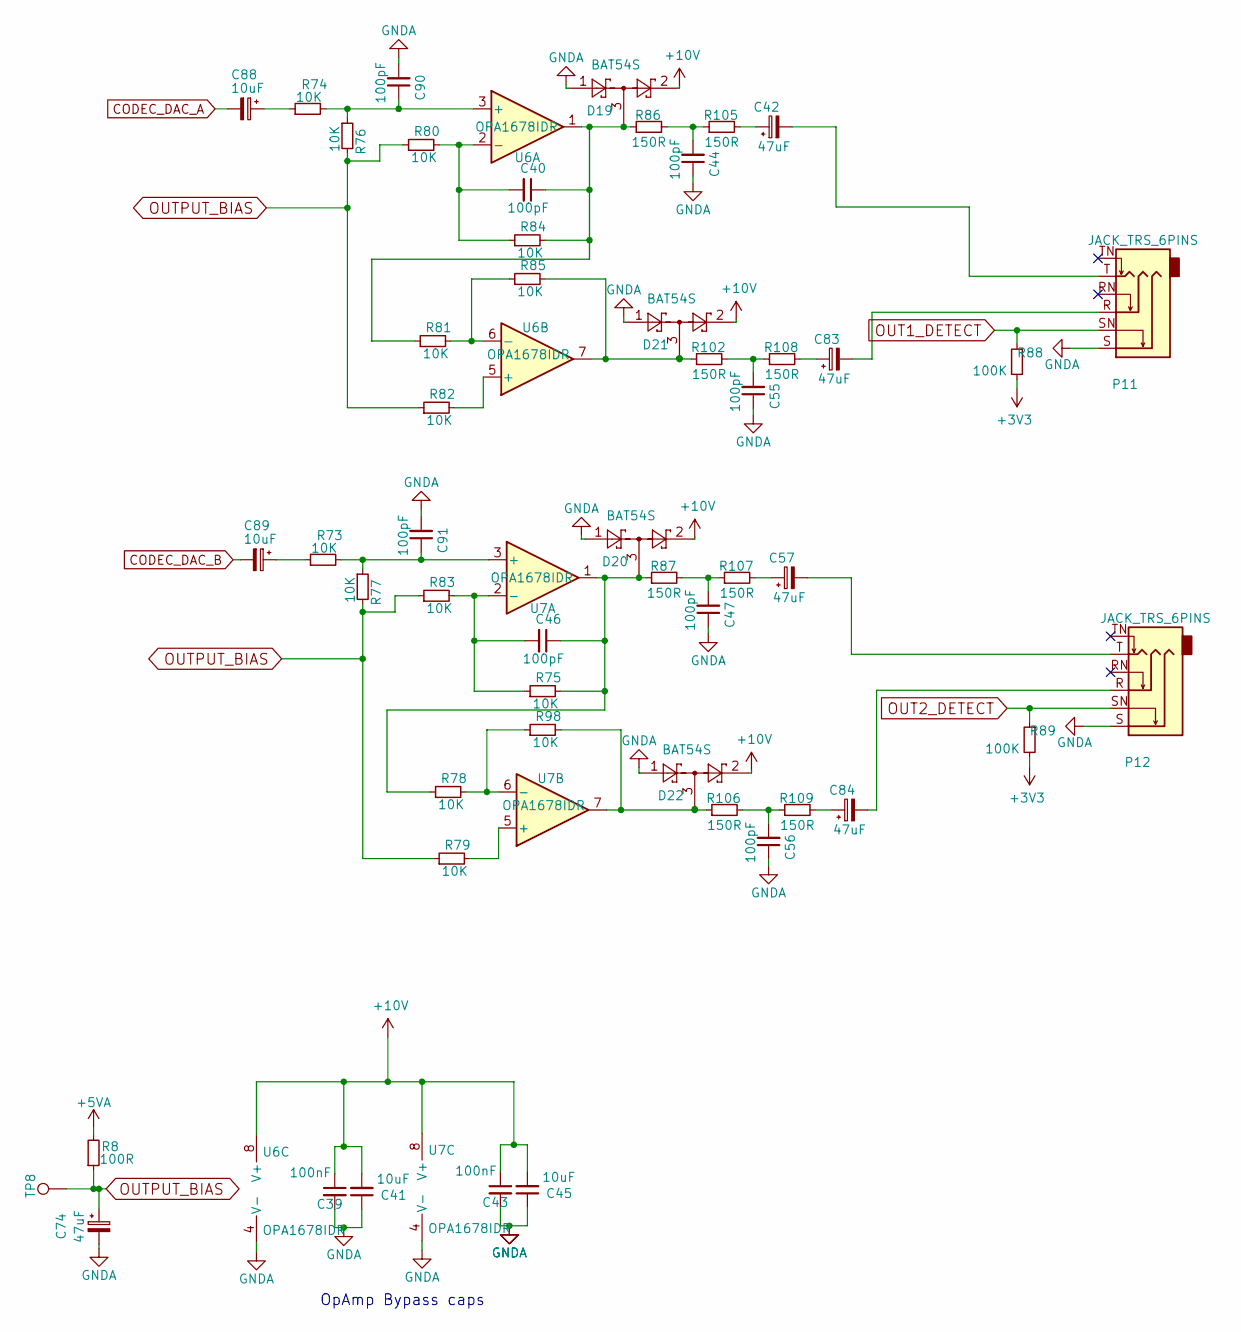
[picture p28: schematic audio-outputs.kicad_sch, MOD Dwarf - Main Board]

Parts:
C39, C43: 100nF; C_0603_1608Metric; MPN GCM188R71C104KA37D
C40, C44, C46, C47, C55, C56, C90, C91: 100pF; C_0603_1608Metric; MPN C0603C101J3GACTU
C41, C45: 10uF; C_0805_2012Metric; MPN GRM219R61E106KA12D
C42, C57, C74, C83, C84: 47uF; CP_Elec_5x5.4; MPN EDK476M016A9DAA
C88, C89: 10uF; CP_Elec_4x5.7; MPN EEE-HB1C100R
D19, D20, D21, D22: BAT54S; SOT-23; MPN BAT54SFILM
P11, P12: JACK_TRS_6PINS; Jack_3.5mm_Neutrik_NMJ6HCD2_Horizontal; MPN NYS215
R8: 100R; R_0603_1608Metric; MPN RT0603DRD07100RL
R73, R74, R75, R76, R77, R78, R79, R80, R81, R82, R83, R84, R85, R98: 10K; R_0603_1608Metric; MPN RR0816P-103-D
R86, R87, R102, R105, R106, R107, R108, R109: 150R; R_0603_1608Metric; MPN RC0603FR-07150RL
R88, R89: 100K; R_0603_1608Metric; MPN RMCF0603JT100K
TP8: TestPoint; TestPoint_Pad_D2.0mm
U6, U7: OPA1678IDR; SOIC-8_3.9x4.9mm_P1.27mm; MPN OPA1678IDR

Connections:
+5VA: R8.2; also elsewhere on the board
+10V: C39.1, C41.2, C43.1, C45.2, D19.2, D20.2, D21.2, D22.2, U6.8 (V+), U7.8 (V+); also elsewhere on the board
CODEC_DAC_A: C88.2; also elsewhere on the board
CODEC_DAC_B: C89.2; also elsewhere on the board
GNDA: C39.2, C41.1, C43.2, C44.1, C45.1, C47.1, C55.1, C56.1, C74.2, C90.2, C91.2, D19.1, D20.1, D21.1, D22.1, P11.S, P12.S, U6.4 (V-), U7.4 (V-); also elsewhere on the board
unnamed: C40.1, D19.3, R81.1, R84.2, R86.1, U6.1
unnamed: C40.2, R80.2, R84.1, U6.2 (-)
unnamed: C42.1, R105.2
unnamed: C42.2, P11.T
unnamed: C44.2, R86.2, R105.1
unnamed: C46.1, D20.3, R75.2, R78.1, R87.1, U7.1
unnamed: C46.2, R75.1, R83.2, U7.2 (-)
unnamed: C47.2, R87.2, R107.1
unnamed: C55.2, R102.2, R108.1
unnamed: C56.2, R106.2, R109.1
unnamed: C57.1, R107.2
unnamed: C57.2, P12.T
unnamed: C83.1, R108.2
unnamed: C83.2, P11.R
unnamed: C84.1, R109.2
unnamed: C84.2, P12.R
unnamed: C88.1, R74.1
unnamed: C89.1, R73.1
unnamed: C90.1, R74.2, R76.1, U6.3 (+)
unnamed: C91.1, R73.2, R77.1, U7.3 (+)
unnamed: D21.3, R85.2, R102.1, U6.7
unnamed: D22.3, R98.2, R106.1, U7.7
unnamed: R78.2, R98.1, U7.6 (-)
unnamed: R79.2, U7.5 (+)
unnamed: R81.2, R85.1, U6.6 (-)
unnamed: R82.2, U6.5 (+)
OUT1_DETECT: P11.SN, R88.1; also elsewhere on the board
OUT2_DETECT: P12.SN, R89.1; also elsewhere on the board
OUTPUT_BIAS: C74.1, R8.1, R76.2, R77.2, R79.1, R80.1, R82.1, R83.1, TP8.1

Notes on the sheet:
OpAmp Bypass caps

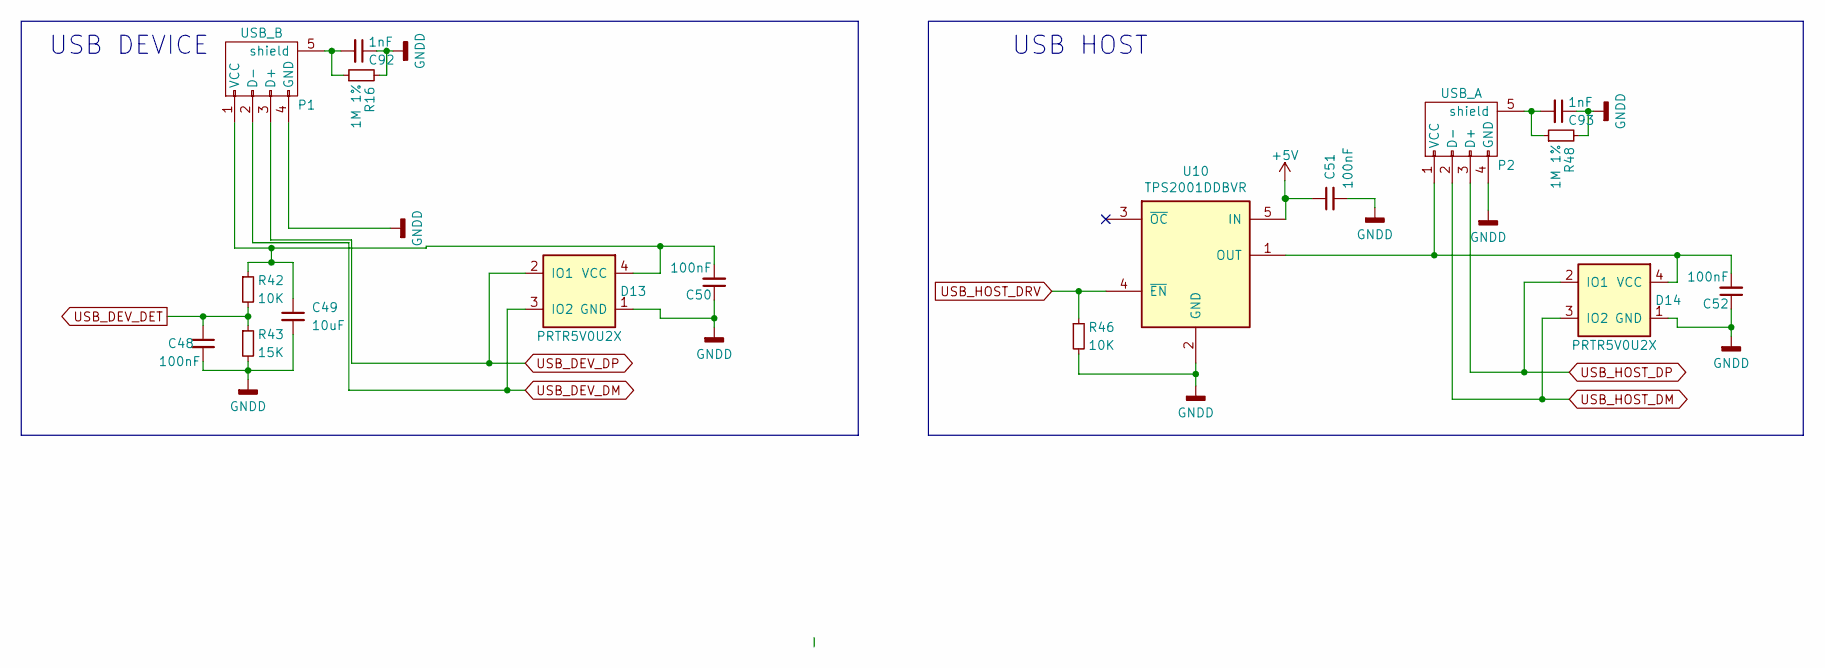
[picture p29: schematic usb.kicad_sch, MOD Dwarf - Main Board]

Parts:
C48, C50, C51, C52: 100nF; C_0603_1608Metric; MPN GCM188R71C104KA37D
C49: 10uF; C_0805_2012Metric; MPN GRM219R61E106KA12D
C92, C93: 1nF; C_0603_1608Metric; MPN C0603X7R500-103KNP
D13, D14: PRTR5V0U2X; SOT-143; MPN PRTR5V0U2X,215
P1: USB_B; USB_B_OST_USB-B1HSxx_Horizontal; MPN 61729-1011BLF
P2: USB_A; USB_A_Vertical; MPN KUSBX-SLAS1N-B
R16, R48: 1M 1%; R_0603_1608Metric; MPN RT0603BRD071ML
R42, R46: 10K; R_0603_1608Metric; MPN RR0816P-103-D
R43: 15K; R_0603_1608Metric; MPN RMCF0603JT15K0
U10: TPS2001DDBVR; SOT-23-5; MPN TPS2001DDBVR

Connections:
+5V: C51.1, U10.5 (IN); also elsewhere on the board
GNDD: C48.2, C49.2, C50.1, C51.2, C52.1, C92.1, C93.1, D13.1 (GND), D14.1 (GND), P1.4 (GND), P2.4 (GND), R16.2, R43.2, R46.2, R48.2, U10.2 (GND); also elsewhere on the board
unnamed: C49.1, C50.2, D13.4 (VCC), P1.1 (VCC), R42.1
unnamed: C52.2, D14.4 (VCC), P2.1 (VCC), U10.1 (OUT)
unnamed: C92.2, P1.5 (shield), R16.1
unnamed: C93.2, P2.5 (shield), R48.1
USB_DEV_DET: C48.1, R42.2, R43.1; also elsewhere on the board
USB_DEV_DM: D13.3 (IO2), P1.2 (D-); also elsewhere on the board
USB_DEV_DP: D13.2 (IO1), P1.3 (D+); also elsewhere on the board
USB_HOST_DM: D14.3 (IO2), P2.2 (D-); also elsewhere on the board
USB_HOST_DP: D14.2 (IO1), P2.3 (D+); also elsewhere on the board
USB_HOST_DRV: R46.1, U10.4 (~EN); also elsewhere on the board

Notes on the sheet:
USB DEVICE
USB HOST

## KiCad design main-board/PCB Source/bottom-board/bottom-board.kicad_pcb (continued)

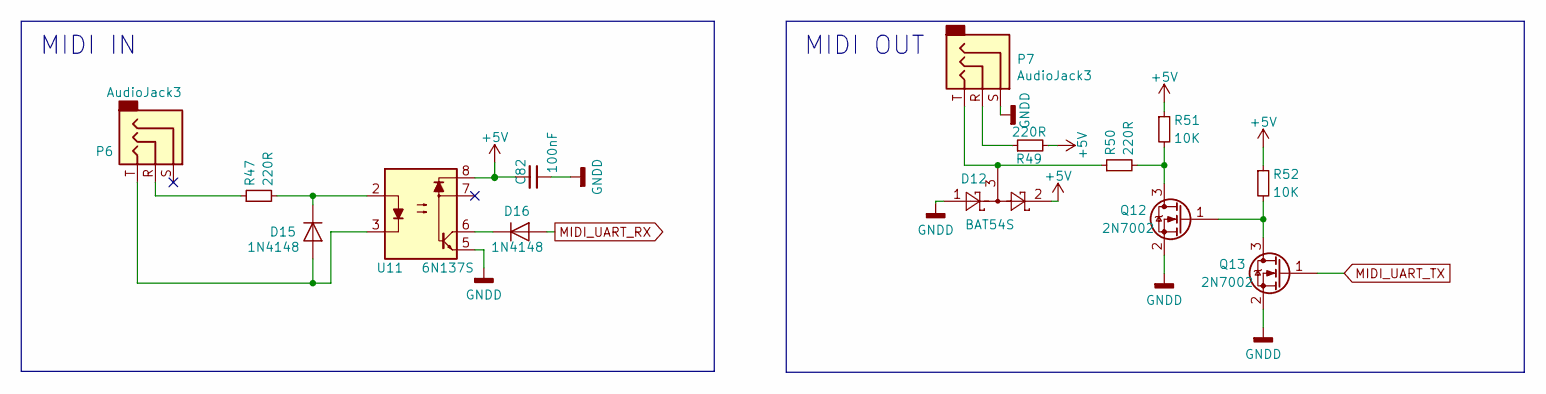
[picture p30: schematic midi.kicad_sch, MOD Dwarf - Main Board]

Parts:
C82: 100nF; C_0603_1608Metric; MPN GCM188R71C104KA37D
D12: BAT54S; SOT-23; MPN BAT54SFILM
D15, D16: 1N4148; D_SOD-323; MPN 1N4148WS
P6, P7: AudioJack3; Jack_3.5mm_CUI_SJ-3523-SMT_Horizontal; MPN SJ-3523-SMT-TR
Q12, Q13: 2N7002; SOT-23; MPN 2N7002P,215
R47, R49, R50: 220R; R_0603_1608Metric; MPN RC0603FR-07220RL
R51, R52: 10K; R_0603_1608Metric; MPN RR0816P-103-D
U11: 6N137S; MPN 6N137S

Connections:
+5V: C82.2, D12.2, R49.2, R51.1, R52.1, U11.8; also elsewhere on the board
GNDD: C82.1, D12.1, P7.S, Q12.2 (S), Q13.2 (S), U11.5; also elsewhere on the board
MIDI_UART_RX: D16.2 (A); also elsewhere on the board
MIDI_UART_TX: Q13.1 (G); also elsewhere on the board
unnamed: D12.3, P7.T, R50.1
unnamed: D15.1 (K), R47.2, U11.2
unnamed: D15.2 (A), P6.T, U11.3
unnamed: D16.1 (K), U11.6
unnamed: P6.R, R47.1
unnamed: P7.R, R49.1
unnamed: Q12.1 (G), Q13.3 (D), R52.2
unnamed: Q12.3 (D), R50.2, R51.2

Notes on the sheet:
MIDI OUT
MIDI IN

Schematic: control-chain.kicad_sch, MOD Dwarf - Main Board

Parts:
C54, C62: 100nF; C_0603_1608Metric; MPN GCM188R71C104KA37D
C61: 10uF; CP_Elec_4x5.7; MPN EEE-HB1C100R
P13: RJ45; Ethernet_Jack_54602-908LF; MPN 54602-908LF
R55, R56, R63: 100R; R_0603_1608Metric; MPN RT0603DRD07100RL
R57, R58: 10K; R_0603_1608Metric; MPN RR0816P-103-D
R59, R60, R61, R62: 56R; R_0603_1608Metric; MPN CRGCQ0603F56R
U12: ISL83491; SOIC-14_3.9x8.7mm_P1.27mm; MPN ISL83491IBZ

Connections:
+12V: C61.1, C62.1, P13.4, P13.5; also elsewhere on the board
CHAIN_UART_DE: R58.1, U12.4 (DE); also elsewhere on the board
CHAIN_UART_RE: R57.2, U12.3 (~RE); also elsewhere on the board
CHAIN_UART_RX: R56.2; also elsewhere on the board
CHAIN_UART_TX: R55.2; also elsewhere on the board
GNDD: C54.2, C61.2, C62.2, P13.7, P13.8, R58.2, U12.6 (GND), U12.7 (GND); also elsewhere on the board
unnamed: R55.1, U12.5 (DI)
unnamed: R56.1, U12.2 (RO)
unnamed: R59.2, U12.12 (A)
unnamed: R60.2, U12.11 (~B)
unnamed: R61.2, U12.9 (Y)
unnamed: R62.2, U12.10 (~Z)
RS485_RX+: P13.3, R59.1, R63.1
RS485_RX-: P13.6, R60.1, R63.2
RS485_TX+: P13.1, R61.1
RS485_TX-: P13.2, R62.1

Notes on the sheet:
This port is NOT used for ethernet, but for a serial protocol that includes power over the RJ-45 connector

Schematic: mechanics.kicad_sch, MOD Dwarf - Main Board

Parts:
FID1, FID2, FID3: FIDUCIAL; fiducial_in-circuit
H1, H2, H3, H4: HOLE; Hole_3.5mm
H6, H7: MountingHole_Pad; MountingHole_3.2mm_M3_DIN965_Pad; MPN 9774030243R

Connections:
GNDD: H6.1, H7.1; also elsewhere on the board

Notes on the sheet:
SOM Mounting holes

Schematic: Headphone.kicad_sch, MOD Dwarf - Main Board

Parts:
C63, C64, C65, C66: 10uF; CP_Elec_4x5.7; MPN EEE-HB1C100R
C67, C69: 10uF; C_0805_2012Metric; MPN GRM219R61E106KA12D
C68, C85, C86: 100nF; C_0603_1608Metric; MPN GCM188R71C104KA37D
C70, C71: 100uF; CP_Elec_6.3x7.7; MPN 107SML016M
D17, D18: BAT54S; SOT-23; MPN BAT54SFILM
P14: AudioJack3; Jack_3.5mm_CUI_SJ-3523-SMT_Horizontal; MPN SJ-3523-SMT-TR
Q9, Q10: MMBFJ110; SOT-23; MPN MMBFJ110
R90, R91: 1M 1%; R_0603_1608Metric; MPN RT0603BRD071ML
R92, R93: 56K; R_0603_1608Metric; MPN RMCF0603FT56K0
R94, R95: 22R; R_0603_1608Metric; MPN RMCF0603JT22R0
R96, R97: 75K 1%; R_0603_1608Metric; MPN RR0816P-753-D
R103, R104: 6R8; R_0603_1608Metric; MPN RMCF0603FT6R80
R110, R111: 1M 1%; R_0603_1608Metric; MPN DO NOT PLACE
U8: LM4811; TSSOP-10_3x3mm_P0.5mm; MPN LM4811MM/NOPB

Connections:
+5VA: C67.2, C68.1, D17.2, D18.2, Q9.1 (D), Q10.1 (D), R110.2, R111.2, U8.10 (VDD); also elsewhere on the board
CODEC_DAC_A: C63.1; also elsewhere on the board
CODEC_DAC_B: C64.1; also elsewhere on the board
GNDA: C67.1, C68.2, C69.2, C85.1, C86.1, D17.1, D18.1, P14.S, R90.1, R91.1, R92.1, R93.1, R96.1, R97.1, U8.5 (GND), U8.7 (SHDN); also elsewhere on the board
HP_CLOCK: R95.1; also elsewhere on the board
HP_VOL: R94.1; also elsewhere on the board
unnamed: C63.2, Q9.3 (G), R90.2, R111.1
unnamed: C64.2, Q10.3 (G), R91.2, R110.1
unnamed: C65.1, Q9.2 (S), R92.2
unnamed: C65.2, U8.8 (VIN2)
unnamed: C66.1, Q10.2 (S), R93.2
unnamed: C66.2, U8.2 (VIN1)
unnamed: C69.1, U8.3 (BYPASS)
unnamed: C70.1, C85.2, D17.3, U8.1 (VOUT1)
unnamed: C70.2, R96.2, R103.2
unnamed: C71.1, C86.2, D18.3, U8.9 (VOUT2)
unnamed: C71.2, R97.2, R104.1
unnamed: P14.R, R104.2
unnamed: P14.T, R103.1
unnamed: R94.2, U8.6 (UP/DN)
unnamed: R95.2, U8.4 (CLOCK)

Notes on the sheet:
Max power 105mW
LM4811 has adjustable gain of -33dB to +12dB, this is applied to the main out signal
Minimal load of 16 ohm with 0.1% THD+N

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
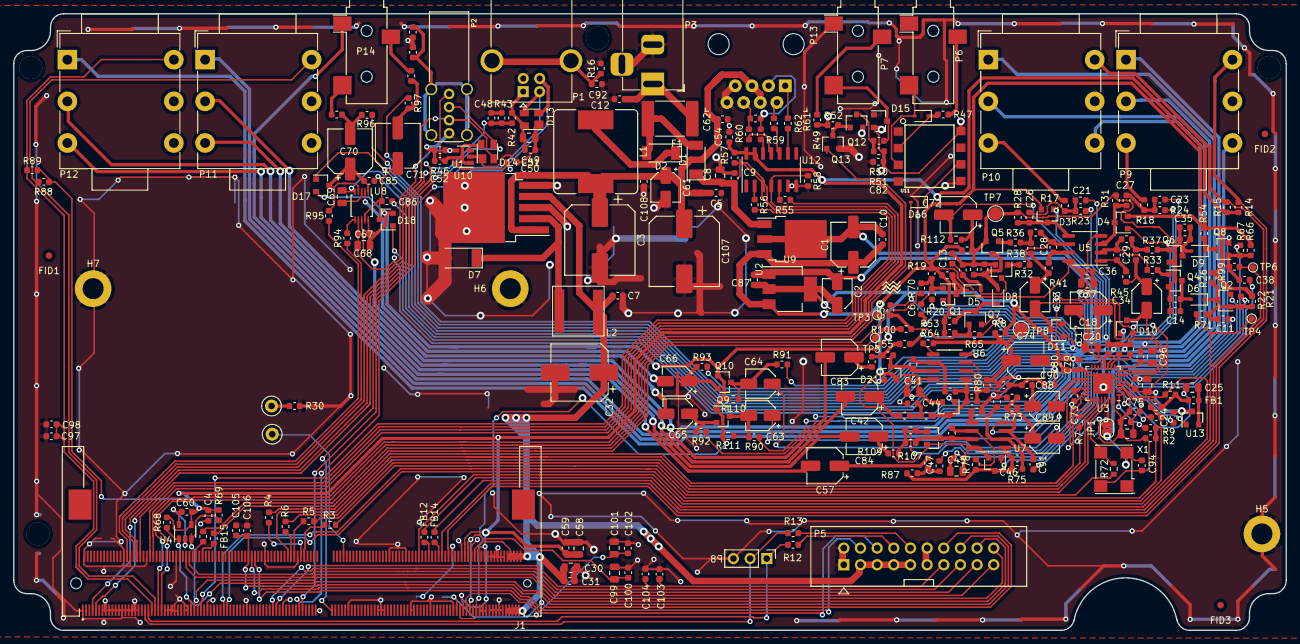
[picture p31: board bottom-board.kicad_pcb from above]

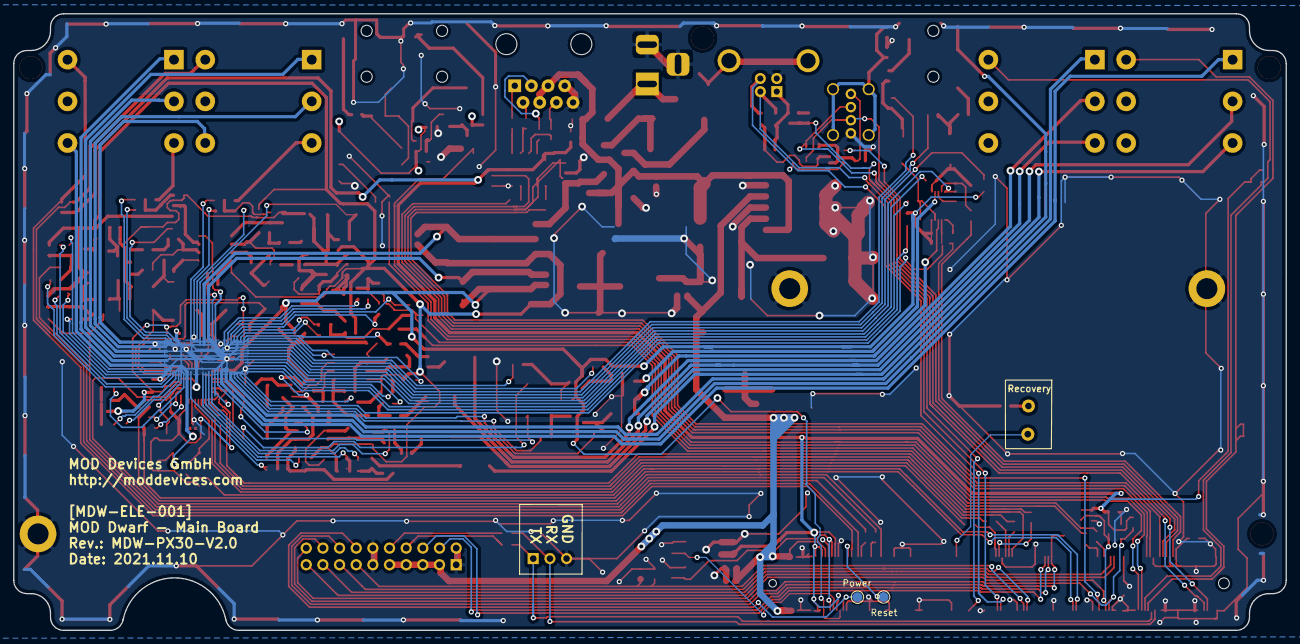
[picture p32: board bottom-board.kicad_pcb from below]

Board: 4 copper layers, 194.0 x 94.0 mm, 311 parts (2 on the bottom side), 179 nets.

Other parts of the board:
P5: HMI_DATA; Pin_Header_Straight_2x10_Shrouded
Power: TestPoint; TestPoint_Pad_D1.5mm
Reset: TestPoint; TestPoint_Pad_D1.5mm

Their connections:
+5V: P5.3, P5.5, P5.7, P5.9; also elsewhere on the board
GNDD: P5.1, P5.2, P5.11, P5.12; also elsewhere on the board
HMI_ISP_ENABLE: P5.13; also elsewhere on the board
HMI_RESET: P5.15; also elsewhere on the board
HMI_RFU_RX: P5.6; also elsewhere on the board
HMI_RFU_TX: P5.4; also elsewhere on the board
HMI_UART_RX: P5.19; also elsewhere on the board
HMI_UART_TX: P5.17; also elsewhere on the board
unnamed 122: P5.8; also elsewhere on the board
unnamed 123: P5.10; also elsewhere on the board
PM_LEDS_OE: P5.16; also elsewhere on the board
PM_LEDS_SCL: P5.18; also elsewhere on the board
PM_LEDS_SDA: P5.20; also elsewhere on the board
POWER_BUTTON: P5.14, Power.1; also elsewhere on the board
RESET_BUTTON: Reset.1; also elsewhere on the board

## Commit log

2019-12-15 add main board + documentation
    [BottomBoard with components.DXF, PIN_MAPPING_PX30.xlsx, TopBoard with components 12.12.2019.DXF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]
2019-12-19 add fabrication files bottom board
    [audio-codec.sch, audio-inputs.sch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]
2019-12-19 change USB host connector
    [bottom-board-B_Cu.gbr, bottom-board-B_Mask.gbr, bottom-board-B_Paste.gbr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]
2020-01-06 small changes
    [bottom-board.kicad_pcb]
2020-01-06 added controller board
    [BOM[MOD-ELE-002].xls, Pick Place for mod_duo_dwarf.csv, [1]-PWR_12VIN.SchDoc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]
2020-01-08 moved USB host 1mm down
2020-01-08 reposistioned screw holes
2020-01-08 reposistioned PSU filtering caps
    [bottom-board.kicad_pcb, power.sch]
2020-01-09 change on MIDI input to TRS type A standart + cleanup
    [bottom-board.kicad_pcb, midi.sch]
2020-08-05 update bottomboard
    [BOM[MOD-ELE-002].xls, Dwarf GR30 SoM pinout.ods, Headphone.sch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]
2020-10-30 rev 0.0.3
    [200923_Bottom Board_[v0.14].DXF, BOM[MOD-ELE-002].xls, Dwarf GR30 SoM pinout.ods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]
2020-11-25 change design to 4 layer PCB
    [Headphone.sch, PIN_MAPPING_PX30.xlsx, audio-codec.sch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]
2020-11-27 change posistion of connectors a tiny bit, now locked in place
    [201126_Bottom Board_[v0.14].DXF, Headphone.sch, bottom-board.kicad_pcb]
2020-11-27 update BOM and schematic
    [bottom-board.csv]
2020-11-27 update manufactering data
    [bottom-board-B_Cu.gbr, bottom-board-B_Mask.gbr, bottom-board-B_Paste.gbr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]
2020-12-23 supply topboard with 5V instead of 12
    [bottom-board.kicad_pcb, coreboard.sch]
2020-12-23 replace EOL usb power regulator
2020-12-23 change inp cap to 100pF instead of 100nF, also update silkscreen
    [bottom-board.csv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]
2020-12-23 update production files
    [bottom-board-B_Cu.gbr, bottom-board-B_Mask.gbr, bottom-board-B_Paste.gbr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]
2020-12-23 minor cleanup
    [audio-inputs.sch, bottom-board.kicad_pcb, coreboard.sch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]
2021-09-03 cleanup BOM lines
    [Headphone.sch, audio-codec.sch, audio-inputs.sch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]
2021-09-03 change input bias from 5 to 6 volts
    [audio-inputs.sch, bottom-board.kicad_pcb]
2021-09-03 change recovery pads to holes, easier on production
    [bottom-board.kicad_pcb, coreboard.sch]
2021-09-03 give analog bias to PX30 analog reference
    [bottom-board.kicad_pcb, coreboard.sch]
2021-09-06 fix pin mapping excel
    [PIN_MAPPING_PX30.xlsx, PIN_MAPPING_PX30_Dwarf.xlsx]
2021-09-06 change rev
    [Headphone.sch, audio-codec.sch, audio-inputs.sch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]
2021-09-13 increase PCB size by 0.5mm, move midi connectors up by 0.5mm
    [2021.09.09_[v1.0]MDW-PCB_001-Cut Only.DXF, 2021.09.09_[v1.0]MDW-PCB_001.DXF]
2021-09-13 structure documentation folder
    [200923_Bottom Board_[v0.14].DXF, 201126_Bottom Board_[v0.14].DXF, 2021.09.09_[v1.0]MDW-PCB_001-Cut Only.DXF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]
2021-09-14 move headphone jack up 0.5mm
    [bottom-board.kicad_pcb]
2021-09-14 move mini jacks down 0.1mm
    [bottom-board.kicad_pcb]
2021-09-14 swap headphone L/R
    [bottom-board.kicad_pcb]
2021-09-29 add new power filter components to schematic
    [bottom-board.kicad_pcb]
2021-09-29 increase som filter caps
    [coreboard.sch, power.sch]
2021-09-29 update PCB, add noisefix components
    [Headphone.sch, bottom-board.kicad_pcb]
2021-09-29 clean some traces
2021-10-08 update fabrication data
    [Headphone.sch, audio-codec.sch, audio-inputs.sch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]
2021-10-08 clean bottomboard, upload fabrication
    [bottom-board-B_Cu.gbr, bottom-board-B_Mask.gbr, bottom-board-B_Paste.gbr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]
2021-10-27 change input bias 5->6V, reduce harmonics
    [DeltaProto SBOM MOD_DWARF_1.05.xlsx, Headphone.sch, audio-inputs.sch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]
2021-11-10 change MPN of U10 and U12
    [audio-inputs.sch, power.sch]
2021-11-10 change JFET MPN
    [Headphone.sch, audio-inputs.sch, control-chain.sch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]
2021-11-11 correct MPN R112, U6 and U7
    [audio-outputs.sch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]
2021-12-20 change bottom to main-board in root folder, reversion from 1.05 to 2.0
    [Headphone.sch, SPDIF.sch, audio-codec.sch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]
2022-04-27 update fabrication files
    [Headphone.kicad_sch, LSF0204DPWR.step, MDW-PCB_001_V2.0_REV-B-220406.DXF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]
2022-05-03 mainboard: add bias buffer, update MPNs, clean schematic
    [Headphone.kicad_sch, audio-codec.kicad_sch, audio-inputs.kicad_sch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]
2022-05-04 mainboard: modify silkscreen
    [Headphone.kicad_sch, audio-inputs.kicad_sch, audio-outputs.kicad_sch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]
2022-05-04 controllerbard: change footswitches and main connector
    [BOM[MOD-ELE-002].xls, Pick Place for mod_duo_dwarf.csv, [2]-MCU_LPC1778FBD144.SchDoc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]
2023-02-15 icnrease diode footprint, add extra input cap option
    [audio-inputs.kicad_sch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]
2023-02-22 Tweak controller board overlay
    [mod_duo_dwarf.GBL, mod_duo_dwarf.GBO, mod_duo_dwarf.GBP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]
2023-02-22 updatte mainboard silkscreen
    [bottom-board-B_Cu.gbr, bottom-board-B_Mask.gbr, bottom-board-B_Paste.gbr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]
2024-10-06 README: fix link to KiCAD homepage
